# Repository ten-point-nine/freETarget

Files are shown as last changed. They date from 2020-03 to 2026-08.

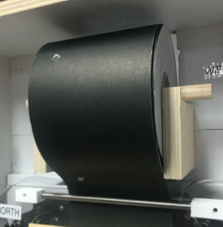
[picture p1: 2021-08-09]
Documentation/Pictures/Witness Paper Roll.jpg

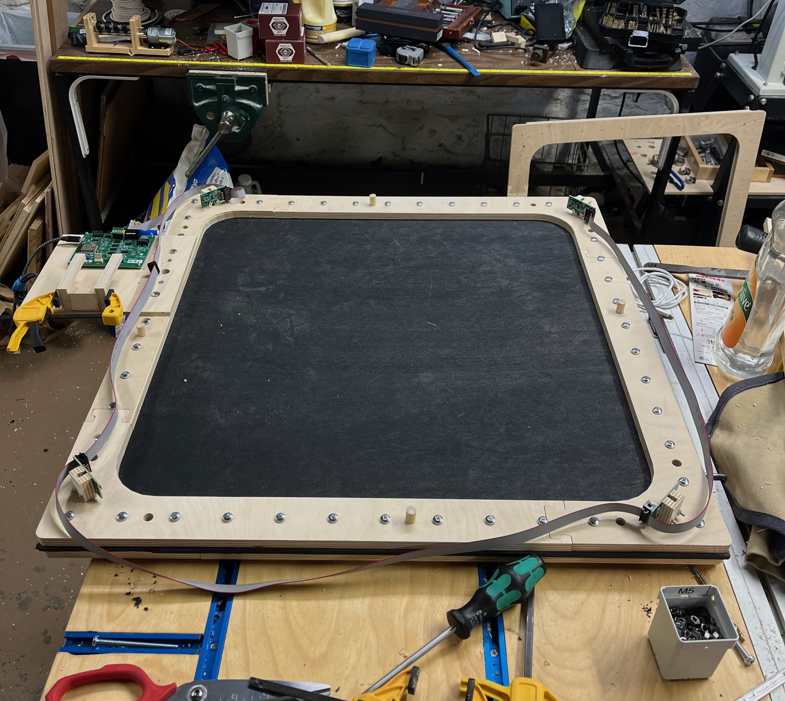
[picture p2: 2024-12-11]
Documentation/Pictures/Illustrations/Pistol Assembly 1.png

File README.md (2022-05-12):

# freETarget

**What is freETarget?**

freETarget is an 'electronic target' (or E-Target) for small calibre (air) rifles and pistols. It uses microphones arranged around the target card to detect the impact of the bullet on the paper and then calculates the point of impact using triangulation. The basic principles are detailed in 

It does this using relatively inexpensive electronics, based around the Arduino open-source ecosystem. This means you can have your own E-Target for a lot less than the current commercial offerings. How much exactly depends mostly on you own skill and effort. You can source and build everything yourself including the electronics and have a system running for around $200. If you want to have the electronics ready made, this price will be around $300.

And yes, we realize this isn't exactly 'free', but it's still pretty cheap for such a system.

Check out the BOM for the electronics to get a feel for the costs of that part. The enclosure can be as expensive as you want, in it's cheapest form it can be made of sturdy cardboard!

The second part of the solution is actually free and consists of the excellent frETarget software. This software offers incredible functionality and is maintained free of charge! See something you want changed, it's open-source, feel free to improve (and please share back).

**How do I work with the firmware?**

The firmware is written for an Arduino and the Arduino IDE.  This makes it pretty accessible for anybody in the world.  Lots of aftermarket support

The software starts with freETarget.ino.  This is the startup and main control loop.  The other files, gpio.ino are helper files to interface to various hardware elements.  The heavy lifting is done buy the file compute_hit.ino.  

**I just want to build and upload the latest firmware**

You can always download the latest firmware from https://www.free-e-target.com/downloads and upload the HEX file through the freETarget PC software. 

If you want to build from source, just open the freETarget.ino file located in the freETarget subfolder in the Arduino IDE. You won't see any code, but hitting Verify and upload will work just the same.

**I want to work on the PC source code**

Great! The PC software is wrtten in C# using Visual Studio.  You can download a free version from the Microsoft web site.  

**How do I work with the hardware?**

The hardware is maintained in the electronics subfolder of the GIT repository and is developed in KiCad. Download and install KiCad EDA to work on the schematics and PCB's.

**Tell me more**

The documentation folder contains all of the documents that have been created for this project.

   **Theory of Operation** details the algorithm and hardware used to detect the shot location

   **Building freETarget** is the instructions for assembling a target

   **Mechanical Folder** contains all of the mechanical drawings to complete your system

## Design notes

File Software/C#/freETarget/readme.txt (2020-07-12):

freETarget software

the program uses 2 external libraries: System.Data.SQLite and PdfSharp. Use Visual Studio NuGet Packages tool to import these 2 libraries into the workspace.
The Setup project will build an installation kit for the software.

PC software for displaying data from the electronic target received over the COM serial port. The PC connects to the target using a USB cable. 
-	Supports air pistol and air target events; practice, match and final
-	Displays score in integer or decimal format
-	Configurable 40 or 60 shots matches
-	Configurable display of shots – all shots in the session or just current series
-	Big time display for the current session
-	Mean Point of Impact (MPI) , Mean radius and group size with direction arrow indicating each shot’s position; drawing of the MPI and mean group  on the target
-	Calibration control of shots
-	Zoom of target display
-	Numbering of shots; last shot has a distinct color for easy recognition
-	Virtual Range Officer – voice commands in the final events
-	Journal where all the sessions are automatically saved; sessions are saved per user
-	Each session can be loaded in the main window; the session’s series can be inspected by clicking the grid display
-	Statistical graphs for all sessions in an event type
-	Each session has its own diary entry page for noting impressions of the training
-	PDF generated for each session with all the results
-	Visually distinctive “not connected” status
- 	Variable target distance (3 to 10 meters)

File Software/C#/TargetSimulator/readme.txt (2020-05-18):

The target simulator is created to simulate the arduino sending shot commands over a serial port (USB).
In order to simulate the conection between 2 ports, a virtual null-modem cable software is to be used : i recomend com0com from http://com0com.sourceforge.net/. At installation, choose to setup 2 paired COM ports.

After install, connect the TargetSimulator to one COM, and freETarget software to the other and than use the buttons in the simulator to send shot commands.

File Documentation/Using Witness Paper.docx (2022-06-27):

# freETarget

Application Note: Using Witness Paper

SUMMARY

This application note describes how to add witness paper to freETarget.

- Witness Paper
- Paper Feed
- Switches
- Configuration
- Bill of Materials

INTRODUCTION

freETarget has the facility to add witness paper drive to the basic target. Witness paper ensures that there is always a complete target to put holes into and get a reliable shot location.

Using witness paper requires four parts:

- Witness Paper Holder and Guide
- Paper Feed
- Paper Feed Switches
- Software Configuration

Each of these topics are discussed separately

WITNESS PAPER and GUIDE

Witness paper comes in two widths; 90mm and 165mm. The 90mm width is typically used for rifle shooting, while the 165 is for pistol events. The choice is up to the user, but 90mm is more than sufficient to fill in the black portion of a pistol target.

An example of a paper holder is shown in Figure 1. The witness paper holder is wide enough to fit a 92mm paper roll. This provides a standard 90mm roll with 1mm of clearance on each side. In this example, the witness paper rolls under a round (5mm) bar that lines the paper up with the target. Because of this bar, the witness paper is on a free rolling mount that lets the roll adjust its position as the paper is used.


Figure 1: Witness Paper Holder

PAPER DRIVE

The paper drive in Figure 2, 3, and 4 is made from several components.

- Frame
  - Base
  - Left Pinch Roller Bearing
  - Right Pinch Roller Bearing
- Motor
- Coupling
- Drive Shaft
- Pinch Rollers
- Tear Bar

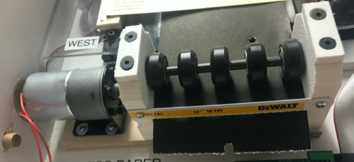
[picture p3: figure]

Figure 2: Paper Drive Assembly

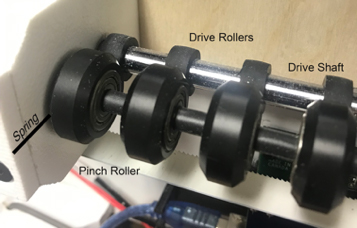
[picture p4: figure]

Figure 2A: Drive Rollers

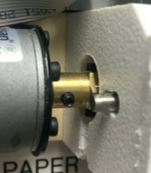
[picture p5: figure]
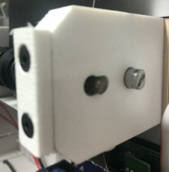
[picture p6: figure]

Figure 3: Motor Coupling | Figure 4: Pinch Roller Bearings

Construction

In this example, the base is made from 1/4” plywood, and the pinch roller bearings from PVC plastic.

Construction begins by sizing out the base plate needed to hold the motor, left pinch roller bearing, paper, and right pinch roller bearing. In this example the base plate is 18cm x 5cm,

Next the pinch roller bearings are cut from PVC plastic. PVC was chosen since it is naturally slippery and does not need any lubricant. In this example the bearings are 50mm x 65mm

Begin by locating the motor and motor mount on one side of the base plate. Next, mark the place where the drive shaft touches the bearing plates. Drill the holes for the drive shaft as seen in Figure 3.

The drive rollers purchased from Amazon come with a 6 mm arbor. Drill or cut the arbor out leaving just the rubber wheel. Slide the rubber wheel onto the 8mm drive shaft, this will require some force, but it can be done. Test fit the motor, drive shaft, and drive rollers. Assemble the pinch rollers onto the shaft and mark where they will need to be to fit against the drive shaft. Drill an oblong hold into both pinch roller bearings. Note that Figure 4 shows a slotted hole for the pinch rollers. This is done so that the pinch rollers can be pressed against the drive shaft when assembled.

Drill a hole through both pinch roller bearings for the spring to fit into.

Assemble the witness paper drive.

Testing

Cut a small length of witness paper and insert it into the drive. The slotted hole for the pinch rollers should be long enough that you can move the pinch roller away and slide in the paper. When the pinch rollers are in contact with the drive rollers the witness paper should not be able to be moved.

Apply power to the motor, does the witness paper move easily? You may find that the drive shaft binds in the mounting plates. If this happens, loosen the bolts holding the plates to the mount by ½ turn.

Wiring

A control to drive a witness paper roller is provided by the Motor Drive Pin. This pin provides a ground connection through a MOS-FET transistor.

The user has the option of turning on a DC motor for a period of time, or issuing pulses to a stepper motor controller. The number of pulses and the pulse duration is available from the setup page on the PC program. The duration of the motor control will be installation dependent and found by trial-and-error

A typical connection for a DC motor is shown in Figure 2.

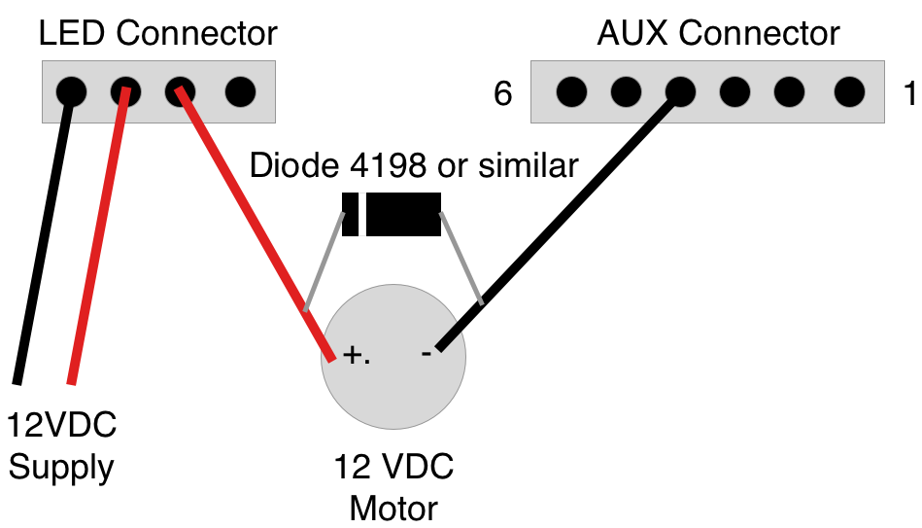
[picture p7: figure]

Figure 2: DC Motor Connection

IMPORTANT – Stepper Motor Control

The software provides the ability to pulse a stepper motor circuit for a given number of pulses and periods. The user must add a stepper motor interface such as A4988 available from Amazon to convert from pulses to motor phase drive

IMPORTANT – Feed Direction

The feed direction is determined by the motor polarity and the assembly of the parts. If the paper feed is backwards to the target, reverse the positive and negative motor leads.

PAPER FEED SWITCHES

The witness paper drive has provision for paper feed switches to advance the paper when loading. Figure 5 shows the switches, and Figure 6 shows the location on the DIP header. Figure 7 is a simple schematic of the switches and connection.

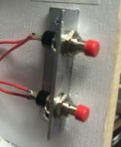
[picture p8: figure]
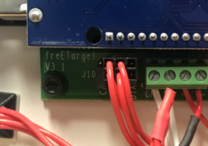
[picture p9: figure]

Figure 5: Paper Feed Switches | Figure 6: Wiring Connector – Uses DIP connection A and B

Figure 7: Switch Diagram

SOFTWARE CONFIGURATION

The witness paper needs the following configurations to be set as shown in Table 1

Table 1: Witness Paper Settings

Setting | Description | Typical Values
DC Motor
PAPER_TIME | Duration motor is on to advance paper | 500 ms (50)
Stepper Motor
STEP_COUNT | Number of steps to issue to motor | 25
STEP_TIME | Stepper motor ON time | 5
Switches
MFS | 0-16 Upper Switch | 1 – Paper Feed

BILL OF MATERIALS

Most of the materials on this list were obtained from Amazon simply for convenience.

Part | Description
Base | ¼” Plywood or similar
Left Roller Bracket | ½” PVC or similar
Right Roller Bracket | ½” PVC or similar
Pinch Roller Spring | 5mm dia x 50mm long Ballpoint pen springs could be used instead
Fasteners | Various screws to fit
Part | From Amazon.com
12VDC Motor, 110 RPM | https://www.amazon.com/gp/product/B08D3SSG55/ref=ppx_yo_dt_b_asin_title_o09_s00?ie=UTF8&psc=1
Motor Mount | https://www.amazon.com/gp/product/B089W6DCGV/ref=ppx_yo_dt_b_asin_title_o09_s00?ie=UTF8&psc=1
6-8mm coupling | https://www.amazon.com/gp/product/B06X99P2XK/ref=ppx_yo_dt_b_asin_title_o09_s00?ie=UTF8&psc=1
Pinch Roller | https://www.amazon.com/gp/product/B088BXFT44/ref=ppx_yo_dt_b_asin_title_o05_s00?ie=UTF8&psc=1
Drive Roller | https://www.amazon.com/gp/product/B088BXFT44/ref=ppx_yo_dt_b_asin_title_o00_s00?ie=UTF8&psc=1
8mm x 100 mm Drive Shaft | https://www.amazon.com/gp/product/B082ZNXBWS/ref=ppx_yo_dt_b_asin_title_o00_s00?ie=UTF8&psc=1
5mm x 100mm Pinch Roller Shaft | https://www.amazon.com/gp/product/B082ZNXBWS/ref=ppx_yo_dt_b_asin_title_o00_s00?ie=UTF8&psc=1
Feed Switches, Push Button Normally Open | https://www.amazon.com/Twidec-Colors-Momentary-Pre-soldered-PBS-110-X6C/dp/B07RPS2ZY3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

WHERE TO BUY WITNESS PAPER

Europe

Kreuger Targets. https://targets.krueger-shops.eu

North America

Orion Systems: Paper Roll for Athena NC Models (orionscoringsystem.com) (http://www.orionscoringsystem.com/orion/Product.aspx?ProductID=61)

Elite Scorer: Electronic target, Electronic targets shooting, Target scoring system (elitescorer.com) (https://www.elitescorer.com/ElectronicScoring-shooting.aspx?curr=USD)

Targets Canada: http://www.targets.ca/products/targets-target-systems-and-accessories

Make Your Own Witness Paper

For true Do-It-Yourself people, there are alternatives to commercially available witness paper

Black wallpaper – Available locally in paint supply stores

Black kraft paper – Example Amazon, https://www.amazon.com/RUSPEPA-Black-Kraft-Paper-Roll/dp/B07MNVSB16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

Heat treated cash register paper – Use standard cash register paper and iron it to turn it black

Cut down witness paper – Cut 90mm witness paper in half using a band saw or similar tool

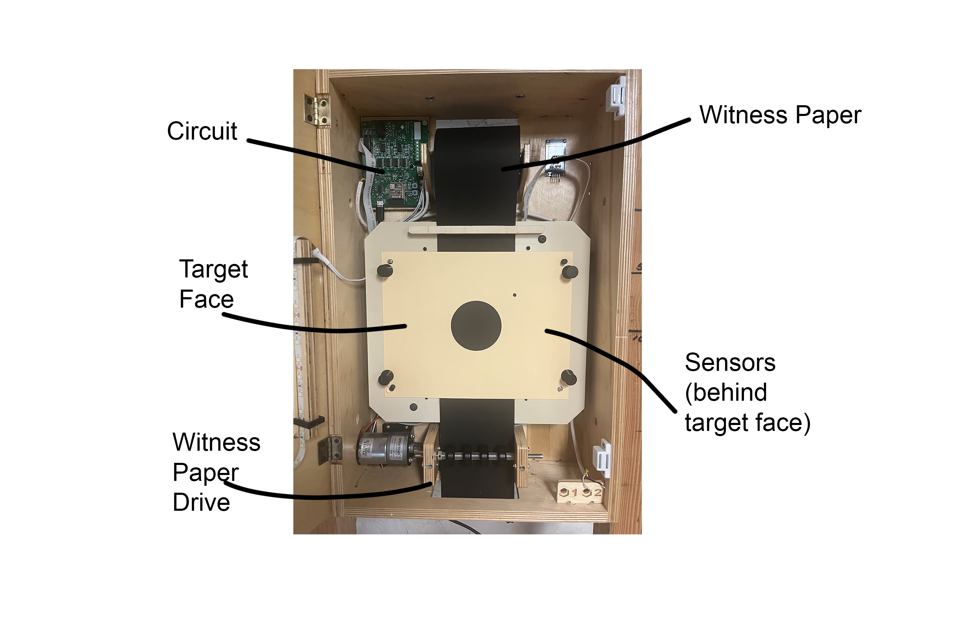
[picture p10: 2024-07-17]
Documentation/Pictures/Target Schematic.png

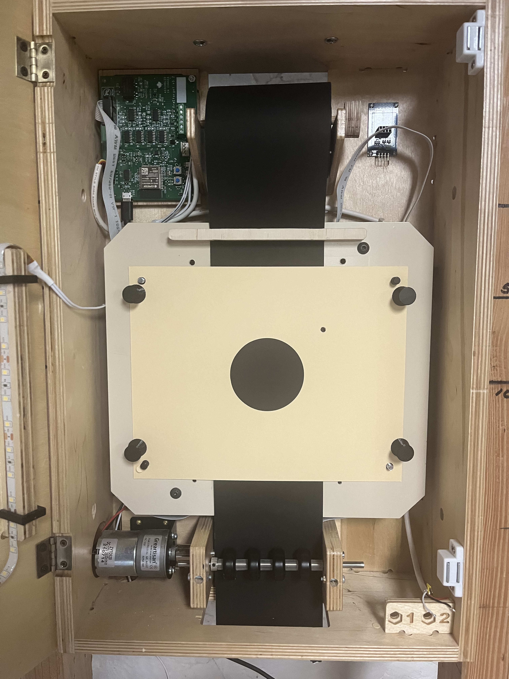
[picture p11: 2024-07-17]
Documentation/Pictures/Schematic.jpg

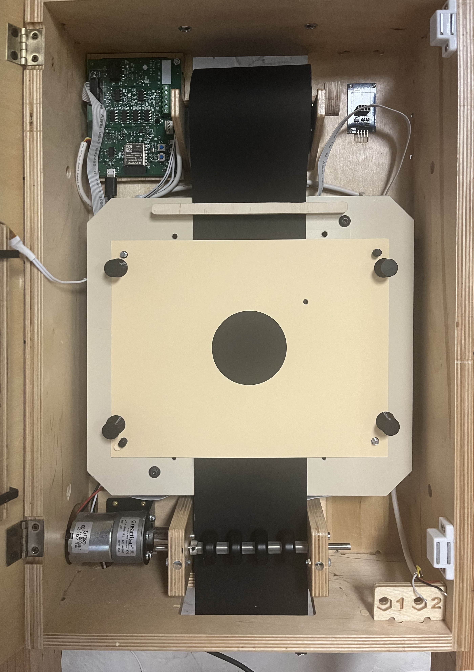
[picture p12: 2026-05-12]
Documentation/Pictures/Schematic.png

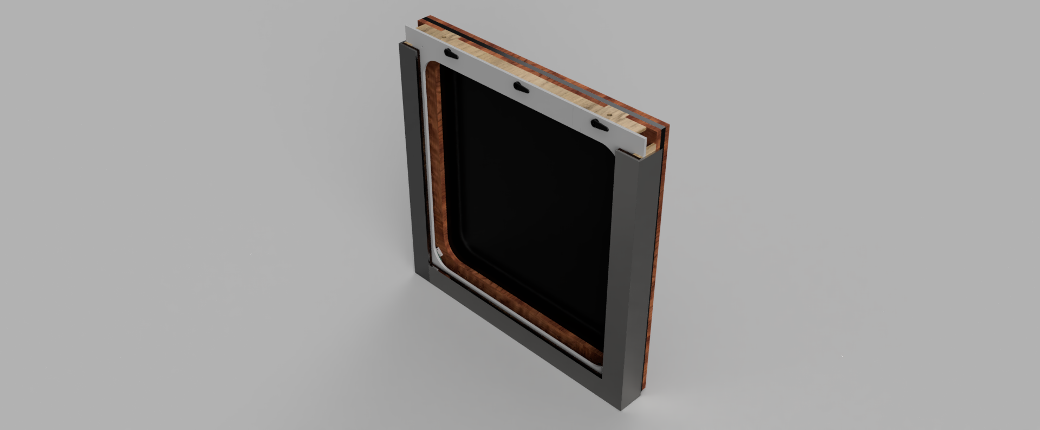
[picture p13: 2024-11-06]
Mechanical/CAD Files/50 Meter Pistol Rendering.png

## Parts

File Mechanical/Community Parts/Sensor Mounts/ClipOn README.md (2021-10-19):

# Clip-on Target and Sensor holder

These group of STL files makes it easy to position the target paper perfectly relative to the sensors. The target-holder can be clipped on the sensor holders and holds the paper very close to the sensors, which is ideal for correct detection. All the parts are small enough to be printed on a cheap small 3D printer.

Print in PLA:
4 x sensorholder
1 x target holder bottom
1 x target holder left
1 x target holder right

Then mount the sensors on the holders, after that clip everything together. To make the three target holder pieces to fit snugly, you may have to use some sandpaper.

If you want to edit the 3D CAD model, you can open „Target holder Neu v35.f3d“ in Fusion360.

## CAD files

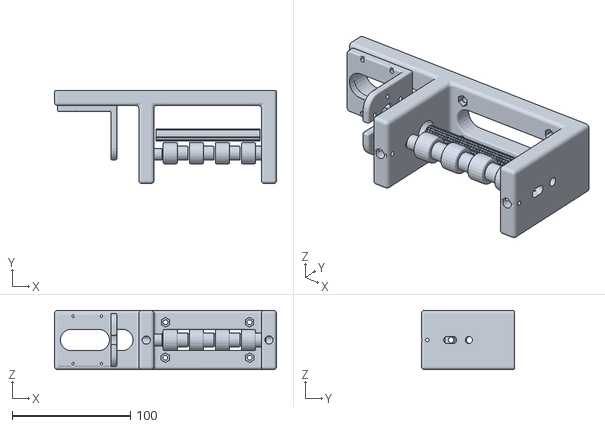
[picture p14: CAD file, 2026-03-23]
Mechanical/CNC/Metal - Plastic/Witness Paper Complete.stl
187.7 x 78.7 x 50.0

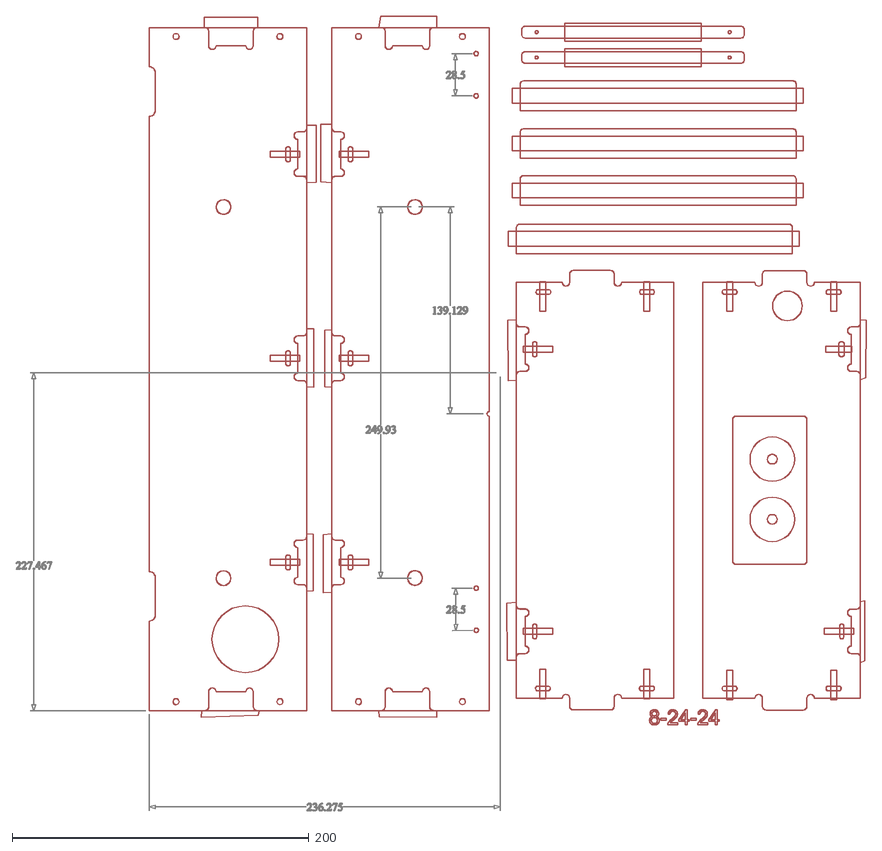
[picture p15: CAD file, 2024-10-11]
Mechanical/CNC/12mm Panel/12mm Panel.dxf
572.5 x 535.4

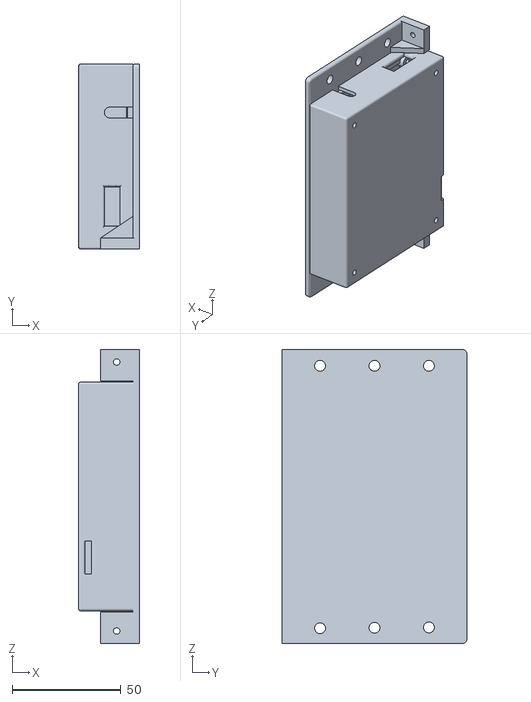
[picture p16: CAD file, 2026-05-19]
Mechanical/CNC/50m Pistol/50m Pistol.stl
28.0 x 85.0 x 135.0

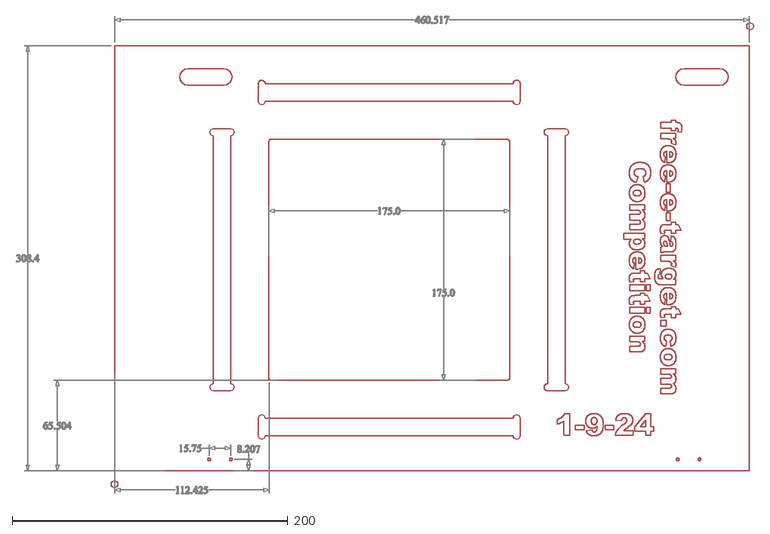
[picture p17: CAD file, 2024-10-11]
Mechanical/CNC/6mm Panel/6mm Panel Door.dxf
534.8 x 346.3

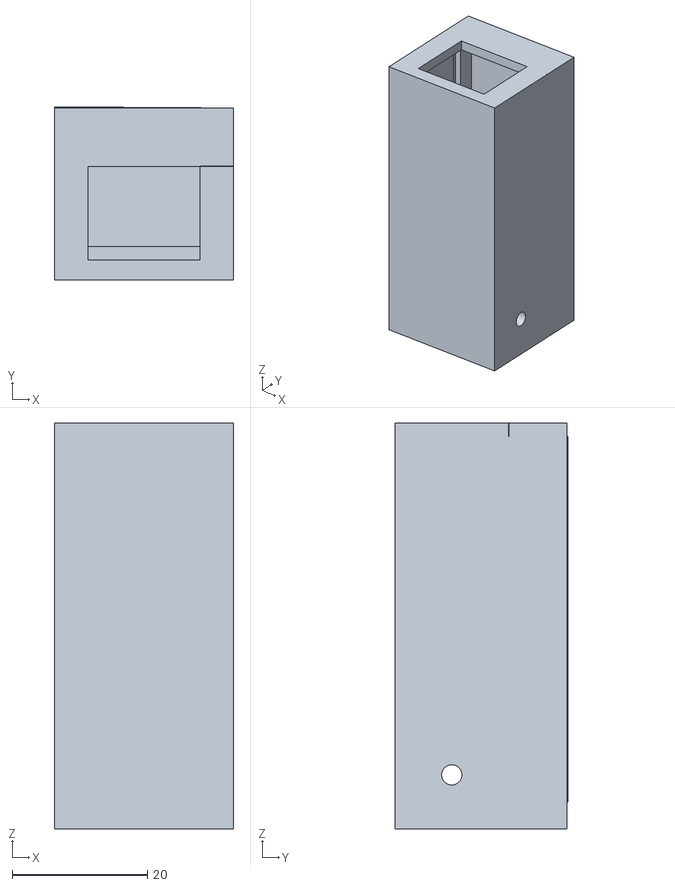
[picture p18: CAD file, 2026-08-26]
Mechanical/CNC/Metal - Plastic/Ethernet Housing 2.stl
26.5 x 25.6 x 60.0

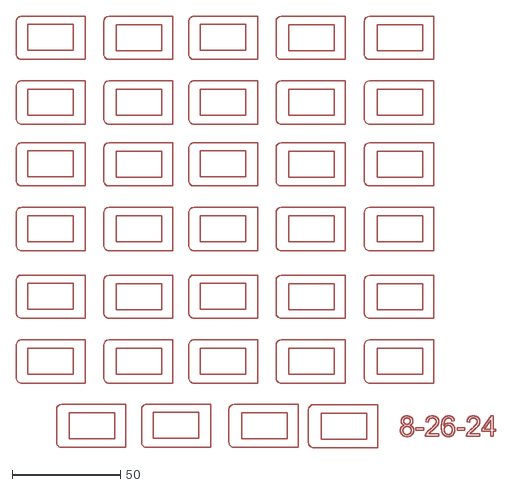
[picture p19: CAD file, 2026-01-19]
Mechanical/CNC/Piece Parts/Cable Guide/Laser Cable Guide.dxf
221.5 x 199.3

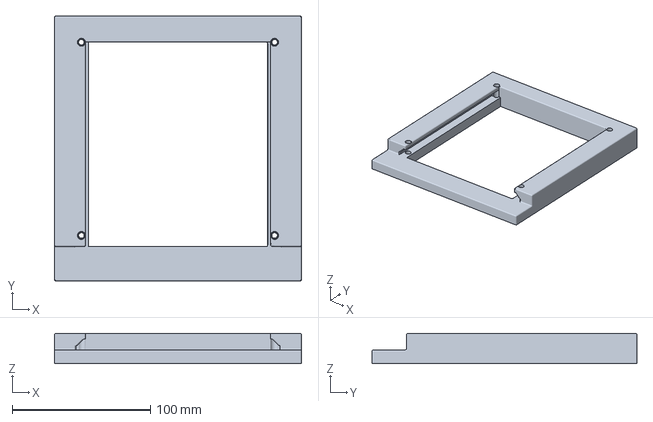
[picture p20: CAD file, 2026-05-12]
Mechanical/CNC/Piece Parts/Pellet Trap Guide.3mf
179.0 x 192.0 x 22.0 mm

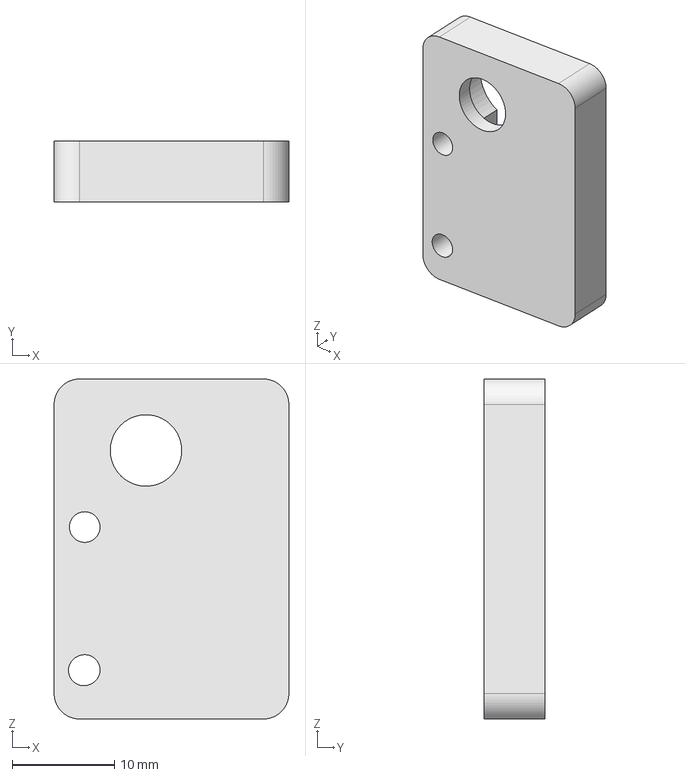
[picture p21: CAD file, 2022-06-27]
Mechanical/CNC/Piece Parts/Sensor Mount/Sensor Cover.step
23.0 x 6.00 x 33.3 mm

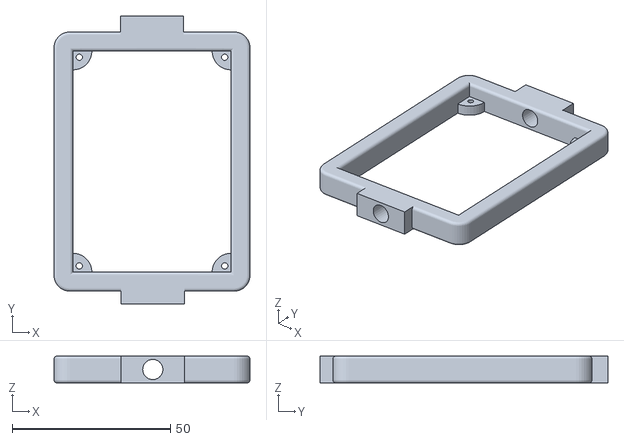
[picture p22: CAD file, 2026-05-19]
Mechanical/CNC/Traffic Lights/Roll.stl
62.0 x 91.0 x 8.50

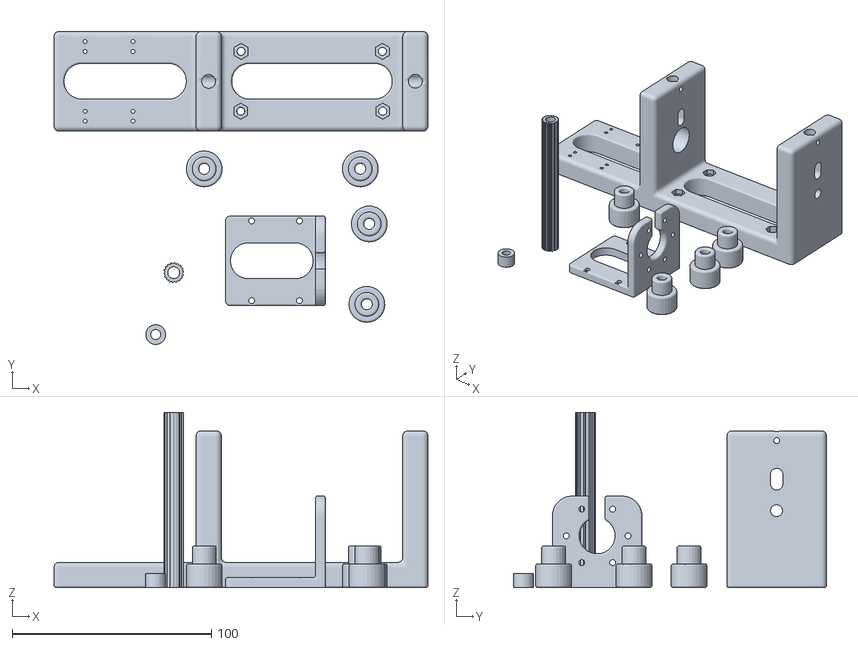
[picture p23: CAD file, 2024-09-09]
Mechanical/CNC/Witness Paper Transport/3D Witness Paper Drive.stl
187.7 x 157.1 x 88.0

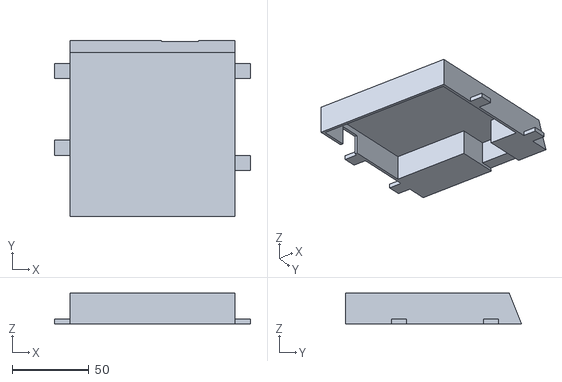
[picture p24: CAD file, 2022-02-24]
Mechanical/Community Parts/Piece Parts/ArduinoCover.stl
128.0 x 115.0 x 20.0

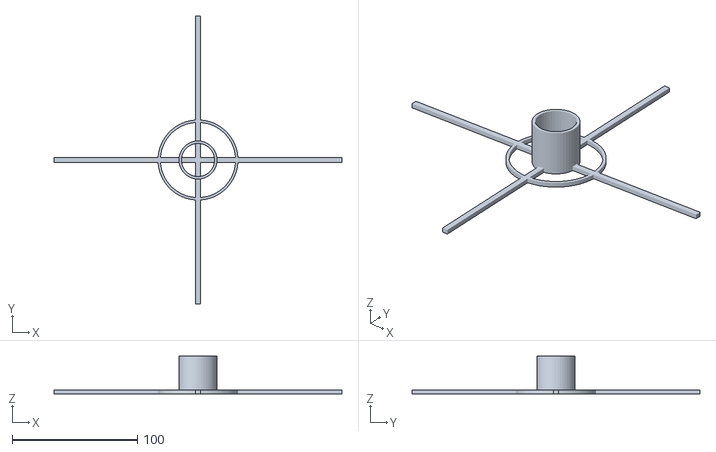
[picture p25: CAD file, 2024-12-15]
Mechanical/Community Parts/Sensor Mounts/Siuscalibration.stl
230.0 x 230.0 x 30.0

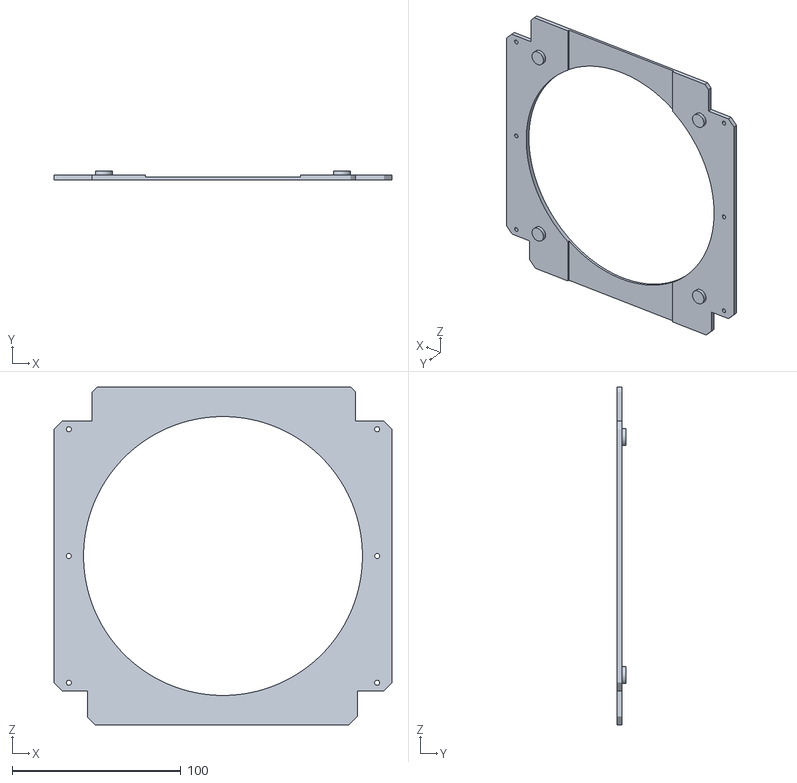
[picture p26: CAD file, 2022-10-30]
Mechanical/Community Parts/Target Holders/RaamV17.stl
200.0 x 5.50 x 200.0

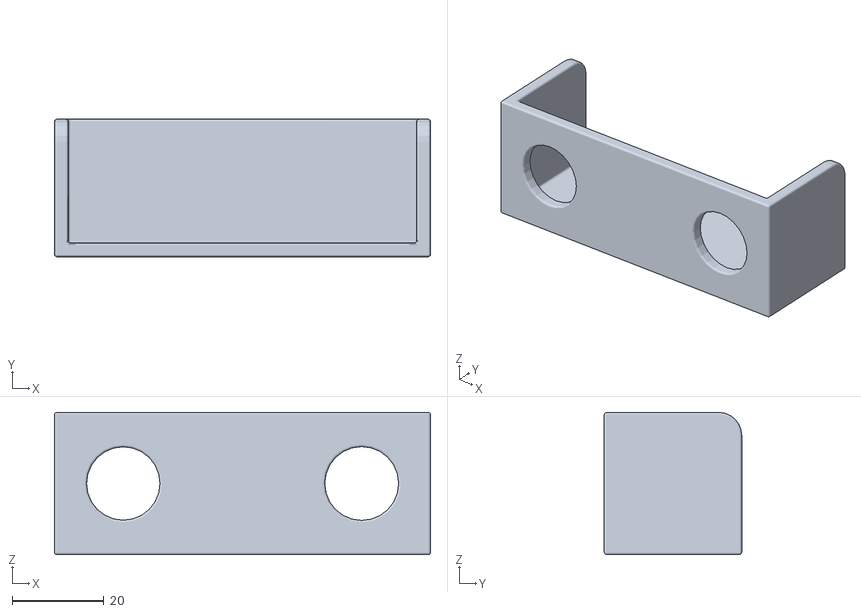
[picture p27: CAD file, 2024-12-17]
Mechanical/RapidFireSupport.stl
82.0 x 30.0 x 31.0

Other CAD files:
Mechanical/Community Parts/Rapid Fire Traffic Lights.3mf
Mechanical/CNC/50m Pistol/corner.stl
Mechanical/CNC/6mm Panel/6mm Panel Back.dxf
Mechanical/CNC/Metal - Plastic/Pellet Holder 2.stl
Mechanical/CNC/50m Pistol/50m Corners.stl.cxprj.3mf
Mechanical/CNC/50m Pistol/50m Pistol Clamp.skp
Mechanical/CNC/50m Pistol/50m Pistol Frame Cut.skp
Mechanical/CNC/50m Pistol/50m Pistol North Face Cut.skp
Mechanical/CNC/50m Pistol/50m Pistol North Sensor Mount.skp
Mechanical/CNC/50m Pistol/50m Pistol PCB Case 2.iges
Mechanical/CNC/50m Pistol/50m Pistol PCB Cover.skp
Mechanical/CNC/50m Pistol/50m Pistol PCB Cover.stl
Mechanical/CNC/50m Pistol/50m Pistol Target Stop.skp
Mechanical/CNC/50m Pistol/Cable Clamp.stl
Mechanical/CNC/50m Pistol/PCB Case.stl
Mechanical/CNC/50m Pistol/PCB Cover.stl_1.cxprj.3mf
Mechanical/CNC/50m Pistol/Plastic Parts x 2.3mf
Mechanical/CNC/50m Pistol/Plastic Parts.3mf
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

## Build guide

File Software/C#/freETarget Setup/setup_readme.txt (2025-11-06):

Android:
After the installation is complete, please go to the selected freETarget installation folder, and in the "drivers" subfolder, run the Arduino USB driver setup exe. 
Run the "dpinst-amd64.exe" file for 64 bit systems, or "dpinst-x86.exe" for 32 bit systems.

ESP32:
After the installation is complete, if Windows does not recognize the ESP32 board, go to drivers\ESP32 subfolder and run the ESP32 driver CDM212364_setup.exe
To upload the firmware, you need to install the uploaded tool ESPTOOL. There are multiple steps:
1)	Install python from https://www.python.org/downloads/
2)	When installing python, make sure to select the option to install the PIP tool 
3)	Open a command window and type: „pip install "esptool<5" ” 
4)	Make sure the esptool.exe file exists in the python\scripts folder and that it was added to the PATH environment variable

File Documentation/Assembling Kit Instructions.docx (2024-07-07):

# freETarget

Application Note: Assembling freETarget Competition and Club

CAUTION

The flatpack is made from unfinished wood.

- Wear eye protection
- Use caution when assembling to avoid splinters

When using freeTarget:

- Wear eye protection
- Maintain a safe distance
- Do not shoot into any areas except the open target areas.

The freeETarget project or contributors will not be responsible for any injuries when using this target of it’s components.

Target shooting can be dangerous so apply caution in everything you do.

Thank you for purchasing the FreeEtarget Club or Competition kits.

Visit free-e-target.com for more instructions

Club Target Instructions: https://free-e-target.com/assembling-the-freetarget-club/

Competition Target Instructions: https://free-e-target.com/technical-documentation/assembly/assembling-the-freetarget-flatpack-2/

Included

- Circuit
- Housing
- Hardware

Not Included

- Glue
- Lights & Power Supply
- Witness Paper

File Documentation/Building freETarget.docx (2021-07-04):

# freETarget

Application Note: Building freETarget

SUMMARY

This application is a one document starting point for building freETarget from scratch. The document is organized as:

- Building the target frame
- Installing the circuit
- Downloading the PC software
- Starting up
- Trouble shooting

The example shown here is made from plywood and plastic. You may choose to assemble it with different materials.

REQUIRED

- freETarget circuit
- Internet connection
- Hand tools
- Patience

INTRODUCTION

freETarget is an open source project to provide shooters with a low cost electronic target. One of the objectives is that the materials needed to make the target will be sourced from around the world and will be dependent on what is available locally. To do this, much of the initiative to tailor the construction to your skills and parts availability is comes from people like you.

This application note provides the basics to construct freETarget. Read all of the instructions before starting. You may have to change materials or operations based on what you have at hand.

BUILDING THE TARGET FRAME

The target frame holds the target and sensors in the correct position to record the shot. The assembly can be made of anything local, such as

- Plywood
- Plastic
- Metal
- 3D Printing
- Cardboard

A side view of the target assembly is shown in Figure 1.

Item | Description | Notes
Front Face | Face plate used to protect the circuitry and sensors | Should be made from a material that will withstand a pellet strike
LED Illumination | LED lightning strip attached to the front face to light the target | Can be obtained from a local hardware store
Face Sensor | Duplicate sensor mounted to the front face to detect a shot to the front face | Operation dependent on the material used for the front face.
Sensor | Four microphones located around the target to detect the shot | Pay careful attention to the locations stenciled on the circuit board. Sensors may be located anywhere between the front face and pellet trap.
Flat Cable | Routes from the Arduino board to the sensors | End marked with an A is the Arduino end of the cable
High Pass Filter | Small board that installs between the flat cable and Arduino | Used to attenuate report from gun
Sensor Block | Mounting block to hold sensor parallel to direction of shot | May be any non-conductive material.
Sensor Support | Back frame to hold the sensors in the correct location and orientation
Target | Target | May be located anywhere between the front face and pellet trap.
Pellet Trap | Pellet Trap | Used to collect pellets after shooting. May be omitted if shooting on a range with a berm.
USB Cable | Fifteen meter USB cable | May be purchased locally or on line

IMPORTANT

The orientation of the sensors NORTH to WEST is as seen looking from the firing point through to the pellet trap. If you choose to mount the sensors behind sensor support the orientation will appear reversed.

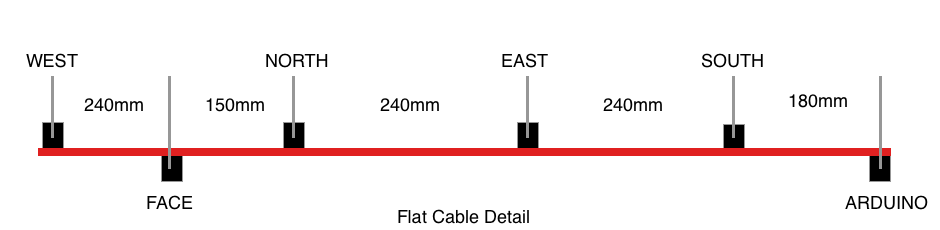
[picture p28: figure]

Figure 1: freETarget Layout

The only thing that is important is that the sensors be mounted at the corners of the target at a distance of 230 mm sensor-to-sensor. Figure 2 illustrates the geometry of the sensors as viewed from the firing point

Figure 2: Sensor Geometry

The example shown in this Application Note is made from plywood and plastic. Figure 3 is an illustration of a target holder. Figure 4 shows a sample sensor block

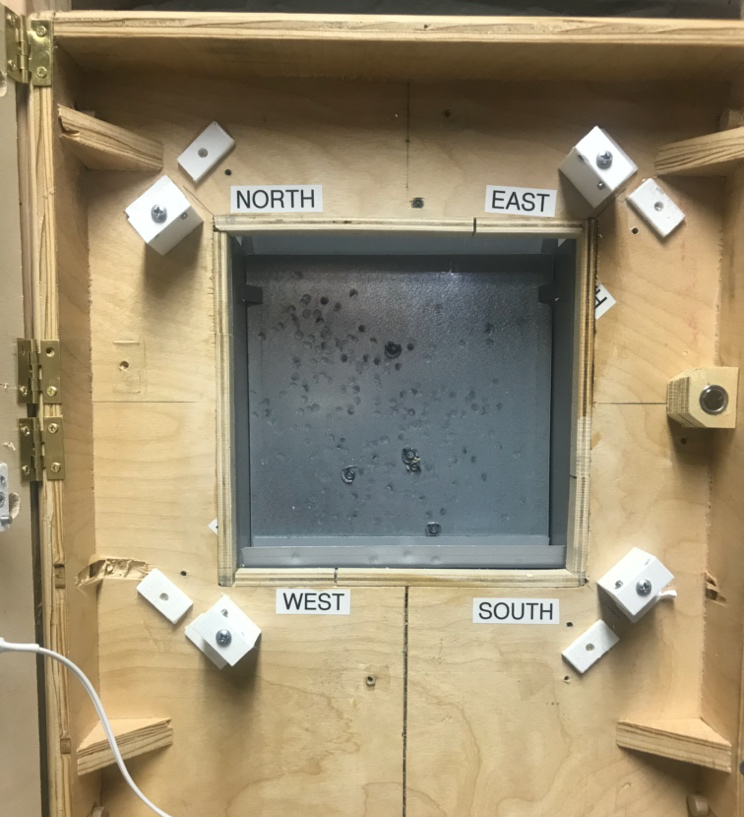
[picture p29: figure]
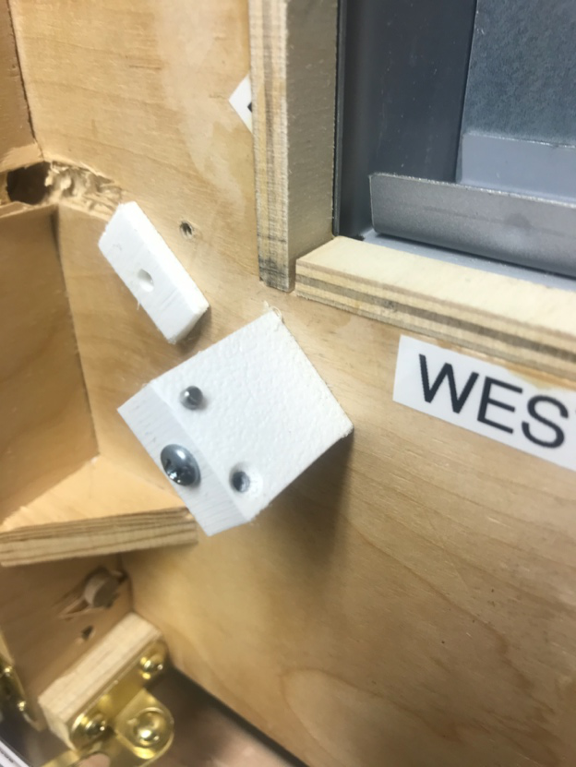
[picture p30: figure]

Figure 3: Plywood Target Holder | Figure 4: Sensor Block

Begin by cutting a rectangular frame and square target hole. The frame can be as large as you like, and the target hole has to be big enough to hold the target in place. The stencil given in Appendix A may be used to locate the parts.

IMPORTANT

You may need to scale the printed stencil for your printer. The 50mm reference is provide for this purpose.

The sensor mounting blocks are rectangular blocks of plastic 12mm x 25 mm x 27mm. Yours can be larger or smaller or made of any non-conducting material that you have available. Drill two holes in the top of the sensor block to mount the sensor boards (See Figure 5).

Attach the sensor blocks to the target frame in the correct location.

Attach the sensors to the blocks using the mounting holes. Use 5 minute epoxy to attach the mounting blocks to the target holder on the lines marked above. Before the epoxy cures, align the sensors to the diagonal lines and make sure that they are 230mm apart.

Once the epoxy hardens put an additional bead around the base to prevent any movement.

Locate the bullet trap behind the target holder.

INSTALLING THE SENSORS

The next step is to install the sensors.

Note that the sensors are marked

- NORTH
- EAST
- SOUTH
- WEST
- FACE (more about that later)

Install each of the pellet sensors as shown in Figure 5 Sensor Installation

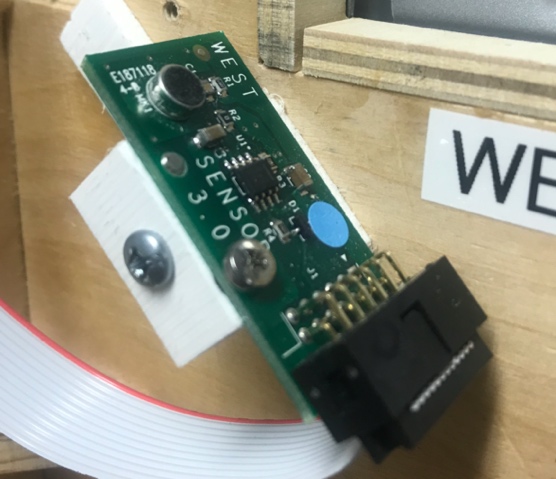
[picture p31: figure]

Figure 5: Sensor Installation

Install the Arduino at the bottom of the target holder and install the flat cable around all of the sensors as shown in Figure 6.

Note the location of the high pass filter. The flat cable is inserted into the pins on the filter board, and the board inserts into the cable socket. Be careful to center the cable into the board and the board into Arduino board. On later versions of the high pass filter the connectors are polarized and the red stripe will be on the opposite side.

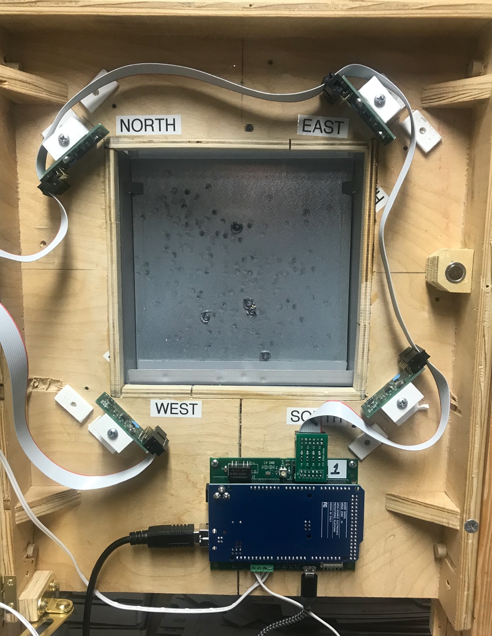
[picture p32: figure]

Figure 6: Flat Cable Installation. Note Location of High Pass Filter

INSTALLING THE FACE SENSOR

The face sensor detects the sound of the pellet striking the case. The face sensor works best on a metal case, and not so well on plastic or wooden structures. Depending on the material used, the face sensor may not work at all.

Attach the face sensor facing the door and with a solid material between the door and the microphone. Figure 7 illustrates the attachment.

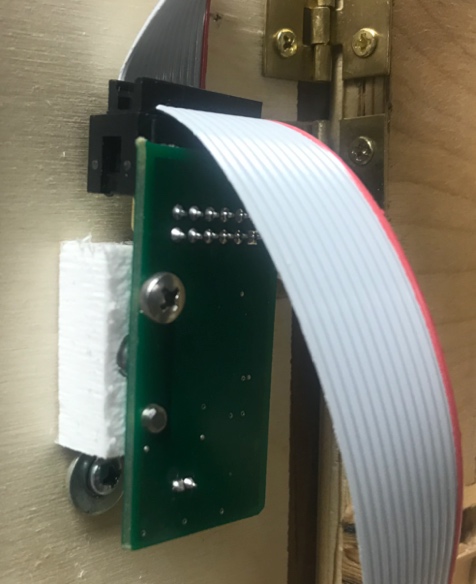
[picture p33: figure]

Figure 7: Face Sensor Installation

DOWNLOADING AND INSTALLING PC SOFTWARE

Click the link below to go to the downloads page

https://free-e-target.com/downloads/

Look for the PC Software section and download the software (Figure 8)

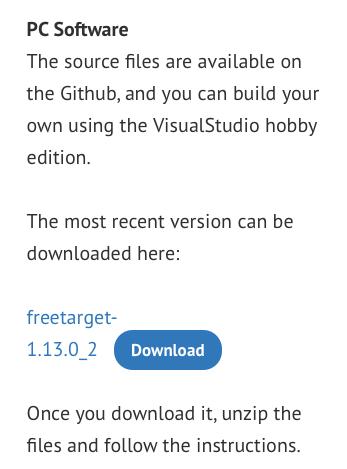
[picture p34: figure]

Figure 8: Download Software

Unzip the software and install on your PC.

Connect the USB cable between the target holder and the PC.

STARTING UP

Launch the PC program and look for the setup icon (GEAR WHEEL) in the upper right corner (See Figure 9)

Figure 9: Setup Icon Location

Enter all of the setup information needed in Figures 9, 10, 11, and 12

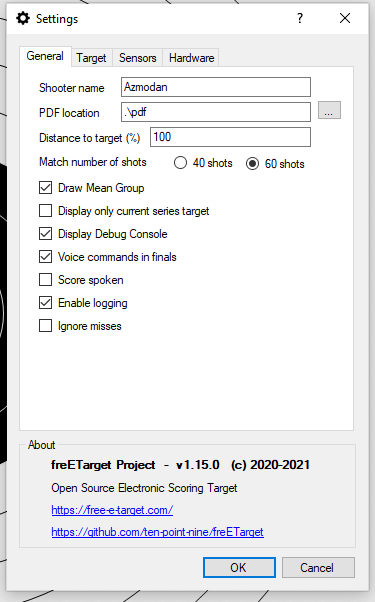
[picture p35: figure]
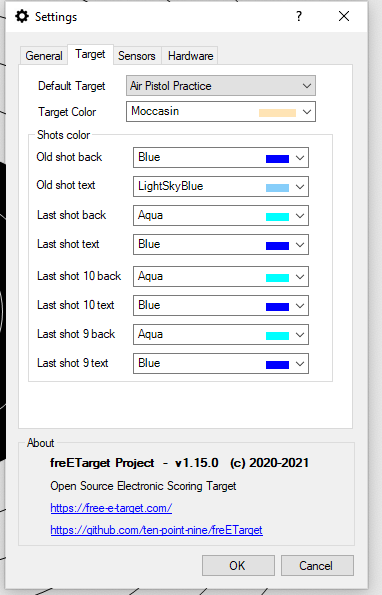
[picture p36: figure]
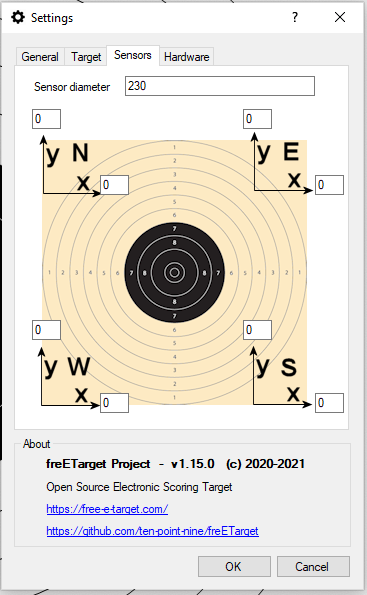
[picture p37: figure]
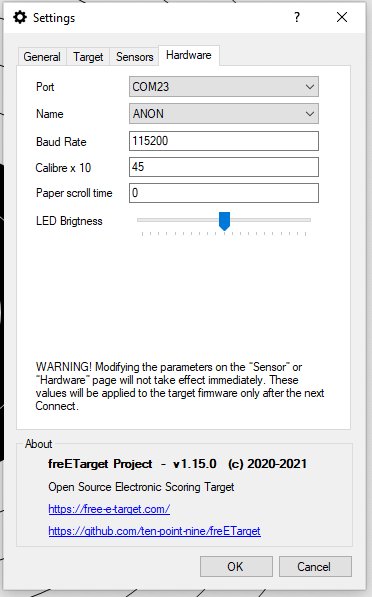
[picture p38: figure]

Figure 10: General Settings | Figure 11: Target Settings | Figure 12: Sensor Adjustment | Figure 13: Hardware Interface

Figure 10: This allows you to enter the shooter name and how information will be stored.

Figure 11: Choose the target you will be shooting against and the colours you will be using.

Figure 12: Fine tune the sensor position to adjust for assembly errors

Figure 13: Interface to the target hardware.

Press to begin a session.

Refer to the Commissioning Instructions from the web site. This will give you a quick summary of how the system is working

TROUBLESHOOTING

The boards are tested before shipment, but a lot can happen between the last test and the first shot. If your system is not working, please follow the trouble shooing guide below before sending an email to freETarget.com

No Shots Registered | - Check that the USB cable is attached - Check that the correct Serial port is set in the setup - Check that the wiring harness is attached to all of the sensors - Tap each of the sensors. Do the three LEDs blink?
Shots show up but in the wrong place | - From the firing line, shoot a blank shot - Do the three LEDs blink? - Yes, set a new trip point - No, Check all of the wiring - Verify that the sensors North – West are in the correct order
The shots show up but rotated 90 degrees | - Verify the order of the sensors and correct
The shots are the mirror image left-right | - The sensors are reversed. Switch the positions of NORTH-EAST and SOUTH-WEST

APPENDIX A – Mounting Stencil

IMPORTANT

This stencil may not print to scale on your printer.

Scale the printer output so that the 50x50 print reference is printed as a 50mm x 50mm square

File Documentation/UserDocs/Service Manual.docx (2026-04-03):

FreeETarget

Service Manual

Version 6.2.1

When using freeTarget:

- Wear eye protection
- Maintain a safe distance
- Do not shoot into any areas except the open target areas.

The freeETarget project or contributors will not be responsible for any injuries when using this target of it’s components.

Target shooting can be dangerous so apply caution in everything you do.

# SUMMARY

This document is the service manual for FreeETarget Version 5. It contains information about the operation for both the target and PC client. For details about the construction of individual components, please see the component documentation.

The document is organized in chapters:

Commissioning | Putting your target in service for the first time
LED Indicators | What to the LEDs mean
Multifunction Switches | Configuring the switches for your needs
WiFi Operation | Setting up the WiFi for your environment
Settings | How to configure the target to your applications
Uploading Firmware | How to put new software into the target
Trouble Shooting | Steps to take to resolve errors

It is suggested that you skim over all of the chapters to get an idea of what FreeETarget is capable of and what are the main elements of the system. Once that is done, start at the introduction and work up to commissioning.

At the end of commissioning, you should be able to shoot into the target and observe the results on the PC display.

If that fails, look into the trouble shooting chapter to make sure that there is no obvious fault that can be quickly fixed.

If all else fails, TeamViewer can be used to remotely log in and observe what is going on.

## Glossary

Term | Description
Circuit | The signal processor to read the sensors and compute the shot location
PC Client | The program the user needs to see their score
Sensor | Microphone assembly to detect paper tearing when the projectile hits the target
Target | The assembly consisting of the circuit, housing, and target holder
TeamViewer | Web based client software that allows remote diagnostics

# INTRODUCTION

FreeETarget is an open source project to make a low cost electronic target that can be used for training and reginal competitions.

The features that FreeETarget provides are:

- Low cost of entry
- Uses a standard Windows PC or laptop
- Precise representation of the score
- Ability to upgrade the software in the field
- Operation with WiFi or USB cables

A FreeETarget installation consists of three major elements:

- Target – - The thing that detects the shot
- Network - The means to transmit the shot information
- Client - The display device

The typical setups are shown in Figure 1:

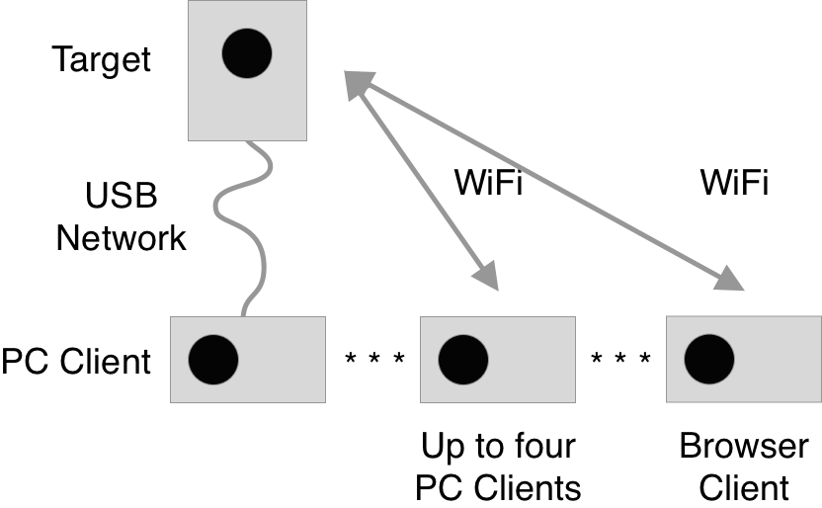
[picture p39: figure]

Figure 1: Installation Methods

The simplest method is to connect the target to the PC client using a 15 meter USB cable. These are readily available on Amazon or the local computer store. The USB connection allows for a direct connection between the two and is resistant to interference.

A more complex installation is to connect the target to the PC client over a WiFi connection. In this case, up to four PC Clients can be connected to the target:

- Shooting display
- Coach
- Parent
- Visitor

Details on the setup of each of these networks is discusses later.

Version 6.1.13 and higher software supports a web browser client to be attached to the PC so that the target can be monitored using a tablet or other browser device.

## PC Client

Instead of a dedicated display module, FreeETarget uses a standard Windows PC or laptop. The computational burden is very low, so any PC with Windows 10 or 11 should work fine.

The software is available from the website free-e-target.com. Look for Technical Support and then downloads.

Once installed, launch the PC client and the display will look like the image shown in Figure 2.

The PC client allows the user to

- Connect to the target to begin a session
- Adjust the image to match the target (calibration)
- Load new firmware into the target
- Look at the inside of the target and debug it’s operation
- Setup the operating modes (ex WiFi network)
- Select an event to shoot
- Verify the software version of the PC client.

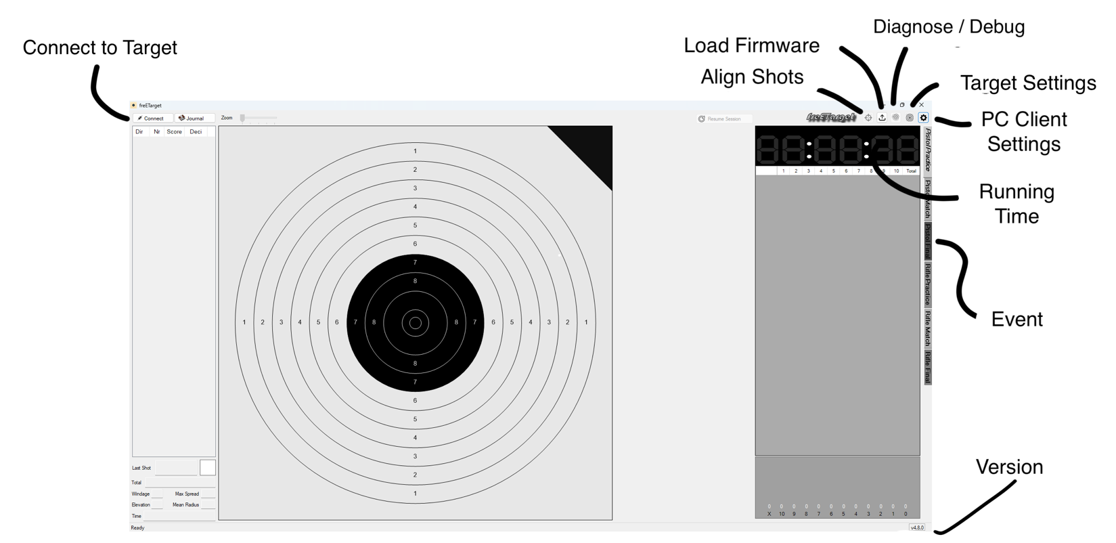
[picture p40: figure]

Figure 2: PC Client Menu Items

## Target

The target is the device that detects the shot location and transmits the score to the PC Client for display.

The target ‘listens’ for the sound of the pellet breaking the paper. The sound radiates out from the hole and reaches four sensors located in the corner of the target. Based on the time delay between when the sensors detect the sound the algorithm computes a shot location.

Since the circuit detects the paper breaking, the sensors cannot detect a shot that penetrates an existing hole. For this reason, if you consistently shoot into the same hole, witness paper is required to present a fresh target for each shot.

Targets can be built from scratch with a circuit and some carpentry, Alternately, the target can be made up from a kit. Regardless of the method used to build the target, all targets contain the elements shown in Figure 3.

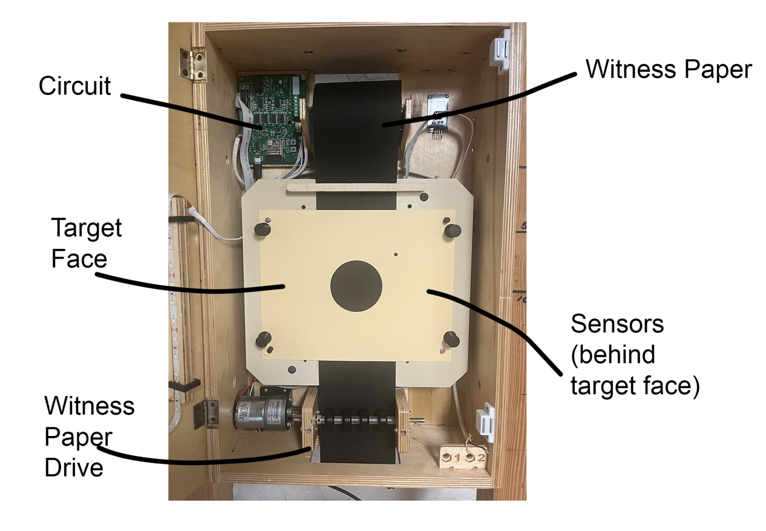
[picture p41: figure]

Figure 3: Typical Target Assembly

## Control Circuit

The control circuit brings together all the electrical components needed to detect the shot. In addition, the circuit provides a user interface to control the operation of the target. The circuit is shown in Figure 4.

The firmware is located in an ESP32 that setup the hardware and eventually transmits the results. The incoming sound from the sensors is conditioned to detect the leading edge of the sound and start timers inside of the processor. Version 5 boards detect the sound at two points and use the time delay between the detections to work ou the slope of the sound and hence accurately time the shot.

Additionally, the circuit board has two switches to control the target without requiring a PC, and the status LEDs are used to display the running state and provides simple diagnostics information.

Temperature and humidity sensors adjust the algorithm to compensate for changes in the speed of sound based on the environment.

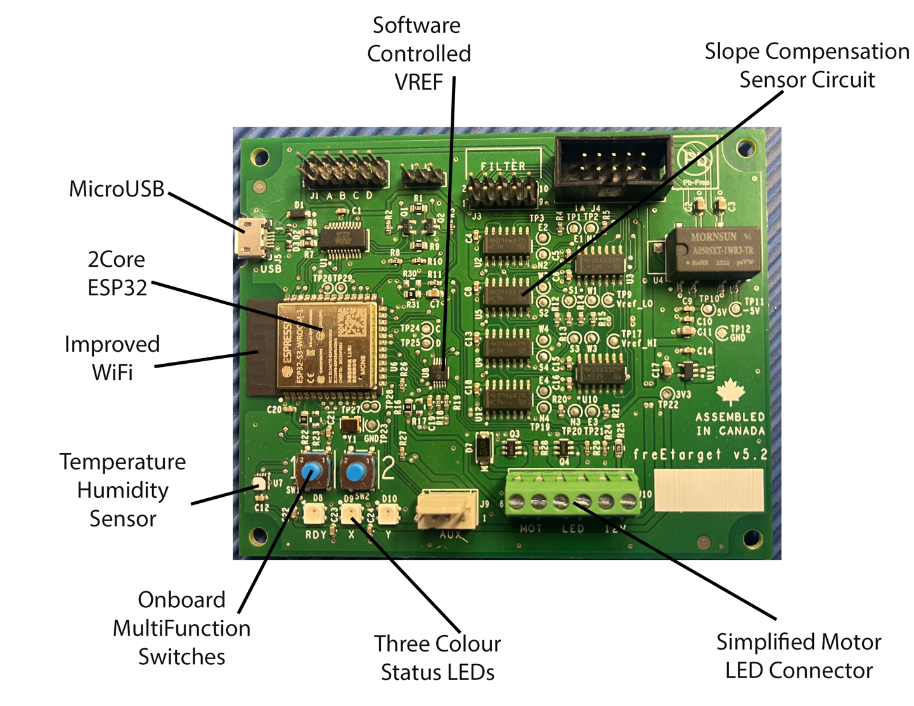
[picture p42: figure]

Figure 5: Circuit Annotation

## USB or WIFI?

All Version 5 boards support WiFi and USB operation. For all practical purposes both USB and WiFi will provide the same target information. The differences are in the details of the connection media. The USB and WiFi are summarized

USB Operation

Needs a purpose. Built 15 meter cable. DO NOT try to attach eight two-meter cables together

Some PCs do not supply enough current to drive the cable and the board. You may need to add a power adapter near the target

USB is needed to reflash the software

Power on diagnostics only operate on the USB connection

WiFi Operation

Operates in both Access Point (easy) or Station Mode (allows internet access)

Software flashing cannot be done over WIFi

Supports up to four connections to each target

Supports a single HTTP client for web server access

It is recommended that the first target installation uses the USB connection, and subsequent ones can be a combination of USB and WiFi.

# COMMISSIONING

Like any complex piece of technology, FreeETarget can be intimidating if not familiar with it’s operation. Commissioning is the sequence of steps that put the system into operation.

The steps to get an operating FreeETarget are

- Gather the tools to complete the installation
- Install the target
- Install the PC Client
- First shots
- Advanced operation

## Gathering the tools

The following are required to begin installing a target system

- freETarget PC Client 4.5 or higher
- Firmware V5.2 or higher
- Target assembly

Network Minimum

- 2 meter USB cable
- 110 or 220 VAC outlet

Preferred

- 15 meter USB cable
- 110 or 220 VAC outlet
- WiFi network

## Install the target

After you have assembled the freETarget into the target holder, inspect the following

- The flat cable is pressed firmly into the sensors and signal board
- There are no kinks or sharp bends in the flat cable.
- All of the sensors are correctly installed North through West
- When using the LED illumination
  - Verify the 12V supply wires are attached to the board
  - Verify that the LED wires are attached to the board
- When using the DC Motor witness paper drive
  - Verify that the 12V supply wires are attached to the board
  - Verify that the motor wires are correctly attached to the board
- When using the Stepper Motor witness paper drive
  - Verify that the stepper motor driver circuit is attached to the multifunction switch connector
- With the USB cable plugged into the PC, turn on the PC
  - Verify that the RDY LED is blinking green (or Blue)
  - Verify that no other LEDs are blinking

## INstall the pc client

Visit the free-e-target.com -> Technical Support > Downloads to obtain the latest PC Client Software

Open the downloaded file from the download folder and install the software

### Setup the PC Client

Launch the PC client and select Application Configuration from the upper right icons (Settings)

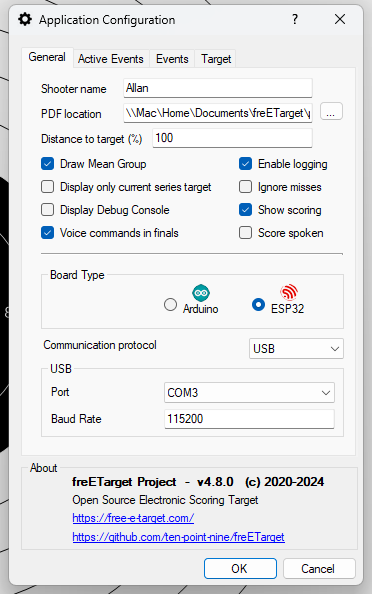
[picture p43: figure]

Figure X: Application Configuration

- Enter the information needed,
- Select ESP32 for Version 5 hardware
- Choose the USB port (for the initial setup)

## FIRST SHOT

Set the target up ten meters from the firing point. Press the CONNECT button on the upper right of the PC client.

- Verify that after a few seconds the PC connects to the target
- The running timer increments or decrements.
- The target colour changes

If the target does not connect then review the connections and settings. Common mistakes include

- USB not configured correctly
  - Check the settings
- USB cable not plugged in correctly
  - Check the USB cables
- Defective USB cable
  - Repeat the setup but use a shorter (less than 2 meters) USB cable

Once the target connects, fire five shots into the paper. Try to separate the shots into 10, 8, 6, 4, 2 rings.

- Did the shots register in the correct place?
  - Yes, you’re done
  - No.
    - Did five shots register anywhere – Yes circuit works.
    - No shots registered – Recheck cables and connections
    - Press the DEBUG button (upper right)
      - Does it show an error?
- Do all 10 shots show up on the display?
  - No, check the cables and settings
- Are the shots correct, but the mirror image?
  - The sensors are installed correctly, but mirror image.
  - Swap North and East
  - Swap West and South
  - Go back to the beginning and test the circuit.
- Are the shots correct, but the reversed top and bottom?
  - The sensors are installed correctly, but upside down.
  - Swap North and West
  - Swap South and East
  - Go back to the beginning and test the circuit.

## ALIGNING THE TARGET

Electronic targets are typically not aligned since the shooter adjusts their sights based on the computer display and not the paper. However, the target can be adjusted to accommodate alignment errors between the sensors and the paper

- Connect to the target with the PC client
- Using a paper target, take five shots into the paper
- Remove the paper and place it next to the target on the PC
- Open the Target Calibration box

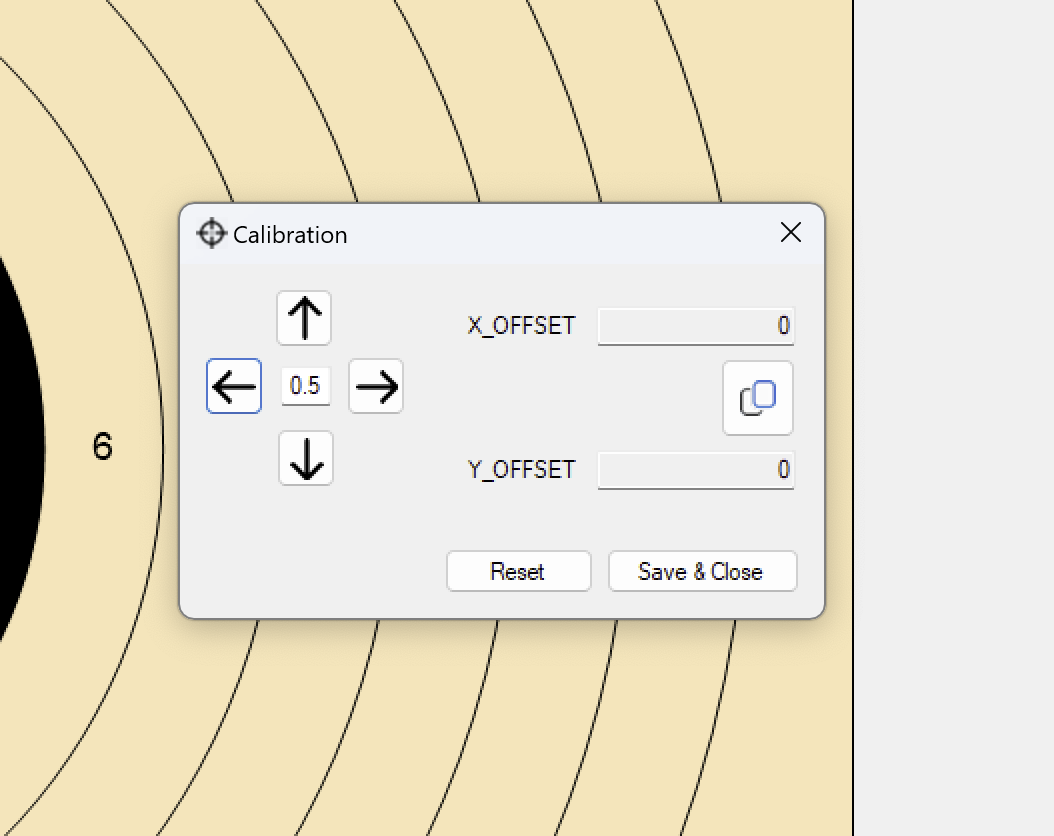
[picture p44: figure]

- Press RESET to clear any previous settings
- Use the arrows to adjust the image to match the paper target

Version 6.1.0 and Before

- Press Save & Close
  - This saves the aligment values into the PC
  - Each PC using the target will need to be aligned to the target

Version 6.1.1 and After

- Press the copy icon (two squares)
- Press X to close the dialog box. DO NOT SAVE & CLOSE
- Open the Debug dialog box
- Paste (Control-V) into the Generic Command Box

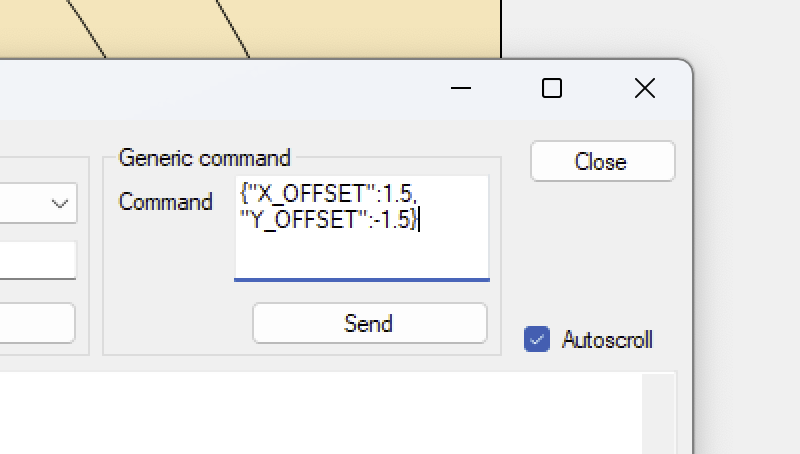
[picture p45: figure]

- Press SEND
  - This copies the alignment settings into the target
  - PCs using the target do not need to be aligned for each target

Trouble Shooting

If the procedure is not done in the correct order, or the alignments are saved twice, then the alignments will be added together and result in a worst alignment than before. If this happens.

- Open the Debug terminal
- Manually reset the aligment by setting X_OFFSET and Y_OFFSET to zero

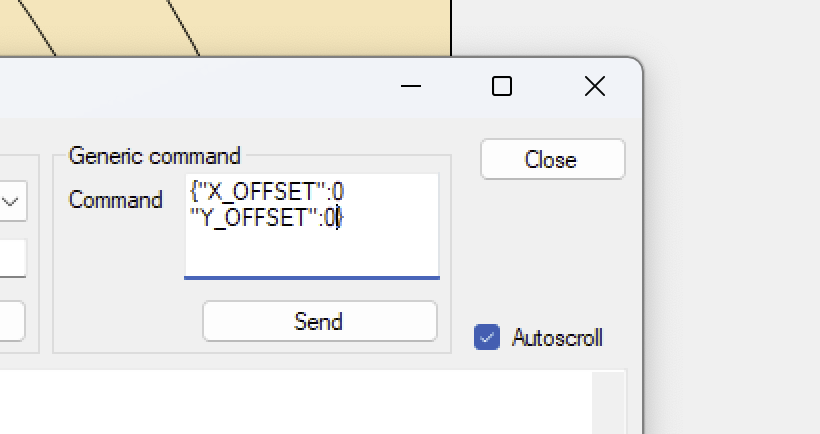
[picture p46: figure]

- Follow the instructions above and make sure to RESET the calibration before starting

## ADVANCED OPERATION

Once you have the target correctly registering shots, it is time to move onto other features:

- WiFi Operation
  - Access Point – Simple operation
  - Station – Connect to your home network
  - Allow multiple people to watch your shooting
- Tabata Training
  - Select the ON and OFF time
  - Select how long between shots
- Rapid Fire shooting
  - Select the competition type

Refer to the relevant chapters here or the supplemental documentation contained on the web site

# LED INDICATORS

The LED indicators are used to show the internal operation of the target, and fault diagnostics.

## LED Indicators, Normal Operation

RDY | X | Y
RED | WHITE | BLUE | Power on self test (Hello World) to show that the software has booted and the circuit has some functionality
GREEN | | | The software has started but not ready for a shot
BLINK GREEN | | | The software has completed startup and ready to receive shots
BLUE | | | The target has gone to sleep
| BLINK GREEN | | The WiFi is in station mode but not connected to a PC
| GREEN | | The WiFi is in station mode and connected to a PC
| BLUE | | The WiFi I in access mode but not connected to a PC
| BLINK BLUE | | The WiFI is in station mode and connected to a PC
| | RED | Insufficient voltage on the motor/LED 12V supply
| | YELLOW | Voltage present on the motor connector, but not enough to drive the motor.
| | BLINK GREEN | Voltage sufficient for motor drive
| | BLUE | Witness Paper disabled by setting PAPER_TIME = 0

## LED Indicators, Fault Operation

RDY | X | Y
RED | RED | RED | Failure detected on NORTH sensor
RED | RED | GREEN | Failure detected on EASH sensor
RED | RED | BLUE | Failure detected on SOUTH sensor
RED | RED | YELLOW | Failure detected on WEST sensor
RED | GREEN | RED | Miss detected

# MULTIFUNCTION SWITCHES

The Multi Function Switches are general purpose inputs and outputs that can be set to perform a user defined operation.

The multifunction connector is located on the upper left side of the circuit board. It provides four signals A, B, C, and D along with ground references and a voltage supply. The intention is that additional switches or LEDs can be added to the target and the operation determined by software configuration.

The connector is illustrated in Figure 5.

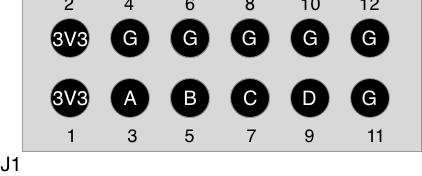
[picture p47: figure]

Figure 5: Multifunction Connector

In addition, two switches on the circuit board marked 1 and 2 are connected directly to inputs A and B on the multifunction connector.This allows the user to manage the target without additional hardware

## Connector assignment

The 12 pins are assigned

1, 2 | 3.3 Volt , 50mA supply for interfaces
4, 6, 8,10, 11, 12 | Digital Ground
3 | Digital input A, also connected to push button 1
5 | Digital input B, also connected to push button 2
7 | Digital input or output C, defined in software
9 | Digital input or output C, defined in software

## Digital Inputs A/B (1/2)

Push button switches 1 and 2 are routed to discrete inputs A & B and have five modes of operation

- Tap switch 1
- Tap switch 2
- Hold switch 1
- Hold switch 2
- Hold switches 1 and 2 together

When pressed, the software starts a timer, if the switch is released inside of 2 seconds, it is considered a tap. If the switch is held for more than 1 second, it is a hold. If both are held at the end of 1 second, then BOTH switches are held

### Digital Input Operation

The switches are configured by using the JSON command to each of the switches and modes, Instructions for using the JSON commands are found in the section SETTINGS found in this document.

- {“MFS_HOLD_1”:X}
- {“MFS_HOLD_2”:X}
- {“MFS_HOLD_12”:X}
- {“MFS_TAP_1”:X}
- {“MFS_TAP_2”:X}

Where the value of X is defined in Table A

Table A: Digital Input MFS Values

Value | Action | Description
0 | Power Tap. | Wake the target up if it has gone to sleep
1 | Paper Feed | Turn on the witness paper drive to feed paper
2 | LED Adjust | Increase the brightness of the LEDs until 100% and then reset to zero
3 | Paper Shot | Advance the paper a set distance as if a shot has been recognized
4 | PC Test | Simulate a random shot sent to the PC client
5 | On / Off | Put the target to sleep
6
7
8

## Digital Inputs or Outputs C/D

Connections C and D can be programmed as input or outputs depending on the

### Input or Output Operation

The switches / outputs are configured by using the JSON commands

- {“MFS_HOLD_C”:X}
- {“MFS”HOLD:D”:X}
- {“MFS_SELECT_CD”:X}

Where the value of X is defined in Table B

Table B: Digital I/O MFS Values

Value | Action | Description
9 | No action
10 | Target Type | Used to inform the PC of a specific target type
18 | Rapid RED | Output is used to drive the RED indicator when in rapid fire
20 | Rapid GREEN | Output is used to drive the GREEN indicator when in rapid fire
22 | Rapid LOW | Set the rapid indicator LED to be active low (0 turn on LED)
24 | Rapid HIGH | Set the rapid indicator LED to be active high (01turn on LED)
26 | Stepper Drive | The output is used to drive a stepper motor

## FACTORY RESET

Holding the 1 and 2 buttons closed and applying power until the RDY light flashes will reset the board back to the factory defaults.

# WiFi OPERATION

The Version 5 hardware has two modes of WiFI operation

- Access Point. The target provides its’ own SSID, typically FET-TARGET. Each target is a unique SSID
- Station. The target uses the local (home) SSID. Multiple targets can be on the same SSID

The default operation of the FreeETarget is to be an access point, This allows for simple setup, but means that the Client PC cannot be on the internet at the same time as the target is connected.

While harder to setup, Station mode allows multiple targets to be on the same network as the PC and an internet connection

## ACCESS Point

Access point is the default operation. Access point sets the SSID of the target to be FET-name, where name can be changed through a command line

The controls for the access point are:

Control | Description
{“NAME_ID”:x} | The NAME_ID allows the operator to select an SSID from a list of available SSIDs 0 – FET-TARGET. (Default) 1 – FET-1 2 – FET-2 3 – FET-3 4 – FET-4 5 – FET-5 6 – FET-6 7 – FET-7 8 – FET-8 9 – FET-9 10 – FET-10 11 – DOC 12 – DOPEY 13 – HAPPEY 14 – GRUPMY 15- BASHFUL 16 – SNEEZY 17 - SLEEPY 18 – RUDOLF 19 – DONNER 20 – BLITZEN 21 – DASHER 22 – PRANCER 23 – VIXEN 24 – COMET 25 – CUPID 26 - DUNDER 27 – ODIN 28 – WODEN 29 – THOR 30 – BALDAR 99 – User Defined (FET-userdefined) 100 – User Defined (userdefined) 101 – Serial number (FET-<SERIAL_NUMBER”)
{“WIFI_CHANNEL”:X} | Sets the WiFi channel Use this control if there is a conflict with another network near the target Range 1-11, Default 6. U
{“WIFI_HIDDEN”:X} | Hides the SSID from the network 0 – Visible 1 - Hidden
{“WIFI_PWD”:”xxxx} | Assigns a password to the target SSID

IMPORTANT

When used in Access Mode, the target sets itself to a fixed IP address of 192.168.10.9 and port 1090

The SSID used by the PC must match the one assigned by NAME_ID, and is typically FET-TARGET

## Station Mode

Station mode allows the target to be on the same network as other devices in the building. For example, the target can be on the home network allowing the target and teamViewer to be active at the same time on the same network

The controls for the Station Mode are:

Control | Description
{“WIFI_PWD”:”xxxx”} | Assigns a password to the active SSID
{“WIFI_SSID”:”xxxx”} | Selects the SSID to be used by the target
| Under normal operation the target will receive a dynamic IP address from the router. To fix the IP address between operation, it is necessary to use a static IP
{“WIFI_IP”:”xxxx”} | Forces a static IP into the target
{“WIFI_GATEWAY”:”xxxx”} | Assigns a gateway address to the target

IMPORTANT

When used in Station Mode, the router assigns the IP address to the target. To find the IP address that has been assigned to the target, use the {“ECHO”:0} command to list the settings and look for

The IP address can be overwritten by using the {“WIFI_IP”:”xxxx”} command

WIFI_IP_ADDRESS: A.B.C.D, where A.B.C.D is the address that needs to be entered into PC client configuration

When using Station Mode, the PC Client will issue a warning that the SSID is not of the form FET-name. This is for information only and can be ignored.

## TARGET NAME ACCESS

Starting in Version 6.1.12, the target can be accessed using it’s target name.

Using {“ECHO”:0}, to find the target name, for example FET-TARGET.

The target can be using <TARGET-NAME>.local in place of the older IP address (192.168.86.200)

## WiFi RESETTING THE TARGET

While shooting, the target keeps track of the last 100 (40 sighters, 60 on score) shots. When the PC Client connects over WiFi, the scores from the beginning of the session are downloaded at once. This is done so that (say) a coach can log into their student’s target and see all of the shots since the beginning.

In operation, connecting over USB will automatically reset the target back to the beginning. Connecting by WiFi does not have this feature since resetting every time that someone connects on WiFi would be confusing. To get around this problem, the target has the setting

{“WIFI_RESET”:X}.

The default is 0, so that the target is not reset. Setting X to 1 will reset the target whenever the FIRST user logs in over WiFI.

The ideal operation is for the firing point to be connected by USB and the target is reset every time the firing point connects. If no USB is used, then {“WIFI_RESET”:1} should be used so that the shooter resets the target on the first connection.

## BROWSER OPERATION

Version 6.1.11 and higher supports WiFi operation using a browser. Browser operation is intended to be used as a convenience in place of the PC Client.

The browser based FreeETarget interface is in two parts:

1 – The main target page showing your shots, and;

2 – A control page to manage the target remotely.

You will need to know the name or IP address of your target.

To start the target, enter the target URL

<target_name>.local

This starts the target and records your shots. The target will automatically disconnect after 15 minutes of inactivity.

To control the target, access the menu port

<target_name>.local:8080

This will present the menu buttons:

START – Clear any shots and start recording

STOP – Stop recording shots and return to the HELP page

To find out information about your target, use the WHO command

<target-name>.local/who

Or

<target-name>.local:8080/who

# SETTINGS

The software has a number of settings that affect the operation of the unit

Settings on the target are changed using the debug tab on the PC client.

1. Connect to the target as if you were shooting a match
2. Select the Debug icon on the upper right (looks like a finger print). If it is not visible, make sure that ESP32 is selected in the setup.
3. The debug menu will appear as shown in Figure

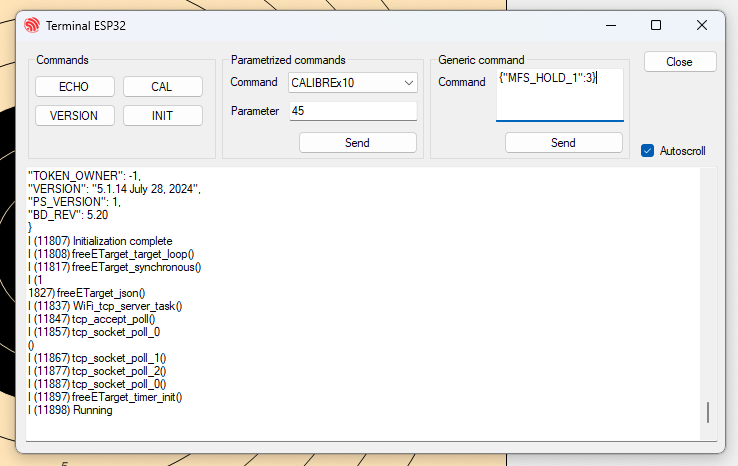
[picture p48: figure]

Figure Z: Debug Dialog Box

4. Enter the setting in the Generic Command box and press [SEND] to setting to the target.
5. Results from the target appear in the large dialog box

## CONTROL SETTINGS

The settings that are available are shown in Table S. To change a settings, use the text in the Setting column and form the JSON command

{“setting”:value}

For example {“FOLLOW_THROUGH”:4} or {“SENSOR_DIA”:232.5}

Hidden settings are not displayed using an ECHO command, but can be set using the standard method, ex {“TABATA_ON”:1}

Table S: FreeETarget Settings

Setting | Hidden | Description | Typical Value | Saved
ANGLE | | Orientation of the sensors from vertical | 45 degrees | Y
AUX_MODE | | Enables the AUX port for operation | 0 – AUX port disabled | Y
FACE_STRIKE | Y | Enables face strike detection | Must be zero | Y
FOLLOW_THROUGH | | Time to wait before transmitting score | 0 – Immediate, 5 - Training | Y
KEEP_ALIVE | | WiFI beacon used to keep the WiFi connection alive | 120 | Y
LED_BRIGHT | | LED brightness 0-100% | 0 – Off, 100 - fully on | Y
MFS_TAP_2 | | Action to perform if switch 2 is tapped | 0 – Wake up | Y
MFS_TAP_1 | | Action to perform if switch 1 is tapped | 3 – Paper shot | Y
MFS_HOLD_2 | | Action to perform when switch 2 is held for 2 seconds | 5 – Turn the target off | Y
MFS_HOLD_1 | | Action to perform when switch 1 is held for 1 second | 1 – Paper feed | Y
MFS_HOLD_12 | | Action to perform if both MFS switches are held down | 2 – LED adjust | Y
MFS_HOLD_C | | Action to perform with GPIO C | 9 – No action | Y
MFS_HOLD_D | | Action to perform with GPIO D | 9 – No acton | Y
MFS_SELECT_CD | | Output polarity of signals C and D | 22 – Invert output | Y
MIN_RING_TIME | | Time before next shot is recognized after the current shott | 500 ms | Y
NAME_ID | | Index to select a target name for FET- | 0-31, 99 & 100default 0 | Y
NAME_TEXT | | Text target name used when NAME_ID is 99 or 100 | | Y
OTA_URL | | URL where OTA binary is stored | Do not change | Y
PAPER_ECO | | Distance in mm to ignore shot and not move paper | 0 – Disabled, 1 to 100 mm | Y
PAPER_SHOT | | How many shots to fire before advancing paper | 0 – Advance every time | Y
PAPER_TIME | | Sets the time the motor turns to advance the witness paper | 500ms | Y
PCNT_LATENCY": | | Uses a calibrated offset to improve the detection accuracy | 0 – Disabled, 32 Typical | Y
POWER_SAVE | | Idle time in minutes before going to sleep | 0 – Off, Typical 30 minutes | Y
RAPID_COUNT | Y | How many shots in a rapid fire string | | N
RAPID_ENABLE | Y | Enable rapid fire mode | 1 - Enable | N
RAPID_TIME | Y | How long will the rapid fire event last in seconds | | N
RAPID_WAIT | Y | How long to delay after rapid fire has been enabled | | N
REMOTE_ACTIVE | | Is there a remote server that can receive scores | 1 – Enable | Y
REMOTE_KEY | | Access key for authentication | Text String | Y
REMOTE_URL | | URL of the remote server | IP Address (ex “192.168.1.1”) | Y
SEND_MISS | | Send a record to the PC whenever a shot has been missed | 0 – Miss not sent | Y
SENSOR_DIA | | Calibrated distance between sensor faces | 232mm for air pistol or air rifle | Y
STEP_COUNT | | How many steps to issue stepper motor witness paper | 0 – Disabled | Y
STEP_RAMP | | How many cycles to change during ramp-up | 0 – Disabled | Y
STEP_START | | Number of cycles to start stepping at | 0 – Disabled | Y
STEP_TIME | | Time interval in ms between steps | 0 – Disabled | Y
TABATA_ENABLE | Y | Enable the Tabata training mode | 0 – Disabled | N
TABATA_ON | Y | Time in seconds that the LEDs are on during a Tabata cycle | | N
TABATA_REST | Y | Time in seconds that the LEDs are off between shots | | N
TABATA_WARN_OFF | Y | Time in seconds that the LEDs are off after the warning | | N
TABATA_WARN_ON | Y | Time in seconds that the LEDs are on to warn the shooter | | N
TARGET_TYPE | | Target Override for alternate targets | 0 – No override 4 – 5 bull target 74mm 5 – 5 bull target 79mm 11 – 10bull + sighters (Orion) 12 – 10 bull + sighters (NRA) | Y
TOKEN | | Enable Rapid Fire token ring | 0 – Disable, 1 Enable | Y
TRACE | | Display diagnostics trace. Cleared on next power cycle DLT_CRITICAL – Error effects normal operation DLT_INFO – Internal operational information DLT_APPLICATION – Scoring calculations | 1-DLT_CRITICAL 2-DLT_INFO 4-DLT_APPLICATION 8-DLT_COMMUNICATION 16-DLT_DIAG 32-DLT_DEBUG 64-DLT_SCORE 128-DLT_HTTP 256 – DLT_HEARTBEAT | N
VREF_LO | | Shot detection low voltage threshold | 1.25 Volts | Y
VREF_HI | | Shot detection high voltage threshold (VREF_HI > VREF_LO) | 2.0 Volts V5 hardware only | Y
WIFI_CHANNEL | | WiFi channel used with Access Point targets | 1 – First 6 – Recommended 11 - Last | Y
WIFI_GATEWAY | | Location of the gateway to rthe remote server | Text (ex “192.168.1.0”) | Y
WIFI_HIDDEN | | Hide the SSID of an access point target (FET-xxx_ | 0 Visible SSID 1 – Hode SSID | Y
WIFI_IP | | Static IP of the target (empty => not used) | Text (ex “192.168.1.54”) | Y
WIFI_PWD | | WiFi password associated with SSID. Both Access point and Station Modes | Default is empty, no password | Y
WIFI_RESET_FIRST | | Reset the target when the FIRST WiFi connection is made | 0 – Do not reset 1 – Reset on first connection | Y
WIFI_SSID | | SSID associated with Station Mode targets | Default is empty, Access Mode Non empty, Station Mode | Y
X_OFFSET | | Offset applied to X axis to calibrate score | 0 – Disabled until calibrated | Y
Y_OFFSET | | Offset applied to Y axis to calibrate score | 0 – Disabled until calibrated | Y
Z_OFFSET | | Vertical distance from target plane to sensor plane | 13mm typical | Y
NORTH_X/NORTH_Y | Y | Correction in mm from ideal location. + away from centre | 0 recommended | Y
EAST_X/EAST_Y | Y | Correction in mm from ideal location | 0 recommended | Y
SOUTH_X/SOUTH_Y | Y | Correction in mm from ideal location – closer to centre | 0 recommended | Y
WEST_X/WEST_Y | Y | Correction in mm from ideal location | 0 recommended | Y
LOCK | | Enter a lock code to prevent changes to the configuration | 0 Unlocked | Y
UNLOCK | | Entering the lock code will unlock the target configuration | Lock code | N

## INFORMATION ONLY

The items shown in Table S provide insight into the operation but cannot be changed by the user

Command | Description | Typical Values
RUN_STATE | Internal running state | 1 – Startup 2 – In operation (normal) 4 – Test Mode 8 - Sleep
RUNNING_MINUTES | How long the target has been turned on
TIME_TO_SLEEP | How long before the target goes to sleep
TEMPERATURE | Temperature in C inside the target. Used to calculate speed of sound
RELATIVE_HUMIDITY | Humidity inside the target. Used to calculate speed of sound
TIMER_COUNT | Expected maximum time expected to occur after shot | 1 LSB – 100ns
V12 | LED / Witness paper drive voltage | Nominally 12V
WIFI_MAC | MAC address of the WiFI
WIFI_IP_ADDRESS | IP address used by target
WIFI_MODE | Access Point or Station mode programmed into target
TOKEN_RING | Assigned token ring address
TOKEN_OWNER | Which target is the master of the token ring | Should be 1
VERSION | Current firmware version
PS_VERSION | Persistent storage version. Used for automatic updates
BD_REV | Board revision

## HIDDEN COMMANDS

The target has a number of commands that can be used control the target.

Command | Description | Typical Values
50M | Set the configuration for a 50 meter pistol target | 0
BYE | Turn off the target and reduce power | 0
ECHO | Display the internal settigns | 0
INIT | Reinitialize the board | 0
MFS? | Show the available MFS settings | 0
OTA | Start and OTA download from the command mode | 0
RESET | Reboot the target | 0
TEST | Run the onboard diagnostics | 0 –Test options

## TYPICAL SETTINGS

The settings to implement typical actions are provided below.

### DC Motor Witness Paper

The DC motor witness paper drive turns on the motor for a short period of time. Roughly speaking the paper will advance 40mm with a 500ms ON time. To change the amount of paper that advances, it is necessary to shorten or lengthen the time the motor runs.

Duration = 500 x Desired Movement / 40

To correctly set up the DC motor drive, use the following settings

{“PAPER_ON”:500}

{“STEPPER_COUNT”:0}

{“STEPPER_TIME”:0}

The setting {“PAPER_ECO”:X} is used to enable the witness paper drive if the hole is within X mm of centre.

### Stepper Motor Witness Paper

The stepper motor requires a separate circuit, for example ROB-14450 available from DigiKey. This circuit converts pulses from the FreeETarget board into energizing the stepper motor windings.

To setup a stepper motor use the following settings:

{“PAPER_ON”:0

{“STEPPER_COUNT”:60}

{“STEPPER_RAMP”:10}

{“STEPPER_START”:100}

{“STEPPER_TIME”:20}

{“MFS_HOLD_C”:26}

{“MFS_HOLD_D”:28}

IMPORTANT

The settings will be strongly influenced by the stepper motor used on the target and settings may need to be adjusted in place

The STEPPER_COUNT=X determines how far the paper advances, and STEPPER_TIME= is the duration of each pulse to the stepper (typically in the order of 20ms)

MFS_HOLD_C = 26 converts MFS signal C into the stepper motor driver pulse

The setting {“PAPER_ECO”:X} is used to enable the witness paper drive if the hole is within X mm of centre.

### Sensor Placement

The sensors are located a distance apart that corresponds to the size of the 1 ring. For a pistol target, this is 230mm. There may be an adjustment if the sensing circuit is behind the front surface of the microphone.

If the target is set up for 50m small.bore, or large bore rifles, the sensors will need to be relocated, to another distance.

{“SENSOR_DIA”:X}

Where X is the distance in mm across the target. X does not necessarily need to be a whole number, the value X=232.5 is a legal value.

### WiFI Station

The WiFI station mode (the target is on the home network) is enabled by setting

{“WIFI_SSID”:”home network”} Example “myHome”

{“WIFI_PWD”:”home password”} Example “12345678”

Optional Static IP

{“WIFI_IP”:”IP address of the target ”} Example 192.168.1.54

{“WIFI_GATEWAY”:”IP address of the gateway ”} Typically 192.168.1.0

### WiFi Access Point Mode

The WiFi accces point mode means that the target generates it’s own SSID, typically FET-TARGET. To enable acces point mode, it is necessary to turn off the station mode.

{“WIFI_SSID”:””}

{“WIFI_PWD”:”password”} The target has a password

{“WIFI_PWD”:””} The target does not have a password

{“WIFI_HIDDEN”:X} X = 0 the SSID is not hidden, X=1 hides the target

{“NAME_ID”:Y} Change the name of the target (see settings in WiFi Operation)

The Auxilary Connector is used as an alternative communications connector. This would be used to connect an RS-485 interface, tor connect multiple targets together using a Token Ring

The four pin AUX connector has the following connections

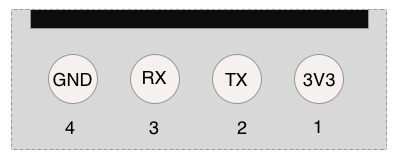
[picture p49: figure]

Figure Z: Auxiliary Connector

The connector provides 3.3 volts to drive an RS-232 or RD-485 convertor. Current is limited to about 50mA

## TOKEN RING

The Auxiliary connector can be used as a token ring connector to join up to 7 targets and transmit the scores to the PC.

The connection for the token ring is shown in the figure below.

The transmit of 1 goes to the receiver of the next, and all the way round the ring. All of the ground connections are joined together. Be careful to ensure that there are no ground loops before attaching the token ring cable.

For the target that is connected to the PC Client, set {“TOKEN”:1}. The remainder are set to {“TOKEN”:2}

The token ring is disabled if any of the targets are set to {“TOKEN”:0}

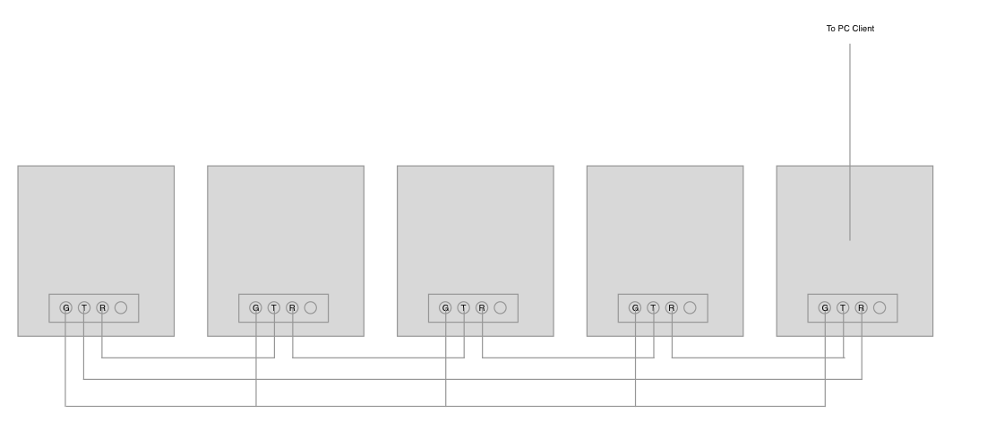
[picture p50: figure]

Figure Z: Token Ring Wiring

# DOWNLOADING FIRMWARE

The target has the ability to be reprogrammed when new features are added or bugs fixed.

Downloading to the target performed in two steps

- Preparation – Setting up the PC Client download software, done once
- Upload – Uploading new software to the target

## PREPARATION

Version 5 hardware uses an ESP32 microcontroller. The download software is provided by a Python module that must be installed before the firmware can be loaded. Once the Python module have been downloaded once, there is no need to do it again

### Download Python

From your web browser, search fo PYTHON DOWNLOAD

Follow the link and select Download Python (Note the version number may be higher than shown here)

Download and install Python.

If prompted, select OVERRID MAX PATH LENGTH

Restart your computer to update the PATH variable

### Install ESPTOOLS

Once the PC has finished restarting, launch a command prompt and run the command

pip install “esptool<5”l

The PC will return something that looks like

C:\Users\allan>pip install esptool

Requirement already satisfied: esptool in c:\users\allan\appdata\local\packages\pythonsoftwarefoundation.python.3.11_qbz5n2kfra8p0\localcache\local-packages\python311\site-packages (4.7.0)

Requirement already satisfied: bitstring>=3.1.6 in c:\users\allan\appdata\local\packages\pythonsoftwarefoundation.python.3.11_qbz5n2kfra8p0\localcache\local-packages\python311\site-packages (from esptool) (4.1.4)

Requirement already satisfied: cryptography>=2.1.4 in c:\users\allan\appdata\local\packages\pythonsoftwarefoundation.python.3.11_qbz5n2kfra8p0\localcache\local-packages\python311\site-packages (from esptool) (42.0.2)

Requirement already satisfied: ecdsa>=0.16.0 in c:\users\allan\appdata\local\packages\pythonsoftwarefoundation.python.3.11_qbz5n2kfra8p0\localcache\local-packages\python311\site-packages (from esptool) (0.18.0)

Requirement already satisfied: pyserial>=3.0 in c:\users\allan\appdata\local\packages\pythonsoftwarefoundation.python.3.11_qbz5n2kfra8p0\localcache\local-packages\python311\site-packages (from esptool) (3.5)

Requirement already satisfied: reedsolo<1.8,>=1.5.3 in c:\users\allan\appdata\local\packages\pythonsoftwarefoundation.python.3.11_qbz5n2kfra8p0\localcache\local-packages\python311\site-packages (from esptool) (1.7.0)

Requirement already satisfied: PyYAML>=5.1 in c:\users\allan\appdata\local\packages\pythonsoftwarefoundation.python.3.11_qbz5n2kfra8p0\localcache\local-packages\python311\site-packages (from esptool) (6.0.1)

Requirement already satisfied: intelhex in c:\users\allan\appdata\local\packages\pythonsoftwarefoundation.python.3.11_qbz5n2kfra8p0\localcache\local-packages\python311\site-packages (from esptool) (2.3.0)

Requirement already satisfied: bitarray<3.0.0,>=2.8.0 in c:\users\allan\appdata\local\packages\pythonsoftwarefoundation.python.3.11_qbz5n2kfra8p0\localcache\local-packages\python311\site-packages (from bitstring>=3.1.6->esptool) (2.9.2)

Requirement already satisfied: cffi>=1.12 in c:\users\allan\appdata\local\packages\pythonsoftwarefoundation.python.3.11_qbz5n2kfra8p0\localcache\local-packages\python311\site-packages (from cryptography>=2.1.4->esptool) (1.16.0)

Requirement already satisfied: six>=1.9.0 in c:\users\allan\appdata\local\packages\pythonsoftwarefoundation.python.3.11_qbz5n2kfra8p0\localcache\local-packages\python311\site-packages (from ecdsa>=0.16.0->esptool) (1.16.0)

Requirement already satisfied: pycparser in c:\users\allan\appdata\local\packages\pythonsoftwarefoundation.python.3.11_qbz5n2kfra8p0\localcache\local-packages\python311\site-packages (from cffi>=1.12->cryptography>=2.1.4->esptool) (2.21)

[notice] A new release of pip is available: 24.0 -> 24.1.2

[notice] To update, run: C:\Users\allan\AppData\Local\Microsoft\WindowsApps\PythonSoftwareFoundation.Python.3.11_qbz5n2kfra8p0\python.exe -m pip install --upgrade pip

Type

PATH

Verify that a line resembling

C:\Users\user_name\AppData\Local\Packages\PythonSoftwareFoundation.Python.3.11_qbz5n2kfra8p0\LocalCache\local-packages\Python311\Scripts;

Should appear in your path variable

## DOWNLOAD

Once the basic download package has been installed, you can download new firmware whenever necessary

Visit the free-e-target.com -> tech support -> download for the current release software. Download and save the file (typically to your download folder)

In the PC client, from the upper right corner, select the download icon. The download menu will appear

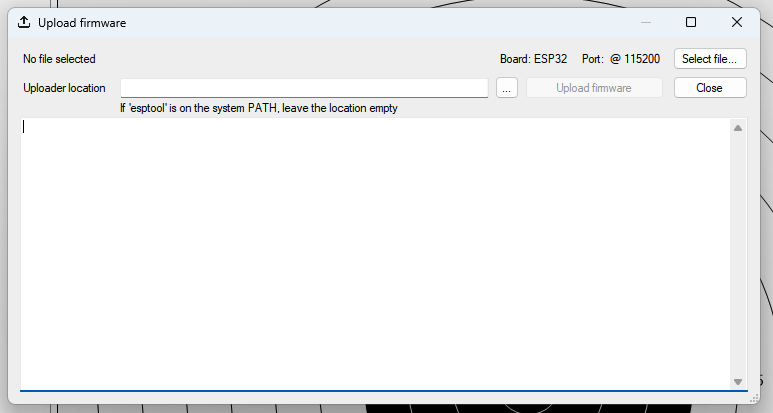
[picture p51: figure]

Select the download file, typically freetarget_version.bin

Press the download firmware button. If everything is properly installed the PC will connect to the target and begin the download.

Starting with Version 6.1.0 of the target firmware, software updates can be carried out simply by pressing a button on power up and letting the target update itself from a remote web site. This simplifies the operation of the target and makes maintenance much easier.

REQUIRED

- FreeETarget PC software version 4.10.2 or higher
- Target loaded with firmware version 6.1.0 or higher
- The target connected to the home network with internet access

OVER THE AIR UPDATE

Before beginning the update, make sure that the target is on the home network, and that network is connected to the internet. Targets using the FET-TARGET SSID will not be able to use this feature.

To update the software, carry out the following steps

1. Power off the target
2. Press and hold the #1 button. Do not release!
3. Apply power to the target
4. Wait until the RDY LED turns BLUE. This is the signal that the upload has begun
5. You can let go of the #1 button
6. The X LED will blink blue as the upload process continues
7. The upload ends when the RDY LED stays BLUE, and the X and Y buttons change to RED or GREEN.
8. Observe the colours of the X and Y LEDs
9. Press the #1 button to end the process and start the target running

FINISHING

When the update is complete, the LEDs will tell you whether or not the upload was successful

RDY | X | Y | Description
BLUE | GREEN | GREEN | The update was successful and the target it ready to run
BLUE | RED | DARK | The target could not reach the internet. Check your router and internet. Verify that the target is on the home network and that the target connected to the router.
BLUE | DARK | RED | The update failed. Possible cause: internet failed
BLUE | RED | RED | The update failed and should not be repeated. This error occurs if there is a defect in the download file that needs to be connected at the server and not the target.

ROLLBACK RECOVERY

If something goes wrong with the new software, you can fall back to the previous version by

1. Remove power from the target
2. Press and hold the #1 button. Do not release!
3. Apply power to the target
4. Wait until the RDY LED turns BLUE. This is the rollback has completed

# TROUBLE SHOOTING

The FreeETarget is a complicated system that relies on a number of components to work together. When they work it’s great, but I something is out of place it may be difficult to determine the fault and take corrective action. This section goes over the common faults and fixes for the target.

Rougly speaking, there are two phases to the failures:

- Construction failures due to assembling the target incorrectly
- Operational failures due to debris or parts coming loose.

The troubleshooting section treats this as separate sections

## ASSEMBLY TROUBLE SHOOTING

You’ve put the target together and it doesn’t record shots, what to do.

Step | Expected Result | Yes | No
1 | When power is first applied do the LEDs show RED-WHITE-BLUE | The circuit has powered up and begun operation | Check the USB cable for power
2 | After RED-WHITE-BLUE does the RDY LED start blinking | The self test has completed and begun normal operation | The LEDs will stop with a pattern, Refer to the section LED Indicators to determine the fault. Verify that all of the connections are in place
3 | From the PC client, CONNECT to the target. After a few seconds doe the PC report connected, and the timer start counting | The USB is operational | Open the DEBUG tab. Is there an error or some message on the window? Folllow the corrective action recommended by the debugger
4 | Take a shot into the target Is a shot registered more-or-less correctly | The circuit has detected the pellet and reported the location. Errors in assembly may introduce an error that can be calibrated out | Open the DEBUG tab. Is there a shot registered on the display? Is there an error message? Common Problems Cable not installed correctly Sensors in the wrong location
5 | The shot looks good, but is the mirror image of what it should be | Reverse the NORTH-EAST and WEST-SOUTH sensors
6 | Is the LED illumination working? | The LEDs have been correctly installed | Verify that the LED wiring is installed correctly Verify that the 12V supply is attached to the screw terminals Verify that the polarity of the wires is correct
7 | When the shot was fired did the witness paper move | The witness paper is correctly installed | Verify that the 12V supply is attached to the screw terminals Verify that the polarity of the wires is correct

### WiFi TESTING

Once the basic functionality has been verified the WiFi can be turned on and verified

Preparation

Step | Expected Result | Yes | No
1 | From the DEBUG menu While connected to the USB, begin the WiFI configuration by typing {“WC”} [SEND] Does the WiFI configuration menu appear on the display? | The WiFI is ready for configuration | Verify the USB connection Retry the command Is there ANY information on the PC client?
2 | If using Station mode Set the SSID
3 | If using a password, set the password
4 | If using an Access Point, set the Channel to 6
5 | Exit the configuration
6 | On the PC Client, DISCONNECT and CONNECT
7 | Using the DEBUG menu, look down the list of settings. Find the WIFI_IP setting
8 | If Access Point was used Is the IP address 192.168.10.9:1010 | The WiFi is configured correctly | Check that the value WIFI_SSID is empty (“”)
9 | If Station Mode was used Is the IP address of the form 123.456.789.101:1090 | The WiFI is configured correctly Record this IP address | Reenter the WIFI_SSID and the WIFI_PWD and try again
10 | Verify that the PC is on the correct SSID for the target | The PC is configured correctly | Change the PC SSID to match the target
11 | From the SETTINGs tab, set the connection type to TCPIP and enter the IP address recorded in Steps 8 or 9 as appropriate
12 | Press CONNECT After a few seconds does the client show CONNECTED | The PC is connected to the client | Repeat Steps 1 to 11

## OPERATIONAL TROUBLE SHOOTING

Once you have successfully shot the first ten rounds into the target, you’ve proven that the target has been constructed correctly and all of the settings are correct. The target should continue to operate indefinitely.

Should the target stop working, it is most likely due to something being changed or an accumulation of dirt in the sensors. Follow the Table below for troubleshooting

### MISPLACED or NO SHOTS

When shooting a target, the shot is not recorded, or recorded in the wrong place

Step | Expected Result | Yes | No
1 | The RDY LED is blinking green or blue | The target is receiving power and is operating correctly | The target is not receiving power or a short in the circuit Look for debris on the board Look for debris on the sensors, particularly West and South
2 | Take a shot, Is a shot recorded in the right place | The sensors and calculations are correct | Make sure the flat cable is connected from the circuit board to all of the sensors. Press the cable in place Make sure that there is no debris on the West or South connectors Make sure that there is nothing blocking the sensors When using a SUIS target mask, or a regular mask with a hole in it, ensure that the witness paper is supported. Layer the target as Target Plate Scrap target Witness Paper Front Facing Target

### WITNESS PAPER DOES NOT MOVE

The witness paper should move as each shot is registered. If it does not, use the table below to identify the error

Step | Expected Result | Yes | No
1 | Paper moves after every shot | The witness paper is operating correctly | Verify that the cables are connected and secure in the connector
2 | The setting PAPER_TIME or STEP_COUNT are non zero | The setting appears to be correct | Program the correct value for your target
3 | Press the paper advance button on the circuit Paper advances | The witness paper hardware is installed correctly | Verify the cables Verify the connectors Verify that the AC adapter is plugged in

## USING TEAMVIEWER

When all else fails TeamViewer can be used to manage the target from a distance.

- Download Teamviewer from teamviewer.com
- Install and launch TeamViewer
- Look for the remote control ID and password

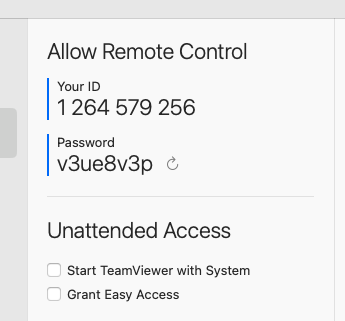
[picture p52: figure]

- Email these two numbers to free-e-target.com
- Connect the target to the PC using a USB cable
- Launch the PC Client

When connected you will see changes made to the PC Client screen and occasionally searches for software that should be installed on your computer.

If your help is needed, you will see a message box appear with instructions or questions.

freETarget MULTIFUNCTION SWITCHES

freETarget WIFI OPERATION

freETarget SETTINGS

freETarget AUXILARY CONNECTOR

freETarget DOWNLOADING FIRMWARE

freETarget OVER THE AIR UPDATES

freETarget TROUBLESHOOTING

freETarget INTRODUCTION

freETarget TABLE OF CONTENTS

freETarget COMMISSIONING

freETarget LED INDICATORS

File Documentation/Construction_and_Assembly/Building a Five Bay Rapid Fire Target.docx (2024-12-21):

# freETarget

Application Note:

Building a Five Bay Rapid Fire Target

CAUTION

When using freeTarget:

- Wear eye protection
- Maintain a safe distance
- Do not shoot into any areas except the open target areas.

The freeETarget project or contributors will not be responsible for any injuries when using this target of it’s components.

Target shooting can be dangerous so apply caution in everything you do.

SUMMARY

This application note describes how to merge five targets into a single five bull rapid fire target.

- Joining five targets
- Configuration
- Use
- Bill of Materials

INTRODUCTION

Conventional operation of freETarget is one shooter, one target. In rapid fire, the user uses five separate targets and puts one shot into each. The results are then merged into a single score.

Five freeTargets can be linked together so that the scores in each is relayed back to a central target and then on to the client PC. This allows for five targets to be controlled and monitored from one place. The setup is illustrated in Figure 1.

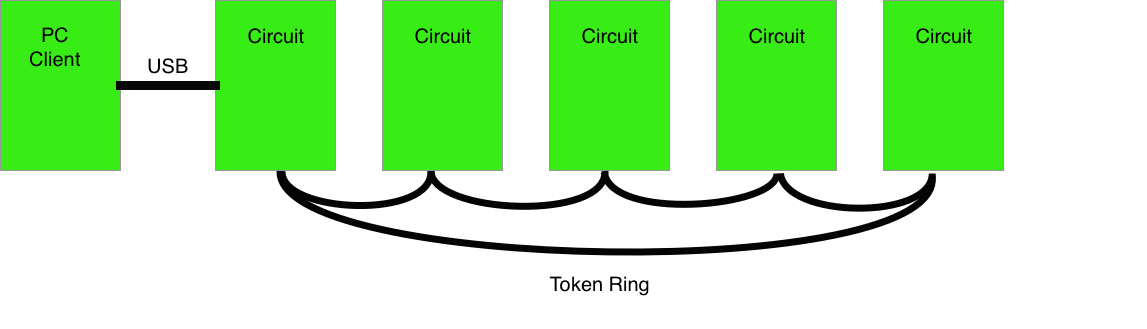
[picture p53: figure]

Figure 1: Rapid Fire Assembly

As each shot is fired, the score is passed along to the next circuit in the loop until the message arrives at the central PC and the messages is sent along to the PC client. The PC client then adds the new score to the previous accumulation.

ASSEMBLY

The first part of the assembly is to build five conventional targets, just the same as any other air pistol target. You can elect to paint the front of the targets with a large black circle to emulate the appearance of a standard rapid fire target

Wiring

The trick to the rapid fire target is the token ring network linking the five targets back to the PC. The token ring cable is illustrated in Figure 2.

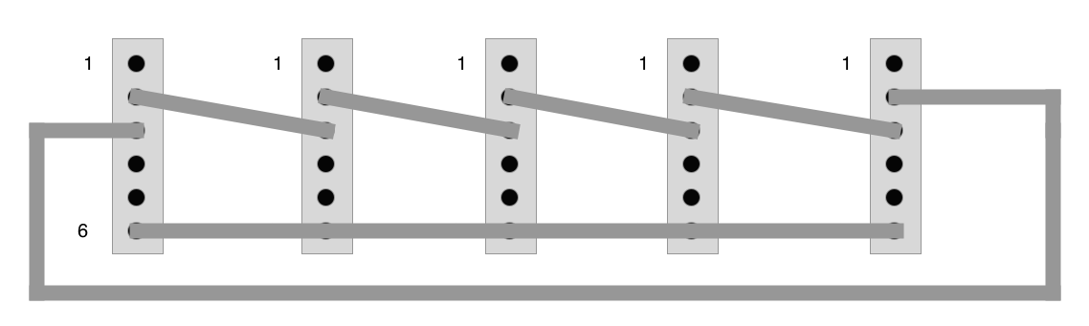
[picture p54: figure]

Figure 2: Token Ring Cable

The Token Ring cable connects the transmit of one circuit to the receive of the next until the ring is complete. A shot record sent from any of the circuits will circulate to the next until it reaches the circuit connected to the PC and the shot is relayed onto the PC.

The token ring cable attaches to the AUX connector (J12) on the Arduino shield. Please note that the WiFi and Token Ring cannot be used together, and communication to the PC is from the master circuit.

Settings

The rapid fire software is available on any firmware 4.2 and higher. To use the rapid fire option make sure that your software is up-to-date. After that you will need to enable the token ring

From the Arduino tab, set

{“TOKEN”:1}. This circuit is attached to the PC client

{“TOKEN””2}. This circuit is part of the ring and not connected to the PC directly.

Setting {“TOKEN”:0} will remove the token ring software and go back to WiFi

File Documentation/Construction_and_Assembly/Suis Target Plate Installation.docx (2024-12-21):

FREETARGET

Application Note: Suis Target Plate Installation

# REQUIRED

- Pistol target plate
- 2 x 5mm x 50mm machine screws
- 2x 3D printed alignment pins

# ASSEMBLY

- Remove the pistol plate and remove the 3D printed paper holder
- At the locations shown in Figure 1, insert the alignment pegs

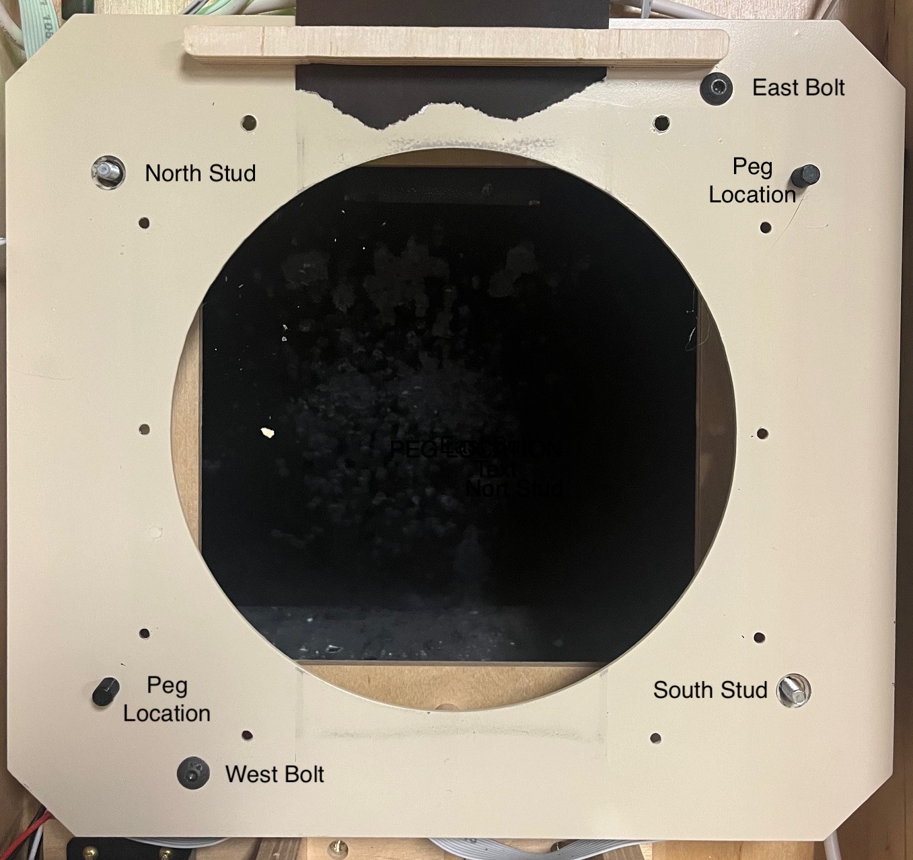
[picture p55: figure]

Figure 1: Component Location

- Insert the alignment pegs as shown in Figure 2. The pegs will be slightly tight but will install with a light tap.
- From the back, hold the peg in place with the grommet as shown in Figure 3. The grommet will have a tight fit and may need to be pushed into place with a light hammer

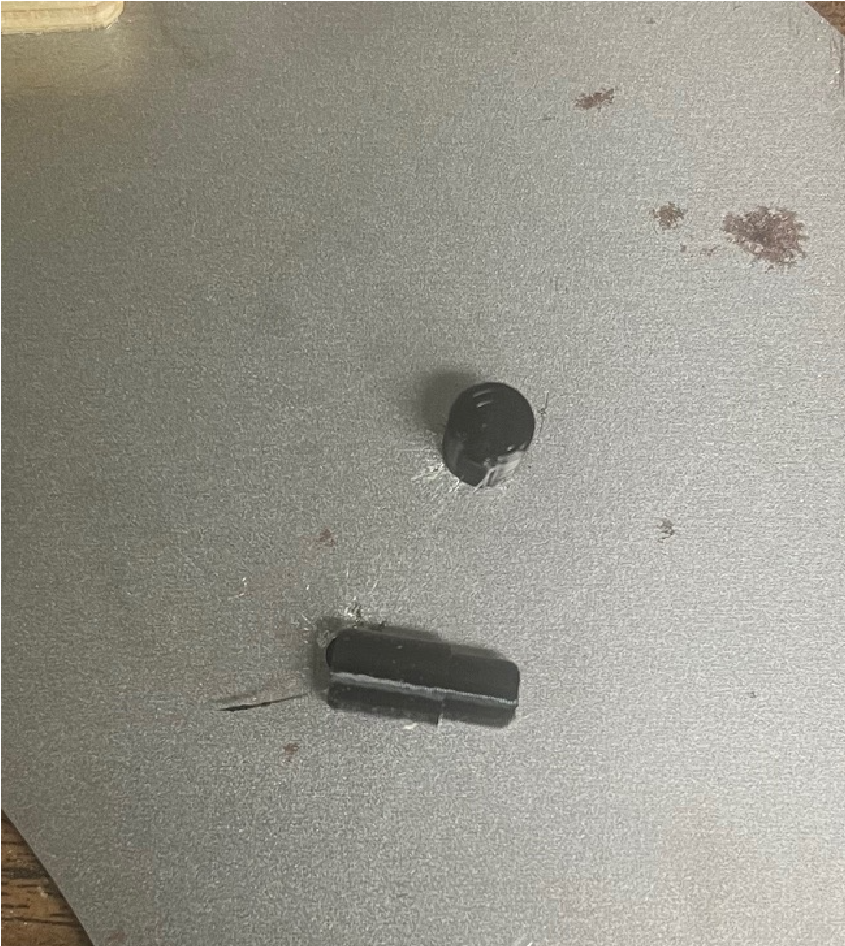
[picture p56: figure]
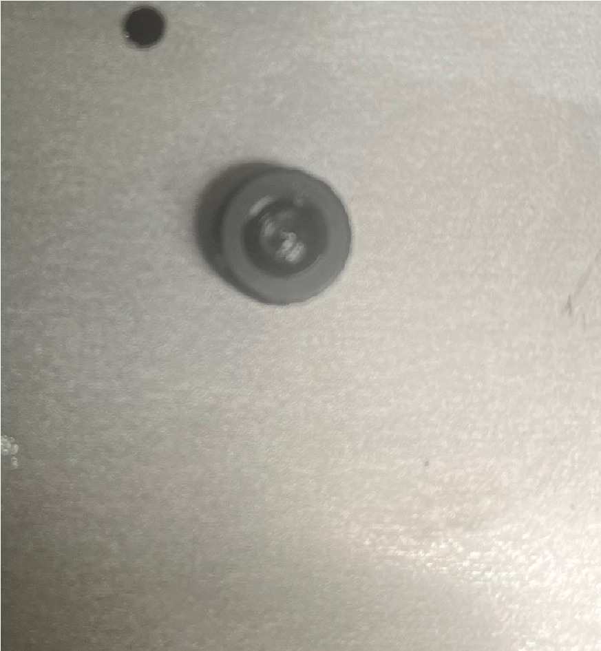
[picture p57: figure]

Figure 2: Aligment Peg | Figure 3: Retention Grommet

- Reattach the plate to the target using the East and West bolts, same as a regular target
- From the rear, insert the 50mm bolts through the sensor mount. When finished about 10mm should protrude.

# INSTALLING TARGETS

The target is assembled onto the target plate as shown in Figure 4.

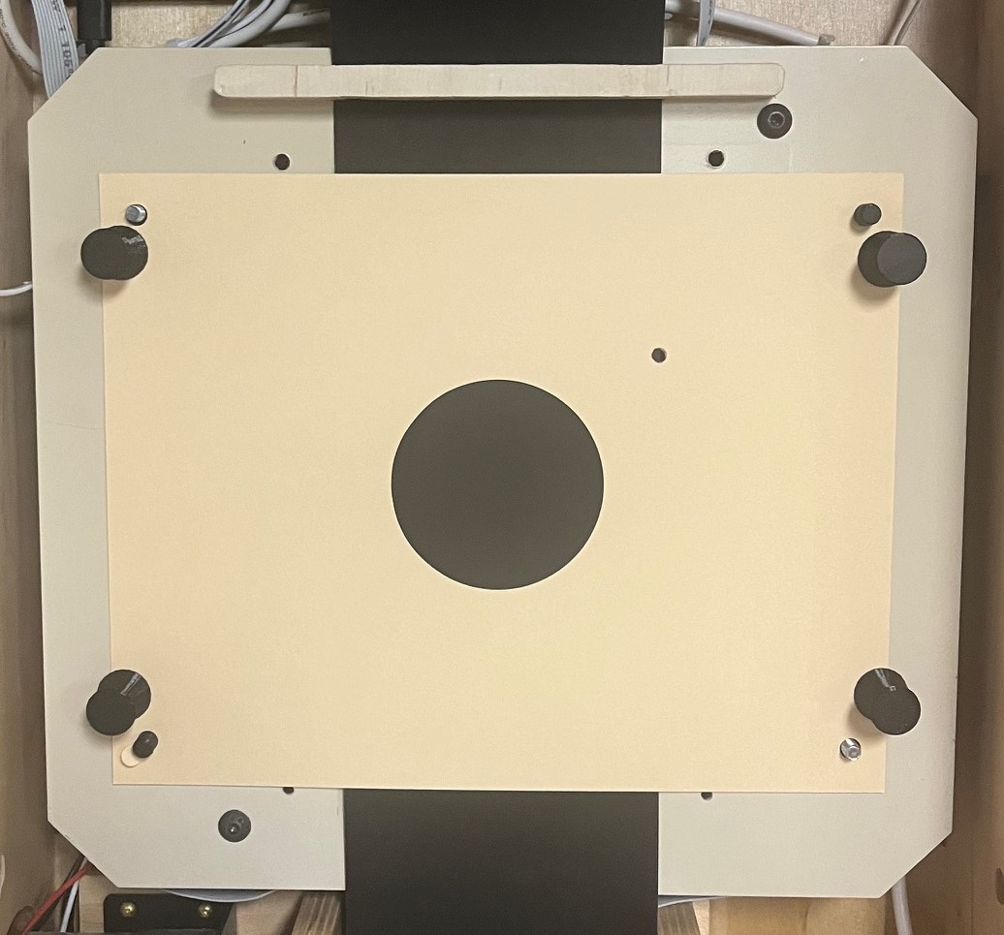
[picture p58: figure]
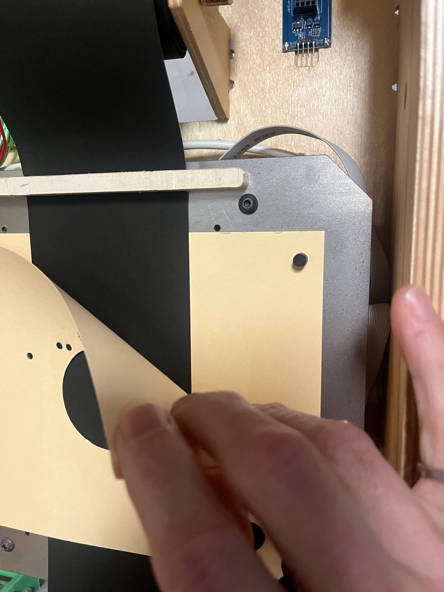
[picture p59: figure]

| | Target Plate Suis target backer Witness paper Fresh Suis target Magnets or tape to hold it in place

Figure 4: Target Assembly

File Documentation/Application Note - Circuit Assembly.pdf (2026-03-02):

FREETARGET

## Fabricatioin Instructions: Circuit Assembly and Test

INTRODUCTION

This document provides instructions for programming, assembly, and testing of a new circuit board from the assembly line. New circuit boards arrive unprogrammed meaning that they must programmed and configured before they will work. This is performed by the following steps

- Assemble into the target
- Flashing firmware – Putting software onto the board
- Selftest
- Serial number injection
- First Run

PREPARATION

Before beginning the assembly, the following software packages are required

- FreeETarget PC Client
- Dog training clicker (Amazon ASIN B0CS3MG3BQ or similar)

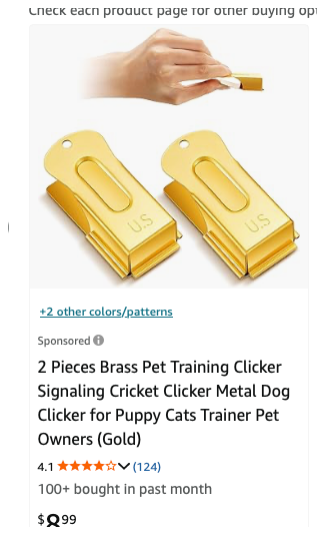
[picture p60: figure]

ASSEMBLE AND TEST

Assemble Into the Target

Assemble the circuit into the target as you normally would; circuit, sensors, cable, witness paper drive, LED illumination, and USB cable

Flash Firmware

Using the PC Client, connect to the circuit as normal, and download the production software into the circuit board.

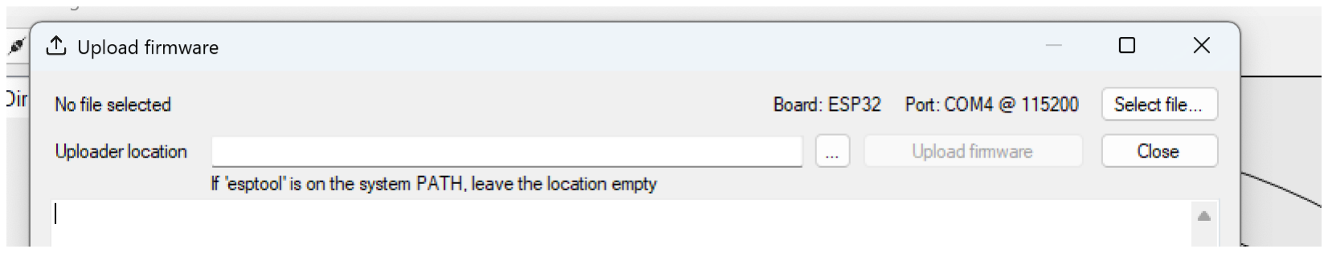
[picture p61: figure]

Use the freeetarget.bin file

IMPORTANT

- Each circuit will result in a new COM port being allocated, for example the first circuit would be COM3 while the second circuit would be COM4 and so forth
- The PC client recognizes the target only when launched. Attaching a second target requires that the PC client be closed and reopened.

Self Test

Once the firmware has been flashed, the circuit will restart itself and determine that this is the first time the software has been run. It will immediately enter a self test that allows you to ensure that the circuit works as expected.

- Connect to the target using the PC Client.
- The target will output some dialog and start the test

•

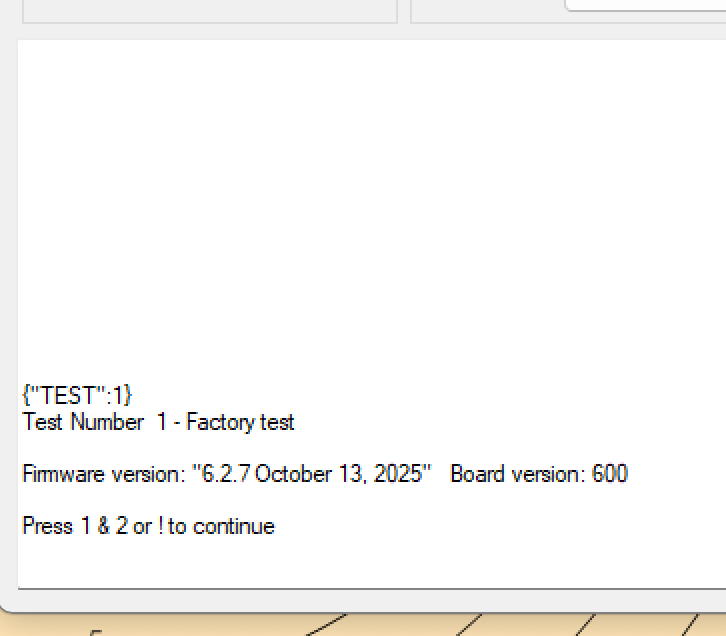
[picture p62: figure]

- Press and hold buttons 1 & 2 to start the test

•

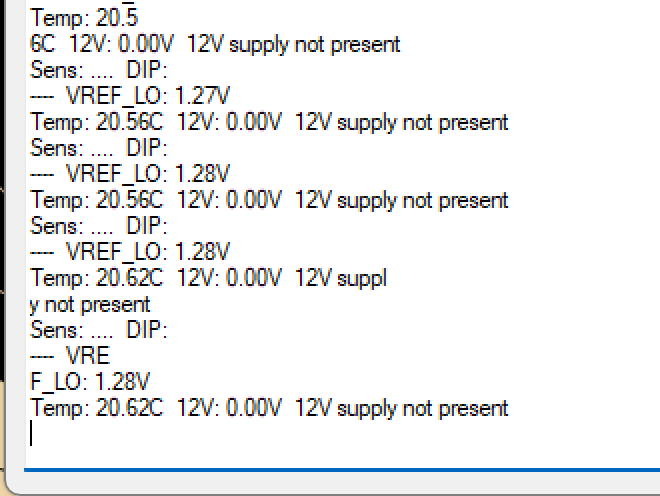
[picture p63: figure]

- The program will cyclically exercise the circuit
- The witness paper motor will advance in steps
- The LED illumination will get brighter and then go off
- The temperature should be approximately the room temperature
- The 12V supply should be nominally 12V
- VREF_LO should be nominally 1.25V
- Cover one of the sensors and click the dog clicker near the sensors
- The self test will report what sensors have detected the clicker
- Uncover the sensor and click the dog clicker
- The self test will report the ‘missing’ sensor
- The circuit passes if:
- All four sensors have detected sound
- Switches 1 and 2 were pressed
- VREF_LO is 1.25V +/- 0.125 volts
- V12 is between 10 and 14 volts
- The motor advances
- The LEDs change brightness
- The test reports PASS
- Press ! to end the test
- You will be prompted to enter the serial number
- Enter the serial number and press !

This completes the self test and the target will go into service.

- RDY LED blinks
- Console reports the startup sequence and ends with RUNNING

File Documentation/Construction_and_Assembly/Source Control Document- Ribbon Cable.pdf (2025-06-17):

FREETARGET

# Source Control Document: Ribbon Cable

## INTRODUCTION

This document describes the requirements for the freeETarget flat cable used to connect the control board to the four sensors.

## DRAWING

The ribbon cable consists of five IDC connectors and a ten-conductor ribbon as shown in Figure 1.

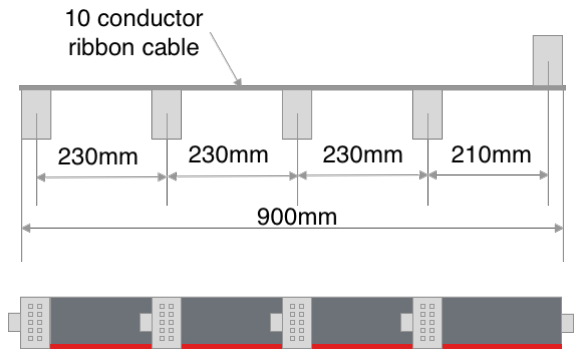
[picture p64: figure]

Figure 1: Ribbon Cable Assembly

Note the orientation of the connectors. The first four connectors are on one side, and the last one is on the opposite side.

BOM

Item | Qty | Description | Amazon P/N
1 | 5 | IDC Cable Connectors FC-10P | B00O9Y6FL6
1 | 900mm | 10 Conductor Flat Cable | B07P77YRB2

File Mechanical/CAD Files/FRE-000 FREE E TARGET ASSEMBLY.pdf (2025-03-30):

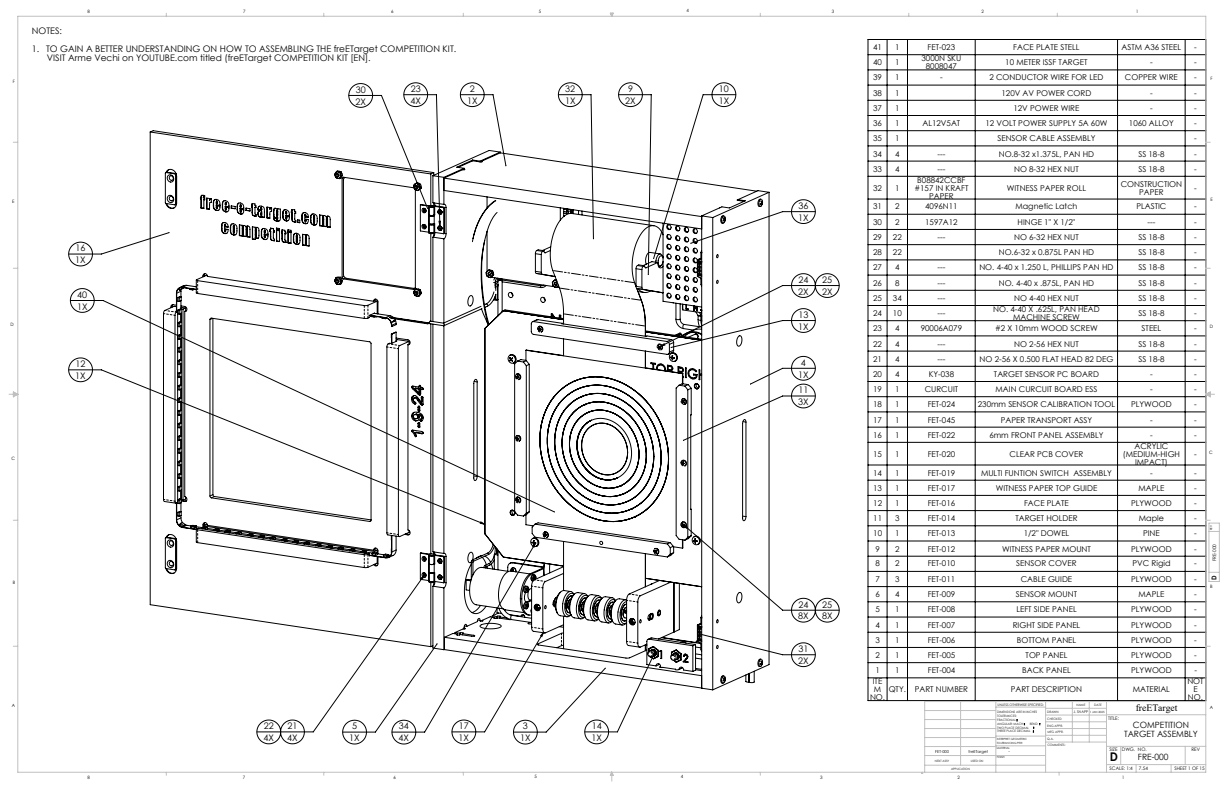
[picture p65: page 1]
FREV FRE-000; SHEET 1 OF 15; TARGET ASSEMBLY; J. SNAPP 1 JAN 2025; SCALE: 1:4 7.54; DWG. NO.; REV; freETarget NAME; DATE; MFG APPR.; ENG APPR.; INTERPRET GEOMETRIC TOLERANCING PER:; ANGULAR: MACH; BEND; NEXT ASSY; USED ON

NOTES:
1. TO GAIN A BETTER UNDERSTANDING ON HOW TO ASSEMBLING THE freETarget COMPETITION KIT.
VISIT Arme Vechi on YOUTUBE.com titled (freETarget COMPETITION KIT [EN].

41 | 1 | FET-023 | FACE PLATE STELL | ASTM A36 STEEL | -
40 | 1 | 3000N SKU 8008047 | 10 METER ISSF TARGET | - | -
39 | 1 | - | 2 CONDUCTOR WIRE FOR LED | COPPER WIRE | -
38 | 1 | | 120V AV POWER CORD | - | -
37 | 1 | | 12V POWER WIRE | - | -
36 | 1 | AL12V5AT | 12 VOLT POWER SUPPLY 5A 60W | 1060 ALLOY | -
35 | 1 | | SENSOR CABLE ASSEMBLY | | -
34 | 4 | --- | NO.8-32 x1.375L, PAN HD | SS 18-8 | -
33 | 4 | --- | NO 8-32 HEX NUT | SS 18-8 | -
32 | 1 | B08842CCBF #157 IN KRAFT PAPER | WITNESS PAPER ROLL | CONSTRUCTION PAPER | -

31 | 2 | 4096N11 | Magnetic Latch | PLASTIC | -
30 | 2 | 1597A12 | HINGE 1" X 1/2" | --- | -
29 | 22 | --- | NO 6-32 HEX NUT | SS 18-8 | -
28 | 22 | | NO.6-32 x 0.875L PAN HD | SS 18-8 | -
27 | 4 | --- | NO. 4-40 x 1.250 L, PHILLIPS PAN HD | SS 18-8 | -
26 | 8 | --- | NO. 4-40 x .875L, PAN HD | SS 18-8 | -
25 | 34 | --- | NO 4-40 HEX NUT | SS 18-8 | -
24 | 10 | --- | NO. 4-40 X .625L, PAN HEAD MACHINE SCREW | SS 18-8 | -
23 | 4 | 90006A079 | #2 X 10mm WOOD SCREW | STEEL | -
22 | 4 | --- | NO 2-56 HEX NUT | SS 18-8 | -
21 | 4 | --- | NO 2-56 X 0.500 FLAT HEAD 82 DEG | SS 18-8 | -
20 | 4 | KY-038 | TARGET SENSOR PC BOARD | - | -
19 | 1 | CURCUIT | MAIN CURCUIT BOARD ESS | - | -
18 | 1 | FET-024 | 230mm SENSOR CALIBRATION TOOL | PLYWOOD | -
17 | 1 | FET-045 | PAPER TRANSPORT ASSY | - | -
16 | 1 | FET-022 | 6mm FRONT PANEL ASSEMBLY | - | -
15 | 1 | FET-020 | CLEAR PCB COVER | ACRYLIC (MEDIUM-HIGH IMPACT) | -

14 | 1 | FET-019 | MULTI FUNTION SWITCH ASSEMBLY | - | -
13 | 1 | FET-017 | WITNESS PAPER TOP GUIDE | MAPLE | -
12 | 1 | FET-016 | FACE PLATE | PLYWOOD | -
11 | 3 | FET-014 | TARGET HOLDER | Maple | -
10 | 1 | FET-013 | 1/2" DOWEL | PINE | -
9 | 2 | FET-012 | WITNESS PAPER MOUNT | PLYWOOD | -
8 | 2 | FET-010 | SENSOR COVER | PVC Rigid | -
7 | 3 | FET-011 | CABLE GUIDE | PLYWOOD | -
6 | 4 | FET-009 | SENSOR MOUNT | MAPLE | -
5 | 1 | FET-008 | LEFT SIDE PANEL | PLYWOOD | -
4 | 1 | FET-007 | RIGHT SIDE PANEL | PLYWOOD | -
3 | 1 | FET-006 | BOTTOM PANEL | PLYWOOD | -
2 | 1 | FET-005 | TOP PANEL | PLYWOOD | -
1 | 1 | FET-004 | BACK PANEL | PLYWOOD | -
ITE M NO. | QTY. | PART NUMBER | PART DESCRIPTION | MATERIAL | NOT E NO.

UNLESS OTHERWISE SPECIFIED:

DIMENSIONS ARE IN INCHES
TOLERANCES:
FRACTIONAL
TWO PLACE DECIMAL
THREE PLACE DECIMAL

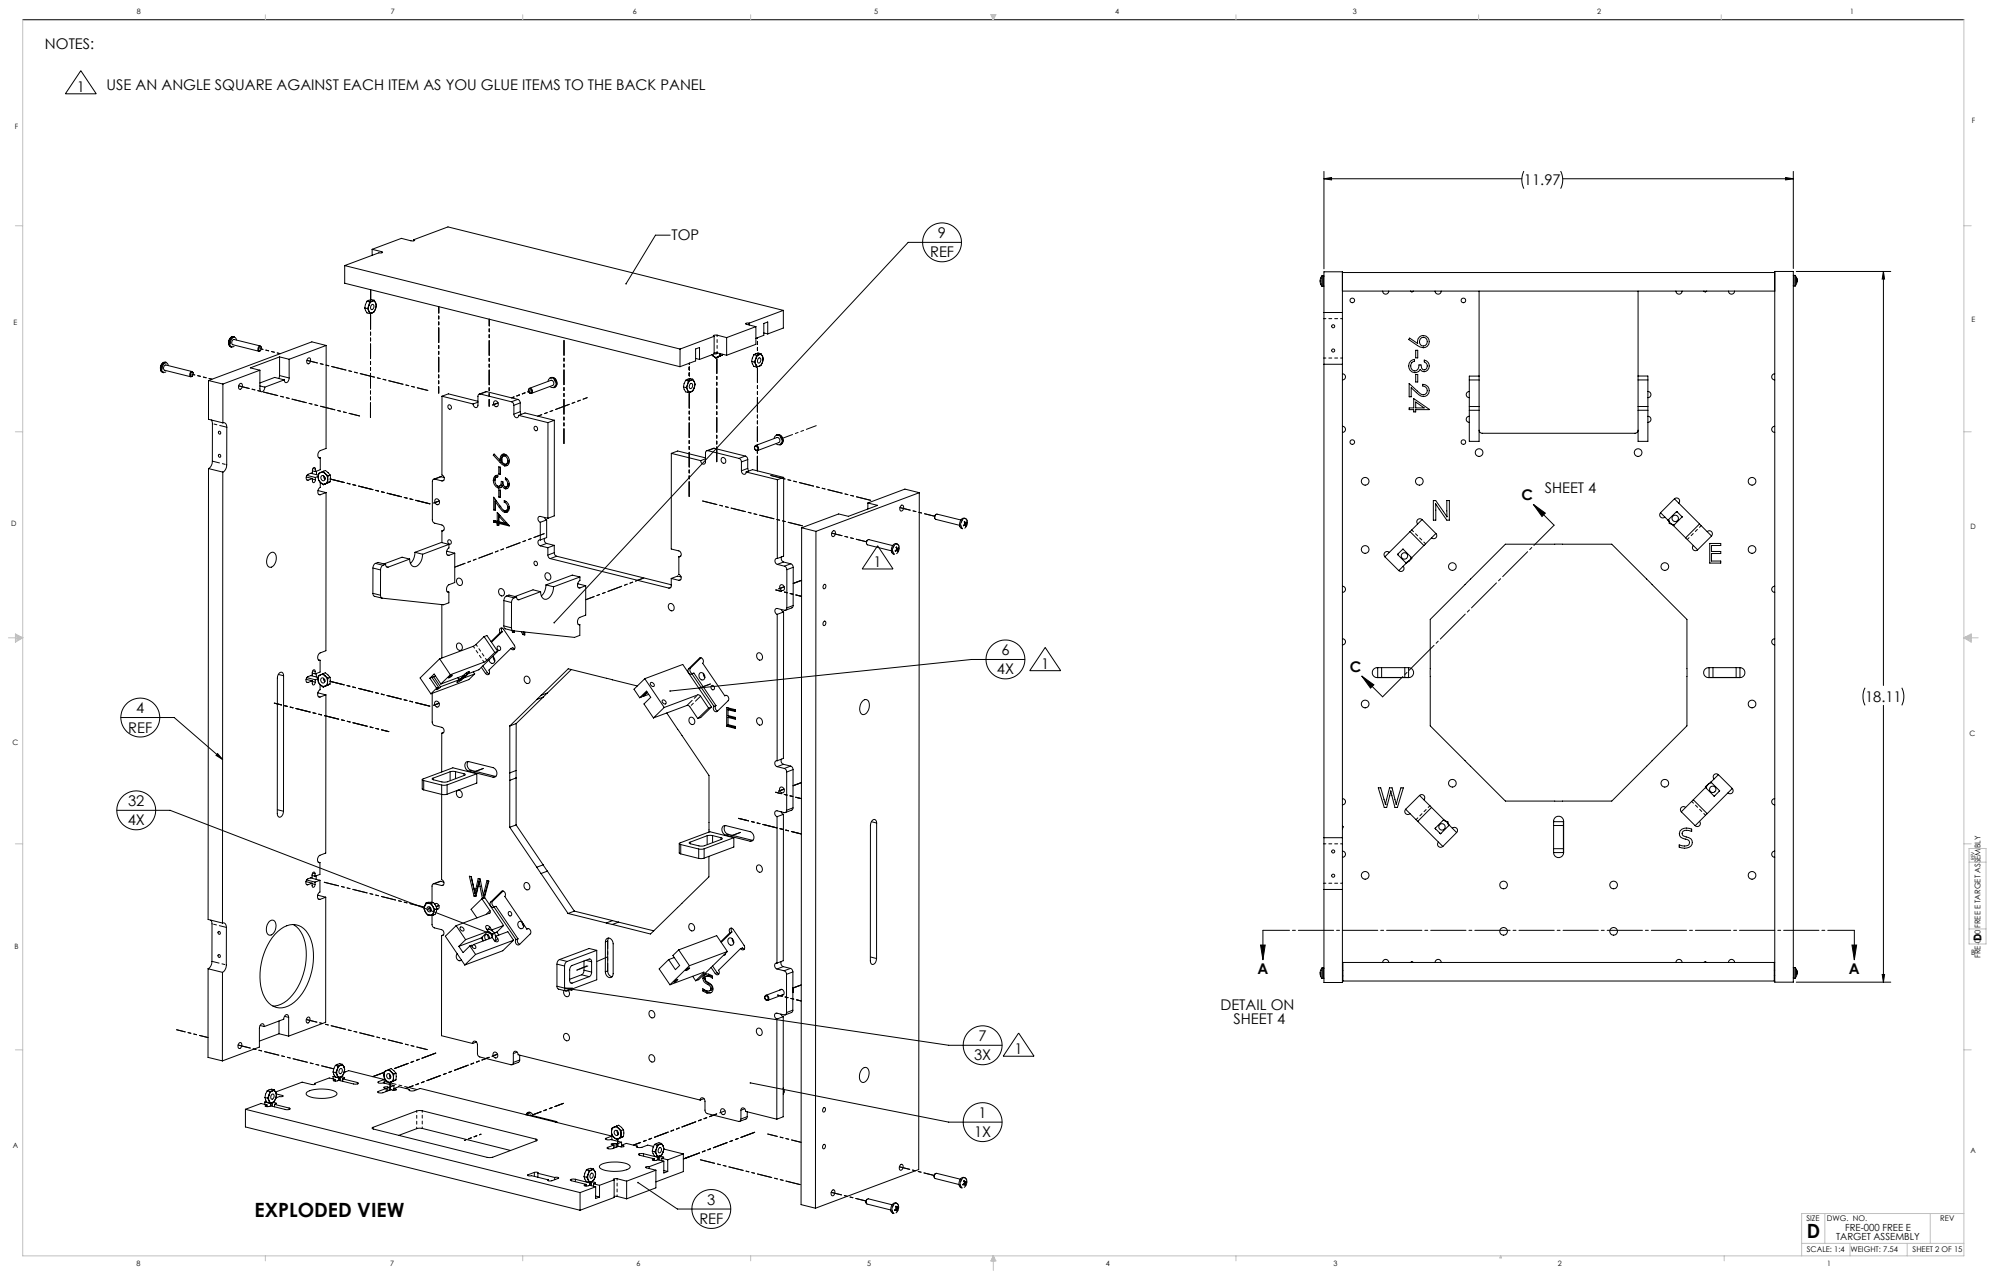
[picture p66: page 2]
C SHEET 4; EXPLODED VIEW; DETAIL ON SHEET 4; FRE-000 FREE E; SCALE: 1:4 WEIGHT: 7.54; SHEET 2 OF 15

USE AN ANGLE SQUARE AGAINST EACH ITEM AS YOU GLUE ITEMS TO THE BACK PANEL

FREV FRE-000 FREE E TARGET ASSEMBLY D

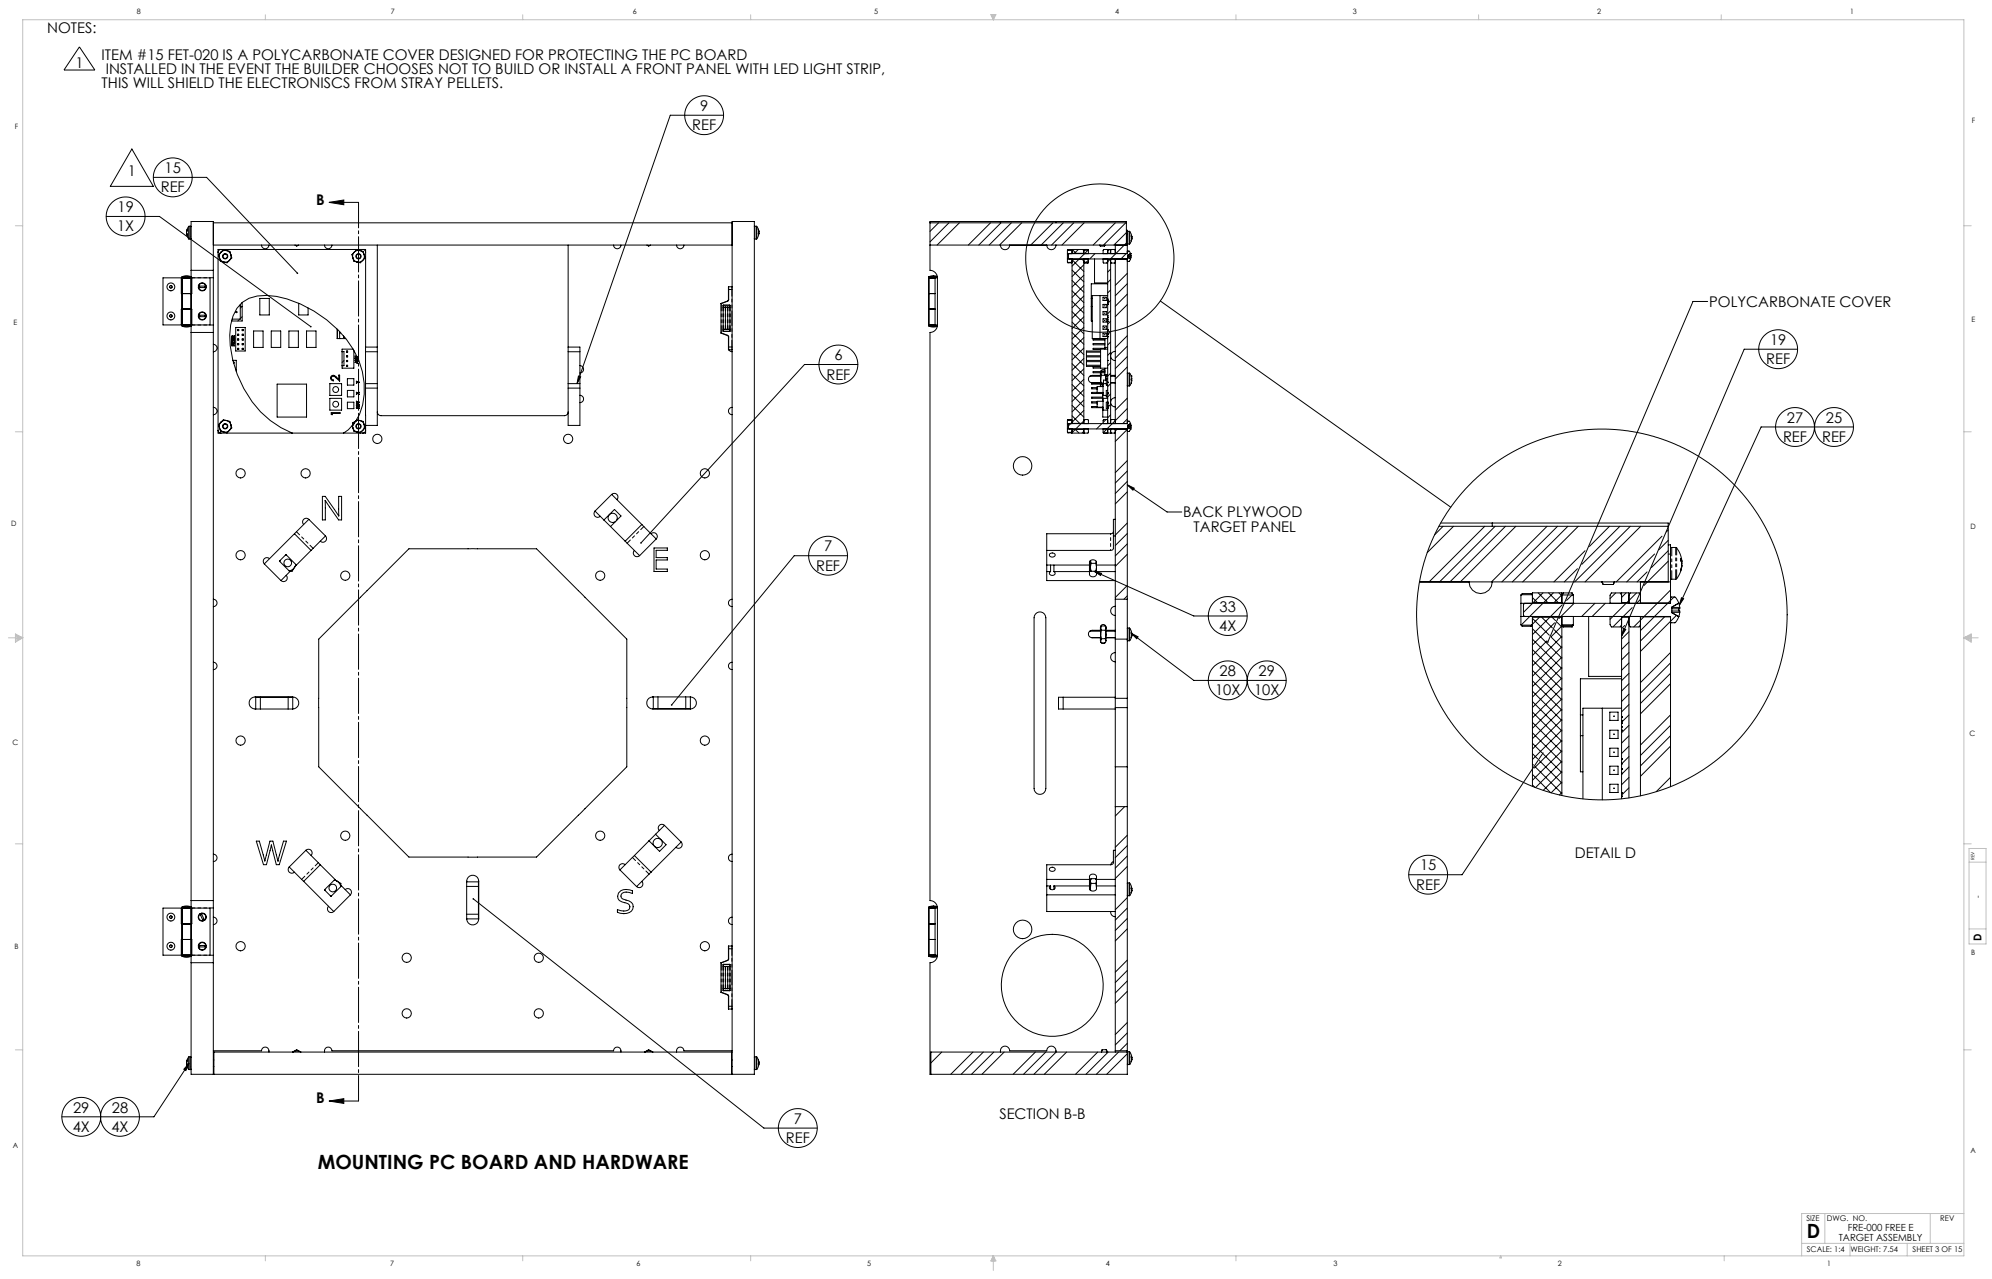
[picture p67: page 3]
SECTION B-B; BACK PLYWOOD TARGET PANEL; DETAIL D; POLYCARBONATE COVER; SCALE: 1:4 WEIGHT: 7.54; SHEET 3 OF 15

NOTES:
ITEM #15 FET-020 IS A POLYCARBONATE COVER DESIGNED FOR PROTECTING THE PC BOARD
INSTALLED IN THE EVENT THE BUILDER CHOOSES NOT TO BUILD OR INSTALL A FRONT PANEL WITH LED LIGHT STRIP,
THIS WILL SHIELD THE ELECTRONISCS FROM STRAY PELLETS.

MOUNTING PC BOARD AND HARDWARE

SECTION A-A; DETAIL D; 6-32 X 7/8" PAN HEAD; 6-32 NUT; SECTION C-C; SEE NOTE 1; SEE NOTE 2; SEE NOTE 3; CABLE GUIDES ARE GLUED IN ONLY NO SCREW HOLES ARE PROVIDED.; SCALE: 1:1 WEIGHT: 7.54; SHEET 4 OF 15

1 SENSOR MOUNTS ARE GLUED IN AS SHOWN . HOLES ARE PROVIDED SO
BUILDER CAN USE ADDITIONAL SCREWS.
3 INSTALL 4 8-32 NUTS INTO THE 4 SENSOR SUPPORTS.

FREV FRE-000 FREE E TARGET ASSEMBLY D

EAST SENSOR; SOUTH SENSOR; WEST SENSOR; NORTH SENSOR; SECTION E-E; CABLE CONNECTOR; TARGET SENSOR; PC BOARDS; PROTECTIVE COVER; FINGER HOLES; WEIGHT: 7.54; SHEET 5 OF 15

NOTES:
1 MAKE YOUR OWN SENSOR
PACING TOOL BY USING
THE DRAWING AT THE RIGHT.
WHEN IN POSITION THE 4 LEGS
WILL POSITION THE CORNERS
IN THE PROPER POSITION.

SENSOR SPACING TOOL

SENSOR AND CABLE ASSEMBLY

DETAIL H; DETAIL G; DETAIL J; 120V POWER; 12 VOLT DC TO; SECTION F-F; WEIGHT: 7.54; SHEET 6 OF 15

THIS WIRE RUNS TO (+) AND (-)
ON PCB MOTOR CONNECTOR
SEE SHEET 11 FOR WIRING DIAGRAM

RED WIRE TO +

BLACK WIRE TO -

ESS PC BOARD

WIRING POWER SUPPLY CONNECTIONS TO PC BOARD WITNESS PAPER DRIVE

GRAY WIRE OPPOSITE PIN A; YELLOW WIRE OPPOSITE PIN B; SECTION L-L; SWITCH 1; DETAIL M; SWITCH 2; WIRES GRAY / BLUE; WIRES RED / YELLOW; DETAIL N; BLUE WIRE CONTACT PIN A; RED WIRE CONTACT PIN B; SECTION K-K; WEIGHT: 7.54; SHEET 7 OF 15

THIS SHEET SHOWS THE WIRING OF THE MULTIFUNCTION SWITCHES.
SEE SHEET 13 FOR CLEARER WIRING DIAGRAM.

4 WIRE CONDUCTOR
RUN ALONE BOTTOM
PLATE

DETAIL R; DETAIL P; SCALE: 1:2 WEIGHT: 7.54; SHEET 8 OF 15

1. TO WIRE THE LED STRIP LOCATE A 2 CONDUCTOR WIRE. CONNECT THE RED WIRE TO (+) TERMINAL ON THE PC BOARD
CONNECT THE BLACK WIRE TO (-) CONNECTOR ON THE PC BOARD. RUN THE WIRE IN ANY METHOD YOU CHOOSE. THE
EXAMPLE SHOWN IS THIS DESIGNERS CHOICE, YOU RUNS YOU HOW EVER YOU WISH.
2. SOLDER THE SECOND OF THE WIRES TO THE (+) AND (-) SOLDER POINTS ON THE LED STRIP AND GIVE YOUR SELF ENOUGH
WIRE SO NOT TO STRAIN IT WHEN OPENING THE FRONT PANEL. SEE SHEET 12 FOR CLEARER WIRING DIAGRAM.

FREV FRE-000 FREE E TARGET ASSEMBLY D

RED LED WIRE INTO +

BLACK LED WIRE INTO -

LED WIRE PATH
ROUTED AROUND
THE PC BOARD

DRAWING OF WIRING THE LED

SCALE: 1:4 WEIGHT: 7.54; SHEET 9 OF 15

ISOMETRIC EXPLODED VIEW
WITH RIGHT SIDE AND TOP PANEL
HIDDEN FOR CLARITY

120 VOLTS AC; NEUTRAL WIRE; LINE VOLTAGE; GROUND WIRE

BLACK WIRE TO (-)

RED WIRE TO (+)

RED WIRE TO (+) SCREW

BLACK WIRE TO (-) SCREW

WIRING 12 VOLT POWER SUPPLY TO ESS PC BOARD

SCALE: 1:1 WEIGHT: 7.54 SHEET 10 OF 15

BLACK WIRE TO (-) TERMINAL; RED WIRE TO (+) TERMINAL

BLACK WIRE TO (-) TERMINAL

RED WIRE TO (+) TERMINAL

WIRING WITNESS PAPER DRIVE ASSEMBLY

SCALE: 1:2 WEIGHT: 7.54 SHEET 11 OF 15

LED STRIP; BLACK WIRE TO (-) TERMINAL; RED WIRE TO (+) TERMINAL

12 VOLT LED STRIP

LED WIRING TO ESS PCB

SOLDER WIRE TO MARKED SOLDER POINTS
MARKED ON THE LED STRIP

SCALE: 1:2 WEIGHT: 7.54 SHEET 12 OF 15

N.O. PUSH BUTTON; WHITE WIRE; BLUE WIRE; RED WIRE; YELLOW WIRE

22 OR 24 GAUGE WIRE 4 CONDUCTOR

WIRING MULTI FUNCTION SWITCHES TO PCB

SCALE: 1:1 WEIGHT: 7.54 SHEET 13 OF 15

WEST CONNECTOR; EAST CONNECTOR; SOUTH CONNECTOR

RIBBON CABLE CONNECTION

ESS CIRCUIT BOARD

NORTH SENSOR PCB

EAST SENSOR PCB

RIBBON CABLE WITH
CONNECTOR FOR EACH

MOUNT SENSORS ONTO SENSOR MOUNTS (NOT SHOWN)
AND PLUG IN EACH PLUG FROM RIBBON CABLE MAKING
SURE EACH CONNECTION MATCHES THE LABLING.
NORTH TO NORTH, SOUTH TO SOUTH ON SO ON.

WEST SENSOR PCB

SOUTH SENSOR PCB

- WEIGHT: 7.54 SHEET 14 OF 15

OPTION 2 DESIGN

10 METER (5) SHOT TARGETS STRIP
EDELMANN (5) TARGET STRIP

SLOT CUT INTO BOTH BOTH SIDES FOR THE
COMPETITION HOUSING TO ACCEPT THE
EDELMANN (5) TARGET STRIP.

PURCHASE 10 METER (5 ) TARGET STRIP AND USE THEM TO SAVE ON 10 METER ISSF TARGETS.

SCALE: 1:4 WEIGHT: 7.54 SHEET 15 OF 15

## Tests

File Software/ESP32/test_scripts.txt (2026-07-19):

//
// WIFI Tests 
//
Static IP  { "WIFI_SSID": "googlefiber",  "WIFI_PWD": "kansas6108", "NAME_ID": 100, "NAME_TEXT":"ENGINEERING", "WIFI_IP":"192.168.86.109" }
Static IP  { "WIFI_SSID": "googlefiber",  "WIFI_PWD": "kansas6108", "NAME_ID": 100, "NAME_TEXT":"NEXUS", "WIFI_IP":"192.168.86.109" }
Static IP  { "WIFI_SSID": "googlefiber",  "WIFI_PWD": "kansas6108", "NAME_ID": 100, "NAME_TEXT":"62I", "WIFI_IP":"192.168.86.111" }
Static IP  { "WIFI_SSID": "COMET", "WIFI_IP":"192.168.0.103", "WIFI_GATEWAY":"192.168.0.1" }
Default IP { "WIFI_SSID": "", "WIFI_IP":"192.168.0.103", "WIFI_GATEWAY":"192.168.0.1" }
Dynamic IP { "WIFI_SSID": "googlefiber",  "WIFI_PWD": "kansas6108", "NAME_ID": 100, "NAME_TEXT":"ENGINEERING"}
{ "NAME_ID": 99, "NAME_TEXT":"ALLAN"}
{ "NAME_ID": 101}
HTTP Trace             {"TRACE":128}
Reset the target       {"RESET":0}
Reinitialize the board {"INIT":0}

{ "WIFI_SSID": "",  "WIFI_PWD": "", "NAME_ID": 4}

//
// Witness Paper Settings 
//
Practice witness paper { "PAPER_TIME":250, "PAPER_ECO":30, "PAPER_SHOT":4}
Practice witness paper { "PAPER_TIME":250, "PAPER_ECO":40, "PAPER_SHOT":2}
Practice witness paper { "PAPER_TIME":125, "PAPER_ECO":40, "PAPER_SHOT":4}

{ "AUTH_CODE":1234,  "AUTH_CODE":4321}
{ "AUTH_CODE":1234, "AUTH_CODE":0, "ECHO":0 }
{"WIFI_SSID":"FSixC! Box FE":, "WIFI_PWD":":1234512345123451234512345"}

Firmware debug trace   { "TRACE":16, "TRACE":32, "TRACE":64, "TEST":142}
Calculation debug trace {"TRACE": 2048, "TRACE":8, "TRACE":64}
Rapid Fire {"TRACE":2048}
Turn on RS488 {"AUX_MODE":8}

//
// Rapid Fire and Tabata 
//
Output for Rapid Fire  { "MFS_HOLD_C":18, "MFS_HOLD_D":20, "MFS_SELECT_CD":24}
LED control { "MFS_HOLD_C":18, "MFS_HOLD_D":20, "MFS_SELECT_CD":24}
ISSF 50m Rapid Fire       Five shots into a single target            {"TRACE":2048, "EVENT":"RFP Allan", "RAPID_COUNT":5,  "RAPID_TIME":8,   "RAPID_WAIT":5, "RAPID_ENABLE":0}
ISSF 50m Rapid Fire       Five shots into a single target            {"TRACE":2048,  "EVENT":"RFP Allan", "RAPID_COUNT": 1 , "RAPID_WAIT":3, "RAPID_TIME":8, "RAPID_ENABLE": 1 }
ISSF 50m Rapid Fire       No Trace                                   {"TRACE":2048, "EVENT":"RFP Allan", "RAPID_COUNT": 1 , "RAPID_WAIT":3, "RAPID_TIME":8, "RAPID_ENABLE": 1 }
ISSF 50m Rapid Fire       Five shots into a single target            {"TRACE":2048, "EVENT":"Rapid Fire 8S",      "RAPID_COUNT":5,  "RAPID_TIME":8,   "RAPID_WAIT":5, "RAPID_ENABLE":1}ISSF 25m Standard Pistol  Five shots into a single target           
 {"RAPID_REPEAT":5} 
 {"TRACE":2048, "EVENT":"Rapid Fire 30s",     "RAPID_COUNT":5,  "RAPID_TIME":30,  "RAPID_WAIT":5, "RAPID_ENABLE":1}
 
 {"TRACE":2048, "EVENT":"Rapid Fire 8S", "RAPID_COUNT":5, "RAPID_WAIT":7, "RAPID_TIME":50, "RAPID_ENABLE": 1 }

NRA Sport Pistol ON         One shot into a single target, repeat 5x {"TRACE":2048, "EVENT":"SPP Allan", "RAPID_COUNT":1,  "RAPID_TIME":3,   "RAPID_WAIT":7, "RAPID_ENABLE":1}
                                                                     {"TRACE":2120, "EVENT":"SPP Allan", "RAPID_COUNT":1,  "RAPID_TIME":3,   "RAPID_WAIT":7, "RAPID_ENABLE":1}
NRA Sport Pistol OFF        One shot into a single target, repeat 5x {"TRACE":2048, "EVENT":"SPP Betty", "RAPID_COUNT":1,  "RAPID_TIME":3,   "RAPID_WAIT":7, "RAPID_ENABLE":0}
NRA Sport Pistol ON         One shot into a single target, repeat 5x {"RAPID_COUNT":1,  "RAPID_TIME":3,   "RAPID_WAIT":7, "RAPID_ENABLE":1}

Tabata                      Tabata timing                            {"TRACE":2048, "EVENT":"Tabata",  "RAPID_COUNT": 1 , "RAPID_WAIT":3, "RAPID_TIME":7, "RAPID_ENABLE": 1 }
Done {"RAPID_ENABLE":0}

Turn Tabata on by switch   {"MFS_TAP_1":6}

//
// MFS Operation
//
PC Shot Test {"MFS_TAP_1":4 }
{"}
Start a download {"DOWNLOAD":1234567}
RS485 {"AUX_MODE":8}

{"ECHO":0}

//
// Calibration Tests 
//
Raw
{"CAL":1, "CAL":8, [-55.24, -61.51, 18.04, 78.51, -35.96, -43.34, -12.31, -35.85, 25.12, 40.27, -17.49, 32.01, -16.46, -29.50, 15.00, -65.67, -52.11, 22.98, -21.67, -16.85, 35.60, -41.26, 29.78, -24.88, 30.48, 91.39, -51.31, -0.62, -26.73, 21.00, -55.49, 10.10, 29.73, 14.96,  22.81, -23.55, -41.35, -7.55]}

Target Scan
{"CAL":2}
1
"1","1","7.7","-21.03","-15.66"
"2","1","6.9","-15.21","-28.20"
"3","1","6.5","-11.33","-33.89"
"4","1","6.4","-17.67","32.17"
"5","1","6.3","30.30","-21.61"
"6","1","4.9","23.84","42.26"
"7","1","4.3","36.51","-38.42"
"8","1","4.1","-34.60","-42.56"
"9","1","3.9","-51.80","22.48"
"10","1","3.0","16.47","-61.17"
"11","2","9.8","-0.24","-9.43"
"12","2","7.8","-8.49","-23.85"
"13","2","7.1","22.33","-20.86"
"14","2","6.8","28.63","17.05"
"15","2","6.6","-26.95","21.98"
"16","2","5.8","-41.04","-6.76"
"17","2","4.6","-50.76","0.22"
"18","2","3.9","-55.14","10.89"
"19","2","0.0","19.04","78.51"
"20","2","0.0","-56.24","-61.51"
!

Table Data
{"CAL":2}
2
-21.03, -15.66, -15.21, -28.20, -11.33, -33.89, -17.67, 32.17, 30.30, -21.61, 23.84, 42.26, 36.51, -38.42, -34.60, -42.56, -51.80, 22.48, 16.47, -61.17, -0.24, -9.43, -8.49, -23.85, 22.33, -20.86, 28.63, 17.05, -26.95, 21.98, -41.04, -6.76, -50.76, 0.22, -55.14, 10.89!

Commit Calibration {"CAL":3}

Show Calibration {"CAL":4}

void Calibration {"CAL":5}

ESPEFUSE

>ESPEFUSE adc_info --port COM3 --baud 115200

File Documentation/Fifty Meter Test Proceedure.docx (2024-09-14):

FreeETarget

Fifty Meter

Test Procedure

# SUMMARY

This document is the test procedure for validating FreeEtarget operation using 22cal ammunition on a fifty meter target

The purpose of the test is to validate different target materials and the performance of the target sensors. Particular emphasis on determining the tolerance between making and missing a shot.

The document is made up as:

Required Equipment – What is needed to perform the test

Rifle Target – Dimensions and materials for rifle targets

Pistol Target – Dimensions and materials for pistol targets

Ammunition – Spread between competion target and plinking ammunition

## APPLICABLE DOCUMENTS

ISSF Rule Book: https://usashooting.org/app/uploads/2022/04/2013_USAS_GTR.pdf

Sections 6.3.4.2 50 Meter Rifle Target

https://backoffice.issf-sports.org/getfile.aspx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

# REQUIRED EQUIPMENT

The following are required for the test

Item | Quantity | Description
1 | 1 | Oscilloscope
2 | 1 | Test cable harness
3 | 1 | PC with development software
4 | 1 | USB interface
5 | 2 | 150 Foot Cat 5 cable
6 | 1 | FreeETarget Air Pistol, 165 dia
7 | 1 | FreeETarget Pistol Target, 500mm dia
8 | 10 | 50 meter rifle target (10 meter air pistol target may be used
9 | 10 | 50 meter pistol target
10 | 1 | 22Cal rifle
11 | 1 | 22 Cal pistol
12 | 50 | Target velocity rifle ammunition
13 | 50 | High velocity rifle ammunition
14 | 50 | Target pistol ammunition
15 | 50 | High velocity pistol ammunition
16 | 1 | Notebook
17 | 5 | Thin rubber material
18 | 5 | Thick rubber material
19 | 1 | WiFi router

# RiFLE Target

The specifications for a 50meter rifle target are provided below

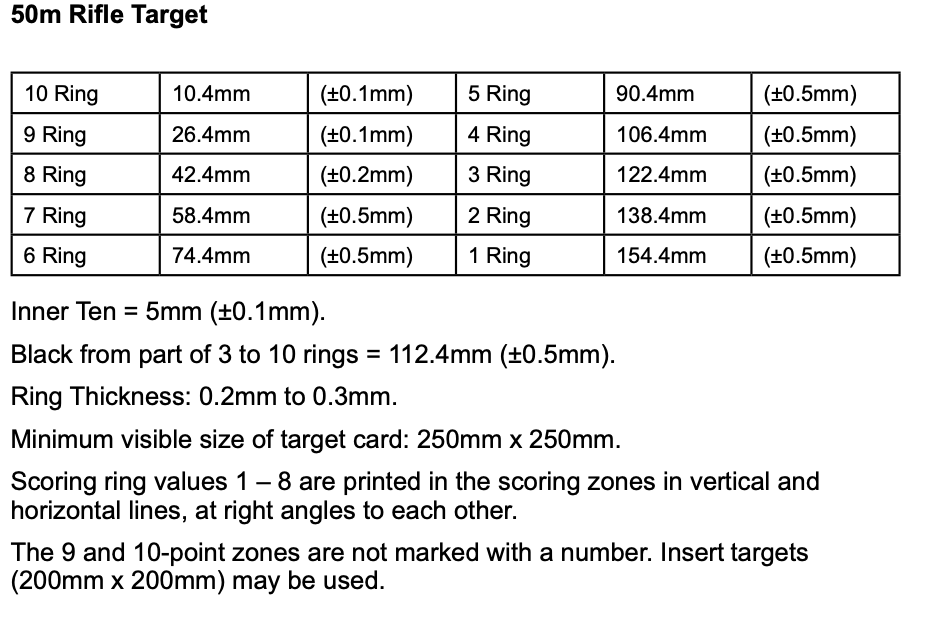
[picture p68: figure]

For the purposes of this test, a 10 meter pistol target may be used

# 25m Precision and 50m Pistol Target

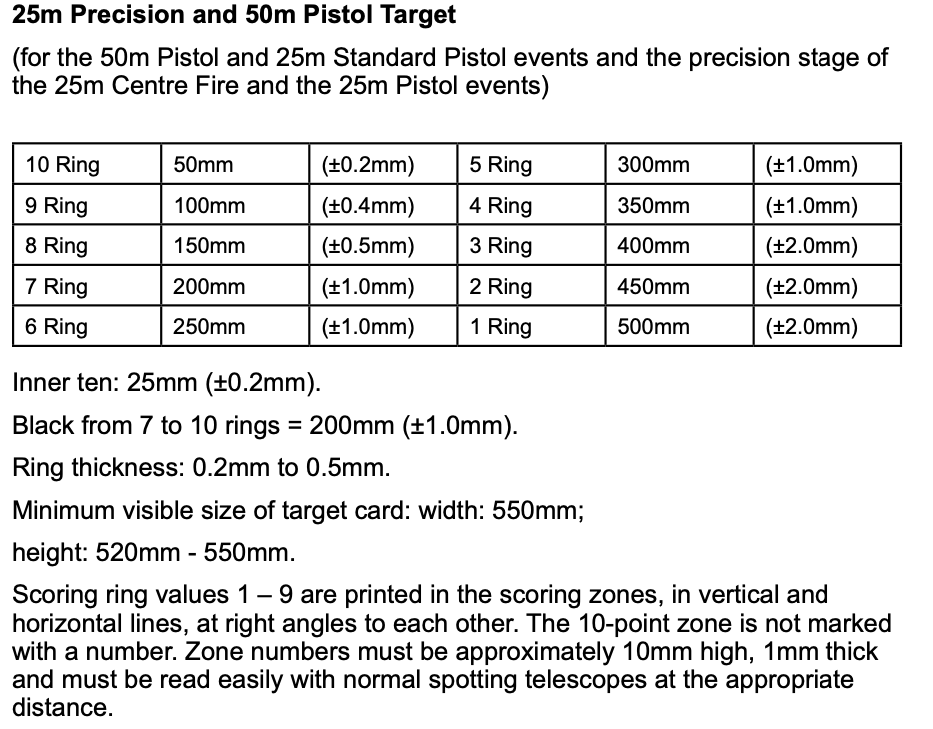
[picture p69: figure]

# Test Procedure (RIFLE)

- Setup the target 50 meters from the firing point
- Connect the sensor cable harness to the oscilloscope
- Connect the oscilloscope to the PC using one of the 150 foot ethernet cables
- Open a web browser and connect to the target
- Connect the target to the PC using one of the 150 foot ethernet cables.
- Launch the Visual Studio program to monitor the internals of the target
- Connect target to the using a WiFI connection
- Launch the PC client
- Verify that all connections are working
- For each test on the test data sheet, record the required data

The test is performed by arming the oscilloscope and firing a shot into the approximate ring location. The actual location of the shot does not need to be accurate.

Once fired, the following are recorded

- Computed shot location
- Actual shot location
- Amplitude of each of the sensors North to West

A shot is deemed a success if the target recognizes the shot and computes a location for the shot.

A test may be abandoned if it fails to identify three or more shots into the target

## RIFLE TEST

Using 10 meter air rifle target

### Simple Test Fire, Paper Target, Target Rifle Ammunition

Test | Aiming Point | EST Score | Paper Score | North | Eash | South | West
1 | 10 ring
2 | 9
3 | 8
4 | 7
5 | 6
6 | 5
7 | 4
8 | 3
9 | 2
10 | 1

Notes

### Simple Test Fire, Rubber ROLL Target, Target Rifle Ammunition

Test | Aiming Point | EST Score | Paper Score | North | Eash | South | West
1 | 10 ring
2 | 9
3 | 8
4 | 7
5 | 6
6 | 5
7 | 4
8 | 3
9 | 2
10 | 1

Notes

### Simple Test Fire, DENSE RUBBER MAT, Target Rifle Ammunition

Test | Aiming Point | EST Score | Paper Score | North | Eash | South | West
1 | 10 ring
2 | 9
3 | 8
4 | 7
5 | 6
6 | 5
7 | 4
8 | 3
9 | 2
10 | 1

Notes

Based on the results of the target velocity ammunition, repeat one or more tests using supersonic ammunition

### Simple Test Fire, Paper Target, Supersonic Ammunition

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

Notes

### Simple Test Fire, RUBBER ROLL, SUPERSONIC Ammunition

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

Notes

### Simple Test Fire, RUBBER MAT, SUPErSONIC Ammunition

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

Notes

## PISTOL TEST

Using 500 mm test grid

### Simple Test Fire, Paper Target, Target Pistol Ammunition

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

Notes

### Simple Test Fire, Rubber ROLL Target, Target PISTOL Ammunition

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

Notes

### Simple Test Fire, DENSE RUBBER MAT, TargetPISTOL Ammunition

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

Notes

Based on the results of the target velocity ammunition, repeat one or more tests using supersonic ammunition

### Simple Test Fire, Paper Target, Supersonic Ammunition

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

Notes

### Simple Test Fire, RUBBER ROLL, SUPERSONIC Ammunition

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

Notes

### Simple Test Fire, RUBBER MAT, SUPErSONIC Ammunition

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

Notes

freETarget INTRODUCTION

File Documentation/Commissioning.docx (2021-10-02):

# freETarget

Application Note: Commissioning

SUMMARY

This application note describes the steps needed to put a freETarget into service and trouble shoot problems as they arise.

REQUIRED

- freETarget V2.1 or higher
- Firmware V3.0 or higher

INTRODUCTION

freETarget has built in test software that helps to identify problems in the installation and ensure correct operation.

IMPORTANT

Your freETarget was tested when it was assembled and arrived with the latest firmware and calibrated. Straight out of the box it should work first shot (pun intended).

INSPECTION

After you have assembled the freETarget into the target holder, inspect the following

- The flat cable is pressed firmly into the sensors and signal board
- There are no kinks or sharp bends in the flat cable.
- All of the sensors are correctly installed North through West

POWER ON

When powered on, the LEDs will go through a short cycle RDY – X – Y to indicate that the power has been applied, the software is valid, and the circuit is functioning. See Figure 1 to see the expected operation.

| | | RDY | X | Y
LED
Test
Cycle
Test Timer Circuit
Display Set Point | | | show | set | point
Ready for Operation

Figure 1: Power On Test Cycle

SENSOR TEST

At the beginning of each cycle, the software does a quick check to make sure that the hardware is ready for the next shot. If no errors are found, the RDY LED is illuminated and the circuit is ready to go. If a sensor is not detected, the fault LED is lit and the remaining LEDs are used to identify the faulty sensor

| | | RDY | X | Y
Ready for Operation
North Sensor Failed
East Sensor Failed
South Sensor Failed
West Sensor Failed

Figure 2: Sensor Fault Indication

If the sensors show ready for operation, tapping the face of the sensor will trigger a shot and indicate that the sensor is capable of detecting the projectile. In Figure 3, all of the LEDs are briefly illuminated to show that the shot was detected and sent to the PC.

| | | RDY | X | Y
Ready for Operation
Shot Detected
Ready for Next Shot

Figure 3: LEDs During and After a Shot

CONNECTING TO THE PC

Launch the PC program and make sure that the correct COM port has been selected.

- Press the Setup Icon (Gear Wheel)
- Inspect Hardware
- Verify that the correct COM port is used.
- Press the CONNECT button on the PC program
  - Does the program show CONNECTED?
  - The current firmware version and date is shown?
  - The competition timer starts running?
  - If the answer is no to any of these questions,
    - check the USB cables
    - the selected COM port
    - make sure the driver for the CH340 chip is loaded (google ch340 driver for instructions)

FIRST SHOT

From a distance of 10 meters, fire your first shot into the target.

- Does the shot register on the PC program?
  - No, check the cables and settings
  - Unplug the FACE sensor if it is plugged in

Fire a series of 9 more shots onto the target.

- Do all 10 shots show up on the display?
  - No, check the cables and settings
- Are the shots more-or-less in the correct place?
  - You’re done. Happy Shooting
- Are the shots correct, but the mirror image?
  - The sensors are installed correctly, but mirror image.
  - Swap North and East
  - Swap West and South
  - Go back to the beginning and test the circuit.
- Are the shots correct, but the reversed top and bottom?
  - The sensors are installed correctly, but upside down.
  - Swap North and West
  - Swap South and East
  - Go back to the beginning and test the circuit.

SET TRIGGER POINT

At this moment, your freETarget is working correctly. Once you get confident in how it works, you might want to change the trigger point and try to improve the accuracy. Refer to the Application Note: Setting the Trigger Point for more instructions.

TECHNICAL SUPPORT

If something goes wrong please send an email to free-e-target and we will try to resolve your problem

Before sending an email, please follow these steps, it will make things go a lot quicker

1. Go onto the PC program,
2. Connect to the target
3. Using the Arduino button, (upper right, small green circle icon) view the settings, example below
4. Send the screen shot of the settings

"NAME":"TARGET",

"ANGLE": 45,

"CALIBREx10": 45,

"DIP": 0,

"LED_BRIGHT": 50,

"MFS": 0,

"NAME_ID": 0,

"PAPER_ECO": 0,

"PAPER_TIME": 0,

"POWER_SAVE": 30,

"SEND_MISS": 0,

"SENSOR": 230.00,

"SN": 92,

"STEP_COUNT": 0,

"STEP_TIME": 0,

"TARGET_TYPE": 0,

"TEST": 0,

"Z_OFFSET": 0,

"NORTH_X": 0,

"NORTH_Y": 0,

"EAST_X": 0,

"EAST_Y": 0,

"SOUTH_X": 0,

"SOUTH_Y": 0,

"WEST_X": 0,

"WEST_Y": 0,

"IS_TRACE": 0,

"TEMPERATURE": 29.50,

"SPEED_SOUND": 0.35,

"V_REF": 1.01,

"TIMER_COUNT":5568,

"DIP_HEX": 0x0,

"WiFi": 1,

"VERSION": "3.04.11 October 2, 2021",

"BD_REV": 3.10

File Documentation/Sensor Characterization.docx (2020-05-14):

Sensor Characterization

This is a summary of the sensor designs and their performance

Design #1

Simple Inverting Amp

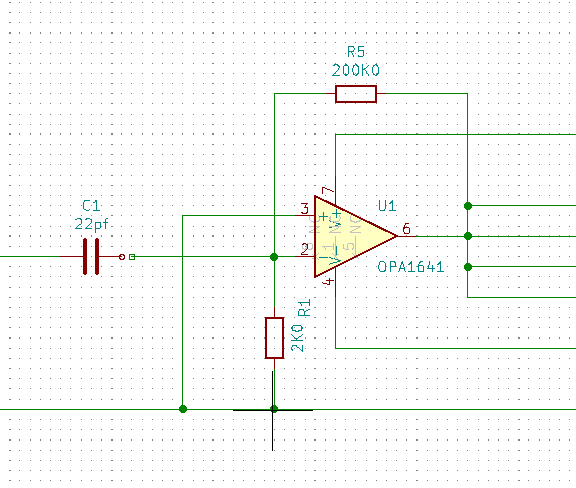
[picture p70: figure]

Figure 1: Simple Inverting Amp

This was the design used in Version 1.0X. The signal from the microphone is negative going on the leading edge, hence an inversion was done to flip the signal over and make it useable for the comparator on the circuit board.

Performance of this circuit was good, but very sensitive. Opening the air cylinder at 6 meters would trigger a detection. Moving the mouse on a table nearby would also generate a trip. Clearly too sensitive.

Design #2

Classical Inverting Amplifier

The pull down resistor was moved to be a series resistor, and set to 0Ohms. The 2K pull up resistor attached to the microphone acts as the current limit for the amplifier feedback

No apparent change in the sensitivity. Pulling trigger (click) would be detected at 6m.

Design #3

Feedback set to 47K0 Ohms

Does not detect trigger click at 6m, but does detect snapped fingers at about 1/2m

Does not detect mouse clicks on the table.

Setting threshold to 1V, all sensors detect snapped fingers.

Picks up the sound of the air rifle at 6m

Design #4

Feedback set to 10K0 Ohms

Does not trigger with air rifle discharge,

Will trigger with snapped fingers

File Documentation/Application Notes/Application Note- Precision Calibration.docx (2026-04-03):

# freETarget

Application Note: Precision Calibration

INTRODUCTION

Straight out of the box, the FreeETarget circuit operates with relatively low calibration with no extra work. For those users who demand the best in accuracy, the target can be calibrated to remove errors due to assembly or other defects. This document describes the calibration and the steps needed to do this on the target.

REQUIRED EQUIPMENT

Item | Description | Required
1 | Air Pistol Target | 2 required
2 | Suis target mask | 2 required
3 | Target Scan smartphone app
4 | Notepad or similar text editor
| Alternate if you do not have TargetScan
3A | Graph paper | 2 required
3B | Thumbtack | 1 required

THEORY OF OPERATION.

Aligning the paper needs to take care of the following sources of error

- Relative position of the paper to the sensors
- Angular orientation of the paper to the sensors
- Consistency in the location of the sensors

The calibration procedure takes care of these errors by comparing the calculated to the actual and applying a correction to each source of error.

An exaggerated sample of a paper target to the electronic target is shown in Figure 1. This shows a target with two holes (red) and two reported locations (black)

The four errors are:

- Static Position Error due to a misalignment between the paper and the sensors. This error will be consistent for each shot.
- Angular Position Error due to skew between the paper and sensors. This error will be consistent for each shot
- Radial Error, a difference between what the paper and the electronics support. This error may vary based on the position of the shot due to errors in locating the individual sensors
- Angular Position error, a difference between the location of the shot and it’s computed value. This error may be based on how the sound travels to the sensor.

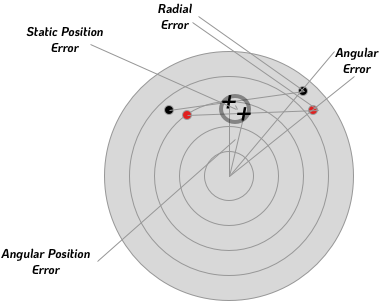
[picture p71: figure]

Figure 1. Target Error Sources

Static Position Error

The Static Position Error is eliminated by:

- Finding the geometric centre of the shots reported by the target
- Finding the geometric centre of the shots as recognized on the paper.
- Correcting for the difference between the two locations.

Static Angular Position Error

After shifting the shots to align the geometric centres of the actual to the paper shots, the Angular Position Error is eliminated by:

- Averaging the angular position of the actual target shots
- Averaging the angular position of the paper shots
- Adding the angular error to each new shot as it arrives.

Angular Error

The Angular Error occurs when there is a position error in the sensor that places the sensor out-of-round. This will skew the shots so that they appear uneven. The Angular Error is corrected by starting with a sample of (say) ten shots that can be compared between actual and target.

- Divide the circle of shots into arcs between the sample shots
- In each arc build a spline function that interpolates the angular difference between the two shots.
- As each shot arrives, determine which arc the new shots belongs to
- Determine the angular error and add it to the angular displacement of each new shot

Radial Error

The Radial Error occurs when the position error of the sensor is out of round and skews the shots so that they appear in an oval. Much the same as the Angular Error, the Radial Error is corrected by

- Divide the circle of shots into arcs between the sample shots.
- Correct each sample shot for the angular error calculated above
- For each arc, build a spline function that interpolates the ratio (scale factor) between the actual and target shots.
- As each new shot arrives, determine which arch the shots belongs to
- Multiply the computed radial displacement by the spline computed scaling factor

CALIBRATION PROCEDURE

The calibration procedure is done in the following steps:

- {“CAL”:1} -Prepare to calibrate the target
- Take twenty (20) sample shots
- {“CAL”:2} – Enter the reference data into the target

All of these steps can be carried out using the debug tab on the PC client.

Prepare the Calibration

Start by carefully locating the centre of the two paper target in the centre of two Suis mask.s as shown in Figure 1. It is important that this be done precisely since an error here will translate into the final calibration.

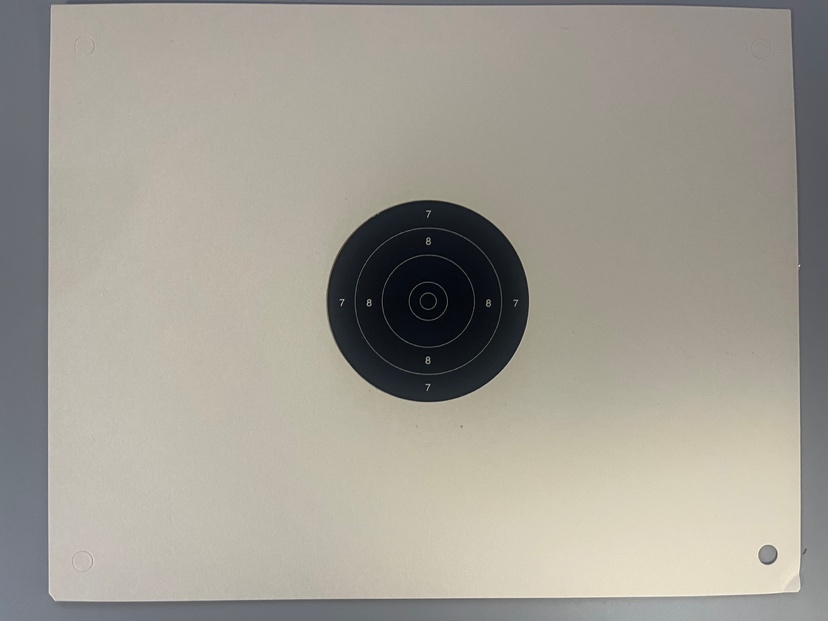
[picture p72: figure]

Figure 1: Target and Mask Assembly

On the PC with the Client

- Open the PC client
- Connect to the target
- Press the Debug tab to observe the target as you shoot
- Send the command {“CAL”:1} to the target. This removes the current calibration and prepares the software to accept the data.

Take Twenty Sample Shots

Take twenty sample shots. Ideally the shots need to land in a circle in the four ring. As shown in Figure 2, you want to spead the shots out across the target as much as possible.

DO NOT EXIT THE PC CLIENT UNTIL CALIBRATION IS COMPLETE, OTHERWISE THE SHOT DATA WILL BE LOST.

Importing the Target Reference Data

Using the upload icon at the bottom of the Target Scan Page (lower left square with an up arrow) email the Shots Data to yourself (Figure 2)

The shot data is a CSV file that can be observed using Excel or some other spread sheet. The target data is shown in Figure 3.

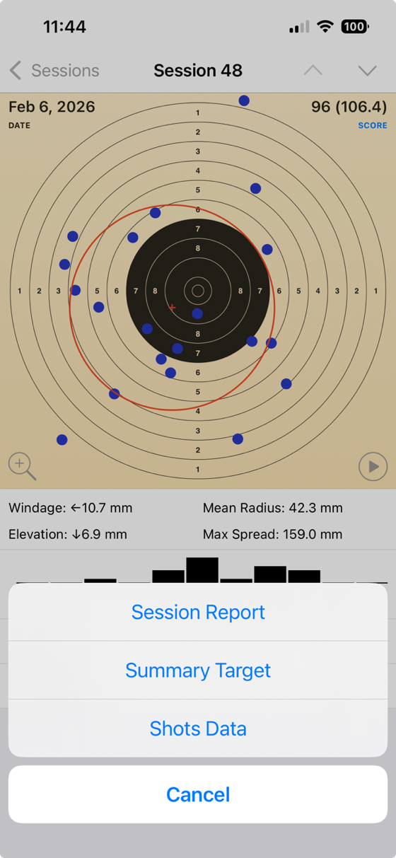
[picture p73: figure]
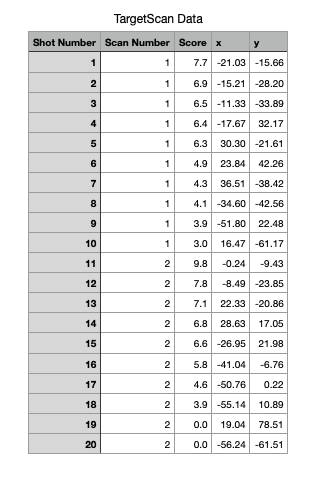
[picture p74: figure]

Figure 2: Sending Shots Data | Figure 3: Target Scan Data

Calibrate the Target

Send the command {“CAL”:2} to the target using the GENERIC COMMAND box in the debug tab

The target will prompt the user to select a calibration reference.

1 - TargetScan CSV file

2- Tabulated Data

Enter mode:

Enter 1 and press SEND if using a TargetScan file, or 2 is entering the data by hand.

Figure 4: Calibration Command Line

The target will match up the target scan data to the shot data and keep the ten shots furthest way from the 10 ring. It will then generate a series of calibration constants that will be used to adjust the shots.

At the end of the calibration, you will be prompted to save the settings. Clear the command box and enter Y then send.

The target is now calibrated.

Erasing the Calibration

If you make a mistake in the calibration, you can clear the calibration by sending the command {“CAL”:8}. You will be prompted to confirm that the calibration should be cleared.

APPENDIX 1

ALTERNATE CALIBRATION METHOD

If you do not have Target Scan, you can use an alternate calibration method using graph paper.

Using a thumbtack or pin, align the centre of the target to the centre line of the graph paper as shown in Figure A1

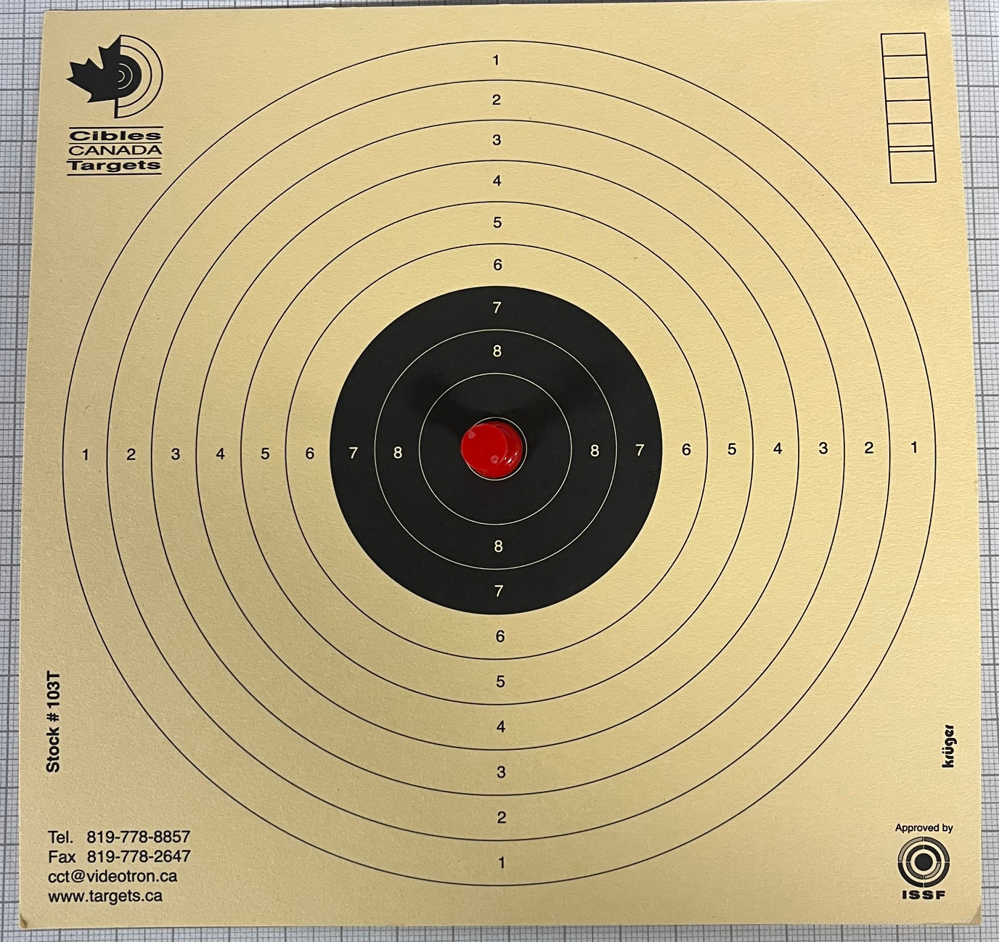
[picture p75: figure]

Figure A1. Graph Paper Alternative to Target. Scan

- Tape the target to the graph paper
- Attach the target and graph paper to the target as you would normally
- Shoot 10 shots into the target/graph paper
- Change to a second target/graph paper and repeat
- Carefully locate the centere of each pellet hole
- Write down the X-Y coordinates of each centrepoint
- Use these coordinates for the {“CAL”:2… } command

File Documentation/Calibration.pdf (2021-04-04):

FREETARGET

# Application Note: Setting the Trip Point

## SUMMARY

This application note describes the procedure for calibrating the trip point of the circuit.

## REQUIRED

- freETarget V2.1 or higher
- Firmware V3.0 or higher
- Small Screw Driver
- Header Jumper

## INTRODUCTION

freETarget uses the sound of the projectile passing the sensors to trip a circuit and measure the time difference between the various sensor. Using the time difference the software computes the location and displays the results.

Ideally the hardware wants to detect the pellet at the moment the signal starts to appear. In practice setting the trip point close to zero would make it susceptible to false triggering from other targets. Setting the trip point too high would prevent the circuit from detecting some shots. freeETarget has a variable control that lets you adjust the trip point based on your range and shooting preferences.

## PREPARATION

The circuit is put into calibration mode by inserting the CAL jumper as shown in Figure 1.

The trip ranges are selected by adding an additional jumper to the A or B header. The ranges are shown in Table 1.

Table 1: Jumper Settings

Low | Normal | High
Jumper A | None | Jumper B

Start by setting the calibration to the NORMAL mode. Use the HIGH setting for outdoor ranges with high calibre weapons. The low setting is provided for reference only.

## ADJUSTMENT

The trip point is adjustable in three ranges and 15 levels as shown in Table 2. Using the small screwdriver adjust the trim pot (Figure 2) and observe the LED indicators (Figure 3). The circuit is delivered calibrated to a trip point of roughly 600mV. Adjust upwards if you are getting false trips. Adjust downwards to improve the detection threshold.

Table 2: Trip Point Adjustment Low
(mV)

Normal
(mV)

High
| | | (mV) | RDY | X | Y
Do Not Use | 233 | 350 | 525
| 267 | 400 | 600
| 300 | 450 | 675 | | | BLINK
| 333 | 500 | 750
| 367 | 550 | 825 | | BLINK
Factory Setting | 400 | 600 | 900
| 433 | 650 | 975 | | BLINK | BLINK
| 467 | 700 | 1050
| 500 | 750 | 1125 | BLINK
| 533 | 800 | 1200
| 600 | 900 | 1350 | BLINK | | BLINK
| 667 | 1000 | 1500
| 733 | 1100 | 1650 | BLINK | BLINK
| 800 | 1200 | 1800
Do Not Use | 867 | 1300 | 1950 | BLINK | BLINK | BLINK

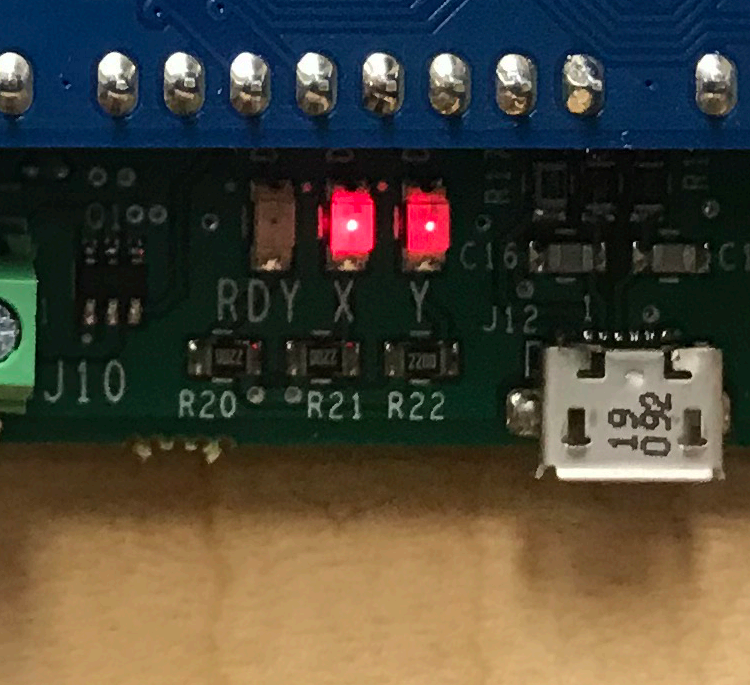
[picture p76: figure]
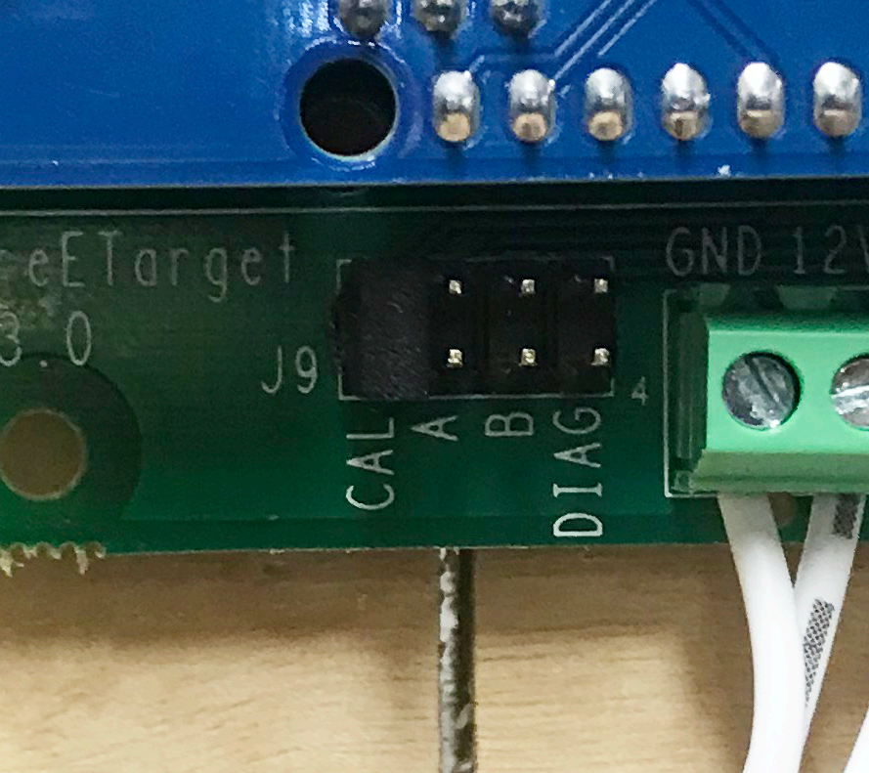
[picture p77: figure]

Figure 1: Calibration Jumper | Figure 2: Adjusting Potentiometer | Figure 3: Indicator LEDs

IMPORTANT

No LEDs or all blinking indicates under or over range and should not be used.

## FINISHING UP

- Record the LED settings and date
Date | S | X | Y | Reason for Change
- Remove the calibration and other jumpers
- Cycle power to the freETarget
- Verify that the LEDs return to the conventional RDY-OFF-OFF setting

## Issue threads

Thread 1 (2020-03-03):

The display part

modena01, 2020-03-03:
Hi Allan, what calculation output do you intend the Arduino to output? Just thinking about the display code, will the Arduino output X/Y coordinates (in mm?) or will it output raw timers values, or something else?

ten-point-nine, 2020-03-03:
The Arduino will read the counters, perform the calculations, and output the position as a JSON message

The display PC would have to make a pretty picture

Allan

Sent from my iPhone

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

ten-point-nine, 2020-03-03:
I figure an xy coordinate in mm would do nicely

That way pistol or rifle should work.

I’ll put together an ICD once I send the board out for fabrication

Allan

Sent from my iPhone

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

modena01, 2020-03-03:
Thanks, easy.

modena01, 2020-03-06:
will the Arduino be outputting to an IP network interface, or are you planing on serial or something else?

ten-point-nine, 2020-03-06:
I was thinking serial over usb.  But no reason not to be WiFi

Allan

Sent from my iPhone

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

modena01, 2020-03-06:
WiFi be best, yes.

TigraTT, 2020-08-12:
as far as i know this project should work for private ranges, but i think that some shooters want to have a cheap solution for ther club ranges.
I and some of my teammates for example want to build up 5 or 10 ranges for 50m and 100m .22 rifle shooting.
For this i thought about a 5 port gateway from serial to ethernet like Moxa or Advantech.
I can check such an solution here in my office because i´m working in the industrial IT and have these parts here for testing.
I will check this and give you an feedback.

AzmodanRO, 2020-08-12:
well, Allan would probably know better...
but as far as i know, we are limited on what the arduino board is capable.
and the current arduino only supports USB for direct connectivity. There might be solutions to extend the USB over longer distances via ethernet or wifi, but that would only be a bridge.

Closed 2021-01-31.

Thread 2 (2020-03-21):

Missing what the sensors are and so on, how can i contact the author to get more information?

ArnoBrinkman, 2020-03-21:

ten-point-nine, 2020-03-22:
Hi

Sorry with all the crisis going around your email fell down my list.

The sensors are four microphones in a circle.   Currently working on the microphones now.

Can you help with this?

Sent from my iPhone

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

ArnoBrinkman, 2020-03-22:
I couldn't find your mail address or other way to contact you then this.
My mail address is arno@abvisie.nl

ten-point-nine, 2020-03-22:
Thank you

I can be reached at allan.brown.atl@gmail.com

How did you find the github page?

Regards

Allan

Sent from my iPhone

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

clivegarnham, 2020-03-23:
Hi Allan,

Have you thought yet about what type of microphones to use? Do you have any idea what other target systems use? I would be willing to do some experimental and development work in this area if that would help.

I see from your documentation that your interest is making something for 10m air, and that seems a great place to start. I would be interested in extending the system to include smallbore distances, ie 25 yards/metres, 50 metres and even 100 yards. With different target hardware, I think the same basic system could be adapted to work at all these distances. For competition use, I'm not sure that the counter size and clock frequency are high enough, but that is something that can be looked at later.

Regards,

Clive Garnham

ArnoBrinkman, 2020-03-23:
I've send you a private mail

ten-point-nine, 2020-03-23:
I have not done much work in that area, so any help would be great.

The cable harness supplies 3.3 and 5.0 volts.  There are separate conductors for each microphone.

The circuit goes into a simple competitor that has an adjustable reference voltage.   I anticipate a trip voltage of about a volt would be ok.  Once started the software shuts down the circuit after 500us

I was thinking of an wideband microphone to capture the rising edge of the sound wave

Anything you could do would be great

Thanks

Allan

Sent from my iPhone

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

Closed 2021-08-14.

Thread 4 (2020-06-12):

How make to start de software on Windows

Rebelmuzick, 2020-06-12:
Hello friends, I am a member of the facebook group of 10.9, I was interested in putting together this electronic target, my question is how can I run the software with windows 7 or 10. What software do I need to run the program in C #
Thank you so much

AzmodanRO, 2020-06-12:
you need Visual Studio 2019 Community Edition  (it's free - download from
microsoft)

On Fri, Jun 12, 2020 at 6:37 PM Rebelmuzick <notifications@github.com>
wrote:

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

Rebelmuzick, 2020-06-12:
> necesitas Visual Studio 2019 Community Edition (es gratis - descarga desde microsoft)
> [...](#)

Thank you very much, surely when you have the microphones of the scheme and build the boards I will consult how they are mounted and then how to program the various sketches of the arduino since the times that I have done it I only programmed one sketch. ino at the same time. total thanks

Closed 2020-06-12.

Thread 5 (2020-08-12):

Changing PC Software to work an 25m Pistol and 50m rifle

TigraTT, 2020-08-12:
dear Azmodan,
i did not know if we are in contact before, but i´m in contact with Allann over messanger.
And i´m sorry, but i could not reach you ofer the Meisterschützen Forum or any other way, so i post my question here.

at first a big thank your for giving us this freeware, i think your project could be a very good solution for all shooters to get a cheap electronic target.

I chat with Allan for ordering two sets of electronic boards, but actual they have a longer delivery time. If i understand him right??

You have to know that my skills in programming are not so good, and C# is completely new for me. I am working in industrial automation and there i know several PLC systems and a little bit VB.net.

I have loaded the software and i could change for example the air pistol target to a 25m .22 Pistol target. (in Germany we use the same target for smallbore rifle at 100m)

Also i have changed the zoom so if i change between Pistol and rifle, the targets are both fullscreen.

My Problem is, if i make some shots (with the simulation) i get the right picture but the shot value is wrong. (On the 25m target!)

For example a shot in "Center" is right with 10.9, but a shot with -30 and 0 is a 7,2 instead of a 9,8?

I understand that the value is calculated for the 10m air pistol target, but i do not find this part in your program to change this calculation offset to my new target.

(30mm on the ar pistol arget seems to be a 7,2)

I think if you can add a 25m Pistol target and also a 50m rifle target this would bring a great boost for your free Target and you can sell many of the boards.

as i read in Facebook oder some shooters forums this question is coming up from different users?

I want to build up two completely working targets to show them in my club, to convince other shooters to invest in 8 more targets, because then we have all our 50m and 100m lines running electronic targets. If we want to buy them at Meyton, Sius, Seta or others, this will cost ust about 50.000€ and this is money we do not have.

Did you test for example with USB to Ethernet adapters to get a longer distance than 10m??

Kind regards, and thanks a lot for your free work!

Ralph

AzmodanRO, 2020-08-12:
hi
yeah..i don;t check the meisterschutzen forum very often :) here is better.
yes, you are correct, that the 25m and 50m requests are abundant. we are looking at this for sure, but first we would like to finalize the current setup (10m) since it;s easier to test (at home - for longer distances we need a shooting range).

please understand that the project is still in beta testing and the time frame for further features is still uncertain. Allan also has to perfect the fabrication process. he is doing it manually as of now.

but, in the interest of the current conversation, i would need exact specification of your 25m target. is it the free pistol target, used for 25m center fire precision stage also? since i only shoot 10 air pistol, i;m not too familiar with small bore targets/distances/disciplines

TigraTT, 2020-08-12:
hi, and thanks for your answer!
i do understand that this is a beta, and i know that time is the most expensive material in such projects.
At the moment me and my teammate (he is Carpenter) are working on a wooden target and the cabeling for about 100m.
This is not easy because 100m is a bit too long for RS-232, so i decide to work with serial to ethernet converter, or maybe to a RS232 to RS485 transmission. I will give you a feedback if it is working.
On my private Meyton frame i have a RS232 connection, but this is only 50m!

i have played around a little bit and i found these settings in your code:
**public const float pistol1X = 5.6f; //oficial scoring dimentions
public const float pistol1Y = 10.3f;
public const float pistol2X = 4f;
public const float pistol2Y = 10.5f;**

if i change the 5.6 for example to 10 the value of the shot is calculated better but not right.
But if i change this, a 10.9 is not longer a 10,9, so i wonder where i have to change more??

here is the code for the 25m target (or in your words the Free Pistol 50m target):
public const decimal outterRingPistol = 500m; //mm
public const decimal ring2Pistol = 450m; //mm
public const decimal ring3Pistol = 400m; //mm
public const decimal ring4Pistol = 350m; //mm
public const decimal ring5Pistol = 300m; //mm
public const decimal ring6Pistol = 250m; //mm
public const decimal ring7Pistol = 200m; //mm
public const decimal ring8Pistol = 150m; //mm
public const decimal ring9Pistol = 100m; //mm
public const decimal ring10Pistol = 50m; //mm
public const decimal innerRingPistol = 25m; //mm

public const decimal innerTenRadiusPistol = 25m;

the air pistol target has ring wide of 8mm and the 25m target has ring wide of 25mm, and the pellet caliber is different from 4.5mm air pistol to 5.6mm Free Pistol.

did you have any informations when the boards will be deliverable or is this Allans part?

Kind regards, Ralph

AzmodanRO, 2020-08-12:
as i wrote in the a code comment, i use linear interpolation using the calculations from here: http://targettalk.org/viewtopic.php?p=100591#p100591
i have no idea how he calculated those values (decimal score versus shot radius ), but they work. if i can find the formula, i will implemented in the code so no to have hardcoded values

TigraTT, 2020-08-12:
i have found it and changed your code to his values and it seems to be working!
 **public const float pistol1X = 16.35f; //5.6f; //oficial scoring dimentions
        public const float pistol1Y = 10.4f;  //10.3f;
        public const float pistol2X = 13.85f;  //4f;
        public const float pistol2Y = 10.5f;**

i will continue with testing and i hope that i can get two sets of boards in the near future.

AzmodanRO, 2020-08-12:
cool
i am also waiting to get a sets of boards :)
after we are happy with the current setup, i will refactor the code to include more targets

TigraTT, 2020-08-12:
these are very good news!
if you need help, for testing on ranges up to 100m, please contact me.
i also will try to improve my skills in C#, maybe i can make some easy changes, such as translation for example.
I have even made the translations for the Trace! shooting software.

ten-point-nine, 2020-08-12:
Just joining at the end

I added a calibration message to my Arduino code.

How big is a 100 meter target 1 ring?

Allan

Sent from my iPhone

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

ten-point-nine, 2020-08-12:
I modified the Arduino code so that you can calibrate it for a larger target.

The JSON message {"DIA":new size} **to** the Arduino will adjust the algorithm for the new sensor location.

The sensors must be placed at least 1.4x the diameter apart.

Right now I seem to have a problem with shots that are close to one sensor and far away from the other (ex 3 ring at 12'oclock)  I think if I boost up the microphone sensitivity I should be OK.

As Azmodan  said earlier, right now time is the most expensive commodity, and with the summer and COVID, things are not moving as fast as I would hope.

TigraTT, 2020-08-12:
Hi together,
i have send the code with the target size in my second post, but here is a picture. (only in german, but i think it is the international pistol precision or free pistol 50m target.
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
TigraTT, 2020-09-09:
now at least here is my latest code and a screenshot:
//draw shot on target
            int count = getShotList().Count;
            Color c = Color.FromArgb(200, 190, 190, 190); //semitransparent shots
            Pen p = new Pen(Color.LightSkyBlue);
            Brush bText = new SolidBrush(Color.Black);
            if (l == count - 1)
            {
                if (shot.decimalScore > 9.9m)
                {
                    c = Color.Red;
                }
                else if (shot.decimalScore > 8.9m && shot.decimalScore < 10.0m)
                {
                    c = Color.Yellow;
                }
                else if (shot.decimalScore < 9.0m)
                {
                    c = Color.LightSkyBlue;
                }

                p = new Pen(Color.Blue);

                if (shot.decimalScore > 10.2m)
                {
                    bText = new SolidBrush(Color.Yellow);
                }
                else
                    bText = new SolidBrush(Color.Black);
            }

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

ten-point-nine, 2020-09-09:
I would like to add a feature to the UI

Download a firmware image from the PC to the Arduino.

Needs

A dialog box to locate the Arduino file
Open a serial port at 38,800
Send some control bytes to the Arduino
Send the contents if the file to the Arduino
Close the connection
Close the file

If I get the details of the flow can one of you code it?

Allan

Sent from my iPhone

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

TigraTT, 2020-09-09:
Allan, sorry but thats too much for my poor skills in C#
I´m very happy that i could change the things i have made so far, and mostly happy that they are working!

AzmodanRO, 2020-09-09:
of course i can code it

AzmodanRO, 2020-09-09:
pushed the shot color customization to git

TigraTT, 2020-09-09:
i found that you have changed the fontcolour for all 10ring shots, i only have made Yellow for "Inner Tens", means over 10.2

AzmodanRO, 2020-09-09:
inner ten means different decimal score depending on the target. for pistol it;s above 10.4

TigraTT, 2020-09-09:
OK, thas right.

TigraTT, 2020-09-09:
with the latest download i get an SQL Lite error when debugging??
Sorry, but i did not know how to continue

AzmodanRO, 2020-09-09:
what error?

TigraTT, 2020-09-09:
this is the error:
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

AzmodanRO, 2020-09-09:
yes. i added that check to make sure the journal database is accessible.
if you are running the program from visual studio, u need to install the "System.Data.SQLite" package using NuGet

TigraTT, 2020-09-09:
OK i found it!
Nice work with the settings page for custom colours!
Now there should be only one more color for "Inner Tens" text colour and maybe for the fontsize?

AzmodanRO, 2020-09-09:
i intend to refactor a lot of the "target" setup in order to support all target sizes. in there will be the place to setup more stuff like font size and the like

TigraTT, 2020-09-09:
you are my hero!
i think this project will grow and make many shooters happy with a cheap and simple electronic target for practice and training.

I have so many ideas to implement in such a training system, for example to work online with a Scatt or Trace! sensor, building time axles for analysing the shot rythm and so on.

A next step for evolution could be a LED lightning frame that could be controlled in brightnes and light colour by the user interface?
I have build a light frame for my training at home with a Trace! sensor, but the brightness is only adjustable by a poti.
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

ten-point-nine, 2020-09-09:
There was a delay in getting production going so I took the opportunity to add an accessory connector to the board.

It provides power and ground and 4 logic/communication signals.  The intention is to drive a paper roll or change from USB to something like RS-488

It would be easy to have a light driver to illuminate the target.

Allan

Sent from my iPhone

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

mjbedford, 2020-09-09:
On the topic of external connections, will the Arduino shield allow for stacking shields?

I’d like to explore using a messaging protocol over ethernet or wifi, and would like to into face with a DIP switch or similar to set an identity for each target so each lane can be identified individually output captured mentally for competition scoring etc…

Martyn

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

ten-point-nine, 2020-09-09:
At the present there is no plan to stack shields.

There is a jumper heading on the board that could be used as a lane selector.  There is also provision to download an electronic DIP switch setting via JSON but currently there is no software that uses it

The accessory connector can be used to drive an external Ethernet or WiFi link if the software was added

Allan

Sent from my iPhone

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

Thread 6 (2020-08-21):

How to build this project

mjbedford, 2020-08-21:
Sorry I am now a windows users so I am struggling to get this project open in VS and built.

I have cloned the repo and installed the Installer plugin for VS but I can see no way to open the project or build it.

Could someone point me to how to do this please it appears to be very different that the equivalent on a MAC (Visual Code)

Thanks

AzmodanRO, 2020-08-23:
- you need to use the windows version of visual studio. Allan is using a Mac as well, and he managed to run the windows visual studio with parallels.
- i'm sure that a cross platform platform would be better. one that runs on all devices (PC, Mac, Linux, Android, iOS, etc). if anyone wants to develop it, he;s welcome. this is an open source project. anyone can contribute.
- the system does use messages (JSON). these messages are now transmitted via USB serial port. they could be transmitted via tcp/ip using wifi or ethernet, if the hardware would allow. it does not (in the current iteration. maybe in the future)
- i cannot say what errors you encounter. please post a screenshot and error stack-trace in order to debug the program.

mjbedford, 2020-08-25:
I have installed the released package from free-e-target.com and I get a very similar exception

Log Name:      Application
Source:        .NET Runtime
Date:          25/08/2020 08:36:43
Event ID:      1026
Task Category: None
Level:         Error
Keywords:      Classic
User:          N/A
Computer:      JCW_Laptop_2013
Description:
Application: freETarget.exe
Framework Version: v4.0.30319
Description: The process was terminated due to an unhandled exception.
Exception Info: System.NullReferenceException
   at freETarget.frmMainWindow.drawTarget()
   at freETarget.frmMainWindow.targetRefresh()
   at freETarget.frmMainWindow.frmMainWindow_Resize(System.Object, System.EventArgs)
   at System.Windows.Forms.Control.OnResize(System.EventArgs)
   at System.Windows.Forms.Form.OnResize(System.EventArgs)
   at System.Windows.Forms.Control.OnSizeChanged(System.EventArgs)
   at System.Windows.Forms.Control.UpdateBounds(Int32, Int32, Int32, Int32, Int32, Int32)
   at System.Windows.Forms.Control.UpdateBounds(Int32, Int32, Int32, Int32)
   at System.Windows.Forms.Control.SetBoundsCore(Int32, Int32, Int32, Int32, System.Windows.Forms.BoundsSpecified)
   at System.Windows.Forms.Form.SetBoundsCore(Int32, Int32, Int32, Int32, System.Windows.Forms.BoundsSpecified)
   at System.Windows.Forms.Control.ScaleControl(System.Drawing.SizeF, System.Windows.Forms.BoundsSpecified)
   at System.Windows.Forms.ScrollableControl.ScaleControl(System.Drawing.SizeF, System.Windows.Forms.BoundsSpecified)
   at System.Windows.Forms.Form.ScaleControl(System.Drawing.SizeF, System.Windows.Forms.BoundsSpecified)
   at System.Windows.Forms.Control.ScaleControl(System.Drawing.SizeF, System.Drawing.SizeF, System.Windows.Forms.Control)
   at System.Windows.Forms.ContainerControl.Scale(System.Drawing.SizeF, System.Drawing.SizeF, System.Windows.Forms.Control)
   at System.Windows.Forms.ContainerControl.PerformAutoScale(Boolean, Boolean)
   at System.Windows.Forms.ContainerControl.PerformNeededAutoScaleOnLayout()
   at System.Windows.Forms.ContainerControl.OnLayoutResuming(Boolean)
   at System.Windows.Forms.Control.ResumeLayout(Boolean)
   at freETarget.frmMainWindow.InitializeComponent()
   at freETarget.frmMainWindow..ctor()
   at freETarget.Program.Main()

Event Xml:
<Event xmlns="http://schemas.microsoft.com/win/2004/08/events/event">
  <System>
    <Provider Name=".NET Runtime" />
    <EventID Qualifiers="0">1026</EventID>
    <Level>2</Level>
    <Task>0</Task>
    <Keywords>0x80000000000000</Keywords>
    <TimeCreated SystemTime="2020-08-25T07:36:43.000000000Z" />
    <EventRecordID>3891</EventRecordID>
    <Channel>Application</Channel>
    <Computer>JCW_Laptop_2013</Computer>
    <Security />
  </System>
  <EventData>
    <Data>Application: freETarget.exe
Framework Version: v4.0.30319
Description: The process was terminated due to an unhandled exception.
Exception Info: System.NullReferenceException
   at freETarget.frmMainWindow.drawTarget()
   at freETarget.frmMainWindow.targetRefresh()
   at freETarget.frmMainWindow.frmMainWindow_Resize(System.Object, System.EventArgs)
   at System.Windows.Forms.Control.OnResize(System.EventArgs)
   at System.Windows.Forms.Form.OnResize(System.EventArgs)
   at System.Windows.Forms.Control.OnSizeChanged(System.EventArgs)
   at System.Windows.Forms.Control.UpdateBounds(Int32, Int32, Int32, Int32, Int32, Int32)
   at System.Windows.Forms.Control.UpdateBounds(Int32, Int32, Int32, Int32)
   at System.Windows.Forms.Control.SetBoundsCore(Int32, Int32, Int32, Int32, System.Windows.Forms.BoundsSpecified)
   at System.Windows.Forms.Form.SetBoundsCore(Int32, Int32, Int32, Int32, System.Windows.Forms.BoundsSpecified)
   at System.Windows.Forms.Control.ScaleControl(System.Drawing.SizeF, System.Windows.Forms.BoundsSpecified)
   at System.Windows.Forms.ScrollableControl.ScaleControl(System.Drawing.SizeF, System.Windows.Forms.BoundsSpecified)
   at System.Windows.Forms.Form.ScaleControl(System.Drawing.SizeF, System.Windows.Forms.BoundsSpecified)
   at System.Windows.Forms.Control.ScaleControl(System.Drawing.SizeF, System.Drawing.SizeF, System.Windows.Forms.Control)
   at System.Windows.Forms.ContainerControl.Scale(System.Drawing.SizeF, System.Drawing.SizeF, System.Windows.Forms.Control)
   at System.Windows.Forms.ContainerControl.PerformAutoScale(Boolean, Boolean)
   at System.Windows.Forms.ContainerControl.PerformNeededAutoScaleOnLayout()
   at System.Windows.Forms.ContainerControl.OnLayoutResuming(Boolean)
   at System.Windows.Forms.Control.ResumeLayout(Boolean)
   at freETarget.frmMainWindow.InitializeComponent()
   at freETarget.frmMainWindow..ctor()
   at freETarget.Program.Main()

</Data>
  </EventData>
</Event>

I suspect this is the same exception I get in VS relating to the default target being null when it tries to draw the main window.

mjbedford, 2020-08-25:
Also, I appreciate your comment about this being an open source project, in that light  please could you remove your copyright from all the code

AzmodanRO, 2020-08-25:
push a change to check on the event type on session creation.
however, i cannot figure out where the problem comes from. the only thing i can think of is that, being on mac, somehow the .exe.config file is not loaded/not written correctly.

.net executables have the app settings saved in a .exe.config file that usually sits right next to the exe file. in case that directory is not writable, the config file is written in the default user directory. maybe the macos refuses to do that.

TigraTT, 2020-08-28:
why do you want the copyrights to be removed? i´m new in open source projects, so i ask!
For me this is a private shooting range solution, am i wrong? (or did you want to sell it to any customers?)

as is see in your post, the copyrights should be you smalles problem??
maybe if i get some time in the next days i will test on my iMac and give a feedback.
On my W10/64Pro systems everything works fine and i could make all the changes i want.

mjbedford, 2020-08-28:
I think a copy right is a completely incompatible with almost all
recognised open source licensing.

By applying a copyright to code you are asserting your ownership of the
code therefore no one can reproduce or extend it without your consent.

Martyn Bedford
+44 (0)7796692467

On 28 Aug 2020, at 12:52, TigraTT <notifications@github.com> wrote:

why do you want the copyrights to be removed? i´m new in open source
projects, so i ask!
For me this is a private shooting range solution, am i wrong? (or did you
want to sell it to any customers?)

as is see in your post, the copyrights should be you smalles problem??
maybe if i get some time in the next days i will test on my iMac and give a
feedback.
On my W10/64Pro systems everything works fine and i could make all the
changes i want.
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
TigraTT, 2020-08-28:
OK; understand.
thank you

AHenricsson, 2020-08-28:
Hi,

That is not accurate. One automatically has copyright of any work one
creates no matter if one assert ones ownership or not. This project uses
the MIT license which grants anyone the right to reproduce or extend it.
The copyright notice does not change this, but instead helps users. In
fact it is only through using their copyright that an author can license
their work under an free and open source license. The copyright notice
at the top of the MIT license is important and should not be removed as
1. it makes authorship clear and 2. it helps people who redistribute
(possibly modified) versions give credit to the original author(s).

It is also not true that copyright is incompatible with open source
licensing. In fact many free and open source licenses start with a
copyright notice.

So please keep the license as it is now.

Kind Regards

Anders Henricsson

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

ten-point-nine, 2020-08-28:
Anders

Thank you for your thoughtful comment.

When I started this project the intention was that the project could be open to anybody who wanted to build their own electronic target.  Not being an expert on copyrights, it seemed like the MIT license achieved those goals with a minimum of interference,

I agree that if the copyright notice serves the dual purpose of recognizing the author's contribution while not preventing somebody else from using it, then the goals of the project are achieved.

I suppose I need to put a copyright notice on the Arduino code and the circuit drawings.  I will copy Azmodan's text into mine.

mjbedford, 2020-08-28:
In my experience the copyright if any is that of the open source project
not the individual

Martyn Bedford
+44 (0)7796692467

On 28 Aug 2020, at 14:11, AHenricsson <notifications@github.com> wrote:

Hi,

That is not accurate. One automatically has copyright of any work one
creates no matter if one assert ones ownership or not. This project uses
the MIT license which grants anyone the right to reproduce or extend it.
The copyright notice does not change this, but instead helps users. In
fact it is only through using their copyright that an author can license
their work under an free and open source license. The copyright notice
at the top of the MIT license is important and should not be removed as
1. it makes authorship clear and 2. it helps people who redistribute
(possibly modified) versions give credit to the original author(s).

It is also not true that copyright is incompatible with open source
licensing. In fact many free and open source licenses start with a
copyright notice.

So please keep the license as it is now.

Kind Regards

Anders Henricsson

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
https://github.com/ten-point-nine/freETarget/issues/6#issuecomment-682483409
>,
> or unsubscribe
> <
https://github.com/notifications/unsubscribe-auth/AE3YGYTEB57ZNN6GY2WXMB3SC6LBNANCNFSM4QHNE6VQ
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
https://github.com/ten-point-nine/freETarget/issues/6#issuecomment-682497354>,

> or unsubscribe
> <
https://github.com/notifications/unsubscribe-auth/AISCRGZWDKYYEQE7DPCAGN3SC6PA5ANCNFSM4QHNE6VQ
>.
>

—
You are receiving this because you authored the thread.
Reply to this email directly, view it on GitHub
<https://github.com/ten-point-nine/freETarget/issues/6#issuecomment-682550266>,
or unsubscribe
<https://github.com/notifications/unsubscribe-auth/AE3YGYU6RXKM2UYK3D7KC3LSC6UJRANCNFSM4QHNE6VQ>
.

TigraTT, 2020-08-29:
i´m sorry, but i could not make the MAC OS test because my iMac is too old.
I only have MAC OS 10.11 and for that i only can use Visual Studio 2017, but on the microsoft website i only found VS 2019.

AzmodanRO, 2020-08-29:
VS2017 should be ok (2017 and 2019 are the almost the same release)

TigraTT, 2020-08-31:
i have canceled my iMac tests because it is a time thief, and for me Windows 10 is working.
I think my iMac is too old for running VS2017, because the installation does not complete, so i stopped these tests.
sorry Martyn, i could not help in this case.........

Closed 2021-01-31.

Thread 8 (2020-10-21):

Motor paper connect port

Rebelmuzick, 2020-10-21:
Hello everyone, I am Ismael Barone I a member of the 10.9 group on facebook, I am starting this wonderful project, check the J2 connection port on the targetboard is the paper output connector motor? If so, how does it connect?

ten-point-nine, 2020-10-21:
The accessory connector grounds one of the logic pins to signal a motor to turn.

I’ll update the documentation with instructions.

Allan

Sent from my iPhone

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

AzmodanRO, 2021-08-14:
rev3.0 has a dedicated port for the motor. documentation is on the website

Closed 2021-08-14.

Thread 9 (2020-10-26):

where are the latest board revisions?

normanrembarz, 2020-10-26:
Hi, where can i find the rev. 2.2 of the sensor pcb and the main pcb ?
Please add your version 2.2 to the repo.
Many THX

AzmodanRO, 2020-10-26:
https://free-e-target.com/contact/

ten-point-nine, 2020-10-27:
The current schematics are on the GIT hub.

Closed 2021-01-31.

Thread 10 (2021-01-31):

Website https://free-e-target.com/about/ has broken link to targettalk

danmoy, 2021-01-31:
Web page reads:

```
Join the conversation on TargetTalk.org. freETarget
```

It links to TargetTalk.org.or, which does not exist.  I don't know if the webpage's code is on this github or not, but the change is thus:

```
<a href="http://targettalk.org.or">TargetTalk.org</a>
```

Should instead be:

```
<a href="http://targettalk.org">TargetTalk.org</a>
```

danmoy, 2021-01-31:
Actually while we're at it, you should probably prefer to link to `https://targettalk.org`, since TargetTalk doesn't have automatic redirect to https set up.

AzmodanRO, 2021-01-31:
done. link fixed. now it points to the freetarget thread

Closed 2021-01-31.

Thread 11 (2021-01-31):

Sensor board dimensions and placing

mjbedford, 2021-01-31:
Continuing the thread on FB.

I am modelling a frame for the sensors to be attached to the back of a faceplate, and a gig to ensure it is exactly centred on the target holder, to get the distance exactly correct I would like to know if the 230mm distance is from the face of the sensor mount or the front of the microphone. If it is from the microphone could measure the height of the microphone and the PCB thickness. Thanks Martyn

AzmodanRO, 2021-01-31:
the distance from the microphones from face should be 230mm. the PCB plus microphone has 4mm in thickness, but i put some distancing washers (so that the soldered pins on the back of the PCB are not crushed). so the final "thickness" of the sensor is 6mm. that means that the sensor block should be 6mm away from the point where the microphone face will be.

i took that into consideration when i built my 3D model

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

AzmodanRO, 2021-01-31:
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

ten-point-nine, 2021-01-31:
Hello Martyn

The 230 mm is measured from the face of the microphone to the opposite face.

The 230 is the 160mm target dia x sqrt(2)

Allan

Sent from my iPhone

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

ten-point-nine, 2021-01-31:
Let me see if I can get the DXF of the board.

Version 3 sensor boards will be the same size.

Allan

Sent from my iPhone

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

ddraig576, 2021-01-31:
I was thinking a 3D printed mount for the modules to go in the corners of something similar to a SCATT LED light box (I'm looking at possibility of getting a cheaper model manufactured locally) would work well for 10m. Obviously for .22LR or high power air, the target face would need to be thicker steel to protect the components.

Doug

mjbedford, 2021-01-31:
Thats great Thanks, I have a parametric model so I can tweak the dimensions based on experiment easily enough without having to rebuild
I'll post a render when I have made a bit more progress

mjbedford, 2021-01-31:
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
A rough render, the top layer is a single print with the sensor mounts as one piece, I have also modelled a jig which fits in a 155mm hole in the front plate of your choice and aligns the sensor mounting frame to the back a bit of glue, screws or your preferred brand of duck tape and you should have the sensor in the right place and you can remove the jig.

I'll run a print off during the week to test for alignment and tolerances etc..

mjbedford, 2021-01-31:
P.S. its small enough to print on a domestic 3d printer and should cost no more than $2 to print the frame and the same for the jig

ten-point-nine, 2021-01-31:
Martyn

The hole in the middle needs to be square and the corners as close to the sensors as possible.

During test I found occasions where the circle could occlude the sound from reaching the sensor.

Allan

Sent from my iPhone

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

ten-point-nine, 2021-01-31:
How are you attaching the sensor to the printed plate?

Allan

Sent from my iPhone

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
>>> On Jan 31, 2021, at 11:49, Martyn Bedford <notifications@github.com> wrote:
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

ten-point-nine, 2021-01-31:
PS

Looks like you’re on the development team. I can bump you up to the top of the list.

I can send you a PayPal request if you like.

Allan

Sent from my iPhone

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
>>> On Jan 31, 2021, at 11:49, Martyn Bedford <notifications@github.com> wrote:
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

AzmodanRO, 2021-01-31:
the target face needs to look something like this:
-square hole (16x16 cm for air pistol)
-mounting blocks for the sensors at the corners of the hole (230 mm for air pistol)
-some way to put the paper target on the other side of the plate, with the position on the paper aligned the hole and the sensors (the center of the paper target needs to be at the center of the hole and at the intersection of the sensor diagonals)

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

ten-point-nine, 2021-01-31:
As to tolerances.

Moving one of the sensors by 1mm radially will move the centre pint by 1/2 mm.  It would have a gain effect over the span of the target.

Centered on the paper target is nice, but a bit like SCATT the gun is sighted in to what the target thinks is zero.  This gives a bit of tolerance to the overall construction.

I use regular paper targets because I am too cheap to buy the good ones

Alla

Sent from my iPhone

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

niggli, 2021-01-31:
I am also going to construct parts for 3D printing as soon as I have the hardware, but I would suggest not to integrate the front plate: 1) ist going to make the print very challenging to print due to the big flat surface and 2) it will not survive any impacts from diabolos. I was thinking about constructing a holder for the paper target and a jig for the sensors.

mjbedford, 2021-01-31:
Alan

Yes that you be great send me the PayPal link

Martyn Bedford
+44 (0)7796692467

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

AzmodanRO, 2021-01-31:
> I am also going to construct parts for 3D printing as soon as I have the hardware, but I would suggest not to integrate the front plate: 1) ist going to make the print very challenging to print due to the big flat surface and 2) it will not survive any impacts from diabolos. I was thinking about constructing a holder for the paper target and a jig for the sensors.

1) i agree
2) the face is mounted on rails behind a shield
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

of course the face plate could be smaller, but you need to link the paper holder and the sensor jig somehow, so they are aligned.

ten-point-nine, 2021-01-31:
I was thinking the same.  A small frame that holds the sensors onto a stronger plate.

Allan

Sent from my iPhone

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

mjbedford, 2021-01-31:
I can easily change the frame to a square

It’s already modelled to fit to the back of a front plate made of other
material

It will be easier to align if it’s a square

Martyn Bedford
+44 (0)7796692467

On 31 Jan 2021, at 19:53, Allan Brown <notifications@github.com> wrote:

I was thinking the same. A small frame that holds the sensors onto a
stronger plate.

Allan

Sent from my iPhone

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
hardware, but I would suggest not to integrate the front plate: 1) ist
going to make the print very challenging to print due to the big flat
surface and 2) it will not survive any impacts from diabolos. I was
thinking about constructing a holder for the paper target and a jig for the
sensors.
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

—
You are receiving this because you authored the thread.
Reply to this email directly, view it on GitHub
<https://github.com/ten-point-nine/freETarget/issues/11#issuecomment-770440241>,
or unsubscribe
<https://github.com/notifications/unsubscribe-auth/AE3YGYRKCGYJUK4ORBWRY2LS4WYLDANCNFSM4W3J3QJA>
.

ddraig576, 2021-01-31:
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
I was considering 4 corner mounts with a suitable sized template to get them equally distant similar to image, but if I read the earlier post right, does the centre need to be a set distance from the sensor? Or put it another way are the distances between sensors fixed?

I like the idea of using light boxes as they already exist, but could design something to match the requirements of the sensor layout.

ten-point-nine, 2021-01-31:
The critical dimensions are

Face to face sensor distance.
Perpendicularity
Orientation (45 degrees)

Face to face makes the target bigger
Perpendicularity skews the circle to an ellipse
Orientation rotates the results

There is an override in my software to adjust the sensor angle, but it is fixed to 45 degrees.

Assuming everything is square and true, Alex’s software lets you adjust the centre.

Allan

Sent from my iPhone

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

ten-point-nine, 2021-01-31:
Yes

The nose-to-nose distance is fixed by the 0 ring.  Root2 x 0 ring

There is a calibration in Alex’s software.

Allan

Sent from my iPhone

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
>>> On Jan 31, 2021, at 14:20, ddraig576 <notifications@github.com> wrote:
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

mjbedford, 2021-02-03:
could someone confirm the hole size in the sensor board and confirm that the replacing is still 3.80mm from the base of the sensor mount and 14.00 mm apart equidistant from the centre? I took these measurements from the PDF files in the cad.rar package. Thanks

ten-point-nine, 2021-02-03:
Martin

The hole numbers look good although if you can hold off for a few days.  My PCB guy wants to move the connector to the front of the board, make it right angle, and polarize it.

The speaker and mounting holes will remain i the same place.

He is ahead of schedule on the version 3 boards so I’d you want I’ll move you from the version 2 list to 3.   The new boards have light control and face strike detection.

Allan

Sent from my iPhone

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

mjbedford, 2021-02-03:
Allan, Thanks, that sounds great

LotusElan, 2021-05-23:
Looking for confirmation.  I just received the version 3 board and sensors.  I am seeing conflicting information regarding the layout of the target box.  I see where the sensor are located at 12, 3 ,6 ,& 9 O'clock  and also skewed 45 degrees from that.  The 45 degree arrangement seems to be the most current info.  Is that correct?
Also, I want to confirm the component stack from front to back.
|| = Wood or whatever.

**||**LED	Lights -------- Paper Target**||**Sensors ---------- Pellet Trap**||**

Is the distance from the microphone to the paper target important other than to avoid parallax?

Thanks
John

ten-point-nine, 2021-05-23:
Hi

Here is a link to the correct geometry.

sensor-geometry-1.pdf <https://allanbrownatl.files.wordpress.com/2021/04/sensor-geometry-1.pdf>

It shows the sensors 230 mm apart and rotated 45 degrees.

The 90 degree orientation was the first attempt and the sensors were too close.

Can you tell me where the 90 degree documentation is so I can delete it.  Thanks

Cover
LED lights
Sensor
Paper
Trap

I have about a 35 mm space between the front face and the target plane.

Allan

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

LotusElan, 2021-05-23:
Thank you.

I looked up and saw your reply and thought how did I miss that?  Then I realized it was your really fast  reply.

The picture a few post above and the last page of the **freETarget - Interface Control Document**.

LotusElan, 2021-05-24:
Allan,

Thank you.

It is on the last page of the freETarget - Interface Control Document

John

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

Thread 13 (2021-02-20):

Need help!

Muammer06, 2021-02-20:
hey allan, I am student at university and our team make some machine learning things about
shooting accuracy so we need record shootings like around 1000-1500. And I can just found your projects but I need help for setup. I can't understand to using which type of sensors and arduino coding. Also I am the new in coding like 3 months. if you help me thank you. I need this project in one month. thanks

AzmodanRO, 2021-02-20:
go to https://free-e-target.com/ to learn more about the project.

ten-point-nine, 2021-02-20:
Where are you located?

I have some detector boards I could send.

You would need for add your own processing boards.

Allan

Sent from my iPhone

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

Muammer06, 2021-02-21:
Hey, I am living in Ankara,Turkey. I am student at Hacettepe University and I am so glad about these boards. I have esp32 and arduino. Thank you again. Where we can talk my email is= muammert9@gmail.com

Closed 2021-08-14.

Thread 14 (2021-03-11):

error when debugging with latest software

TigraTT, 2021-03-11:
dear all,
i have received the boards and i get a working setup very fast.
Now i want to make some tests with the pc software by debug in visual studio, but if i do not have connected a arduino board there is always an error when trying to enter the settings page.
This error came up even when the Targetsimulator is running and the COM ports are connected crossover.
With an older version of the pc software everything works fine.
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

AzmodanRO, 2021-03-11:
committed fix to master branch

Closed 2021-03-11.

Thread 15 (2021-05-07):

MainBoard PCB

iliahz, 2021-05-07:
I have the opportunity and really want to implement this project.
Please add the missing files in freETarget/KiCad/Main Board/:
Electronic Target-pcb
Electronic Target_net
From my side, I can adapt this project for use on SMT Nucleo Board with greater performance(https://www.st.com/en/evaluation-tools/stm32-nucleo-boards.html)
BRG

ten-point-nine, 2021-05-07:
Unfortunately you will need to manually enter the schematic for your particular board and do a layout to generate the appropriate Gerber files.

iliahz, 2021-05-07:
SMT Nucleo=Arduino
Can you provide these missing files?
Unfortunately, I don't have a lot of development experience. I'll just spend a lot of time learning and designing.
Experience: with Arduino about 10  working projects  in production +C# developer.
my project: https://www.youtube.com/watch?v=y7md_O7nt5M
my dream: electronic scoring systems + shooter training systems in one system.

ten-point-nine, 2021-05-07:
The version 3 schematics are on git hub.  You will need to generate gerbers if you need them.

Otherwise I can sell you circuit boards and you fly wire them to the NXP board

Allan

Sent from my iPhone

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

Stefano-61, 2021-08-23:
Hello everyone, I introduce myself, I'm Stefano and I live in Italy near Treviso. I am a service technician. I travel for work also abroad. I am a fan of electronics and automation. As a hobby I like to shoot with the 10 m compressed air rifle. and 22 gauge rifle at 50 mt.
I found this project fantastic. I personally use EasyEDA for my PCBs. Now I try to create a PCB for the motherboard. I hope it will be of interest.
Good job everyone

Closed 2021-08-14.

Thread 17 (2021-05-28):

Doubt other type of plates

andressasousa, 2021-05-28:
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

Is it possible to use an Arduino Uno R3 SMD, a microcontroller board based on ATmega328, a Shield sensor Arduino 9 DOF? or in place of the Arduino 9 DOF Shield use a Ky038 Sound Sensor Module Arduino Microphone Sound Detector ?

andressasousa, 2021-05-28:
Is it possible to use an Arduino Uno R3 SMD, an ATmega328 based microcontrolled board, an Arduino 9 DOF Shield sensor? or, in place of the Arduino 9 DOF Shield, use a Ky038 sound sensor module, Arduino microphone, sound detector?

ten-point-nine, 2021-05-28:
Unfortunately no.

The Arduino typically samples around 40kHz for all channels.  This means that the four microphones would sample at 10kHz each.

The freETarget samples at 8MHz per channel or 32MHz overall.  This is needed so as to resolve the position to well under 1mm which is what is needed for ISSF rules.

The freETarget board also supports the power supplies so that the pellet sound is picked up correctly.  The board also supplied the light and motor controls.

Allan

Sent from my iPhone

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

andressasousa, 2021-05-28:
Could you enter the name of the sensors used and the Arduino?

So that I can check if you are in my country.

ten-point-nine, 2021-05-28:
All of the information you need should be on GitHub already.

Look under the kicad folder

Allan

Sent from my iPhone

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

ten-point-nine, 2021-05-28:
A complete hardware set is available from me for $200+$25 shipping

Allan

Sent from my iPhone

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

Closed 2021-08-14.

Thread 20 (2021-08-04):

PC Software upload failure

Moriniman, 2021-08-04:
I have a continual error msg when attempting to upload the Setup.exe for freETarget.
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

AzmodanRO, 2021-08-05:
looks like microsoft changed something to the redistributable file since publication.
best workaround is to manually download and install .NET Framework 4.7.2 - that way the setup will no longer try to download the prerequisite

https://support.microsoft.com/en-us/topic/microsoft-net-framework-4-7-2-offline-installer-for-windows-05a72734-2127-a15d-50cf-daf56d5faec2

Azmo

Closed 2021-08-14.

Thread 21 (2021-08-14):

Error starting Software

RcamiruagaJ, 2021-08-14:
I am trying to run last version (soft and firm) in Windows 10 but 32 bits, and give error of database (problem with SQLite).
In spite off the soft run but I can not save the session.
I will appreciate help to solve this. Thank you for comments.
[Doc1.docx](https://github.com/ten-point-nine/freETarget/files/6986505/Doc1.docx)

AzmodanRO, 2021-08-14:
there is a file in the installation folder . subfolder "log". name "freETarget.<date>.log
can you attach here the most current file (for the date when you encountered this problem)

thank you

RcamiruagaJ, 2021-08-14:
The subfolder "log" is not created

AzmodanRO, 2021-08-14:
can you send a screenshot of the installation folder? where the freetarget.exe is located

thanx

AzmodanRO, 2021-08-14:
also, after you click OK in the "database problem" error window, click in the textbox that is barely visible between the target and the timer (there you can see the word "Log").
then press Ctrl-A, then press Ctrl-C, and then go to the github page (here) and press Ctrl-V to paste the content of that textbox. and send it

thanx

RcamiruagaJ, 2021-08-14:
OK here attached in v
[freETarget data files.docx](https://github.com/ten-point-nine/freETarget/files/6986622/freETarget.data.files.docx)
ersion 2 and in version 1.16 with the corresponding behaviour and logs

RcamiruagaJ, 2021-08-14:
Thank you so much for your support

AzmodanRO, 2021-08-14:
you have some write permission problems. i think your account is too restricted and the program cannot write to the installation folder or the database folder. i don;t know how you managed that :)

you need to execute the program as administrator.
right-click on the freetarget icon, and from the context menu choose "Run as administrator".  and enter the administrator password if promted.

RcamiruagaJ, 2021-08-14:
Dear Sir,

Finally I run the software in a PC of 64 bits, I can not run in 32 bits.

After some tests I have noted that impacts in target are not the same that show in the display (software), I assume that is a calibration problem.

I have tested with "setting trigger point" document, all possible combinations... no good result.

And also I have tested setting the sensor positions (by software)...no good result.

My building is exactly to 230 mm and 165 mm between sensors.

I would be very appeciated if you can help me  on this subject.

Ramón

ten-point-nine, 2021-08-15:
What is the trip point set to?

Please send photos of target and display.

The sensors are 230 mm apart?

Allan

Sent from my iPhone

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

ten-point-nine, 2021-08-15:
What affects the accuracy is

Sensors in the correct location

Sensors 230 mm apart on the a diagonal

Trip point set to 1.25 volts

Paper close to the sensors

Remove face sensor

Shoot five shots into a clean target and post the pc and target pictures.

Thanks

Allan

Sent from my iPhone

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
>>> On Aug 14, 2021, at 18:03, RcamiruagaJ ***@***.***> wrote:
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

Closed 2022-01-11.

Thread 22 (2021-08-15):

Wifi communication between target and PC

mjbedford, 2021-08-15:
I am working on a bridge between. TCP and serial COM as  a short term solution to using the WiFI accessory without changes to the PC Software which I believe will be significant.

In the long run, I would like to suggest a switch to message-based communication, this would remove a lot of the complexities of handling byte streams.  At the same time, I think it would be good to add support for connection to an external WiFi AP so that multiple targets can share the same network, again this would simplify the setup and make it possible to easily support extra UIs for scoreboards, central data loggers etc...

There are a number of very easy to use message libraries for Arduino and C# that make it easier to send and receive data over TCP.

I know this is a large change but I think. it will make the system much more open to extension.

This is my speciality having worked in message-based integration for the best part of thirty years so I am happy to take on the bulk of the work.

Would it be ok to create a branch to use to work on this in the long run?

AzmodanRO, 2021-08-15:
this is an open source project. you can create a fork of the entire project and modify as much as you want

ten-point-nine, 2021-08-15:
What’s the difference between a fork and a branch?

Sent from my iPhone

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

AzmodanRO, 2021-08-15:
A repository code branch, like a branch of a tree, remains part of the
original repository. The code that is branched (main trunk) and the branch
know and rely on each other. Like a tree trunk's branch, a code branch
knows about the trunk (original code base) it originated from.

Branches are best used: when they are created as temporary places to work
through a feature, with the intent to merge the branch with the origin.

Unlike a branch, a fork is independent from the original repository. If the
original repository is deleted, the fork remains. If you fork a repository,
you get that repository and all of its branches.

Forks are best used: when the intent of the ‘split’ is to create a
logically independent project, which may never reunite with its parent.

On Sun, Aug 15, 2021 at 5:49 PM Allan Brown ***@***.***>
wrote:

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

Closed 2022-01-11.

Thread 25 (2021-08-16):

Missing PCB design

RespawnDespair, 2021-08-16:
Hi,

in issue #15 it is also mentioned, but for a different reason.
I recently discovered this great project, absolutely terrific work!

I have a lot of experience with Open Source projects, so i always run a sanity check whenever i want to dive into something new.
With this project that leads me to some issues:

- No true BOM for the electronic components. One can reverse engineer the schematics, but no shipping list is provided
- No PCB design for the main board

The issues above prevent newcomers from making a quick assesment of the project. I have no qualms about people ordering boards, but in a true Open Source project all files should be available.

With that being said, I would like to volunteer my time to help get the documentation in order. I was/am heavily involved in the Open.HD project where i mostly did project management and documentation. [Open.Hd](https://github.com/OpenHD/Open.HD) [Docs](https://openhd.gitbook.io/open-hd/)

I would love to start the build of this system myself and document the steps and necessary components.

My day-time profession is Developer and i have lots of experience with C# and Arduino, so no issues there.

Is any additional help appreciated and if so, where would my efforts be most needed?

ten-point-nine, 2021-08-16:
If you can create a BOM and gerbers they can be added to github.

Sent from my iPhone

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

ten-point-nine, 2021-11-08:
The updated schematics are on the web site.

Sent from my iPhone

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

Gary-77, 2021-11-08:
Thanks for it :)
I was speaking about the PCB design, will be great to have it such as 3d parts.

AussieMakerGeek, 2022-04-30:
@ten-point-nine  Such a shame that you gatekeep the PCB design for such a great project.

While I understand that you have put considerable time effort into the code and the project, if you make it so that people without technical knowledge of PCB layouts and high level electronics knowledge have no chance of making it without buying your boards, it might as well be a commercial product.

Considering the project can not be used on a commercial range (as it's not certified) and targeting personal use (no pun intended), having this as an open source project is useless if it's only able to be actually built by people with considerable PCB layout skills without buying your boards. That's not really in the true spirit of open source.

Personally - I have the skills but I just can't be bothered spending weeks laying it all out, ordering PCB, getting it wrong, redesigning, etc, etc, to the extent, i can't be bothered with the project, as much as i'd love to make one.  If PCB design was available, i'd give it a go.

Why not sell DIY PCB kits at least?

ten-point-nine, 2022-04-30:
The schematics are on GitHub hub and people with the technical knowledge can make a pcb from it.

Sent from my iPhone

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

ten-point-nine, 2022-04-30:
This could be your opportunity to contribute

Sent from my iPhone

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
>>> On Apr 29, 2022, at 21:59, Drew ***@***.***> wrote:
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

AussieMakerGeek, 2022-05-10:
Ok, I'll take this on.  I'm still interested in porting it to the ESP32 but that is going to take a longer and still trying to get my head around the maths of it.

I've been going over the v3.1 schematic and I have a couple of questions:

Why the two negative voltage generators?  Looking at the spec of the devices, they do the same thing but one is SMD and the other is through hole but they appear to be in parallel in the schematic anyway.

Any specific reason to use the LM75 over say a DS18B20?  LM75 +/- 2.0 deg accuracy, the DS18B20 is +/- 0.5.

Were you going to publish the V3.1 schematic kicad files?

ten-point-nine, 2022-05-11:
Can we switch this to ***@***.*** ***@***.***>?

Depending on price and availability one of the two negative converters is used.

No reason not to switch the op amps.

The KiCad shematics appear to be up-to-date.

Allan

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

AussieMakerGeek, 2022-05-11:
Not sure what you mean by the first comment - Do you mean swap to email comms?

Perfect - Makes sense

The LM75 is the temp sensor, not the op amp

The KiCad Schematics (actual SCH files) for the mainboard are only v3.0, not v3.1. Only the PDF is 3.1. Not much point designing a board that's already outdated.

ten-point-nine, 2022-05-11:
I’ll check the drawings again.  The change from 3.0 to 3.1 was to bring the high pass filters onto the main board.  I don’t thing the filters are actually needed but I left them just-in-case

Allan

Sent from my iPhone

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

joemaya03, 2024-03-16:
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
I have made the PCB Design using the V3.1 Schematics, I have some queries regarding the KiCad Schematics.

ten-point-nine, 2024-03-16:
What questions?I see that there are component changesAllanSent from my iPhoneOn Mar 16, 2024, at 12:45, joemaya03 ***@***.***> wrote:
Screenshot.2024-03-16.231304.png (view on web)
Screenshot.2024-03-16.231154.png (view on web)
Screenshot.2024-03-16.231132.png (view on web)
I have made the PCB Design using the V3.1 Schematics, I have some queries regarding the KiCad Schematics.

—Reply to this email directly, view it on GitHub, or unsubscribe.You are receiving this because you were mentioned.Message ID: ***@***.***>

joemaya03, 2024-03-17:
> What questions?I see that there are component changesAllanSent from my iPhoneOn Mar 16, 2024, at 12:45, joemaya03 ***@***.***> wrote:  Screenshot.2024-03-16.231304.png (view on web) Screenshot.2024-03-16.231154.png (view on web) Screenshot.2024-03-16.231132.png (view on web) I have made the PCB Design using the V3.1 Schematics, I have some queries regarding the KiCad Schematics. —Reply to this email directly, view it on GitHub, or unsubscribe.You are receiving this because you were mentioned.Message ID: ***@***.***>

What is the function of PIN D9, D10, D11 and D12 of the Arduino Mega2560?
Why have you shorted PIN D23 and PIN A7 of the Arduino Mega2560?

Apart from the above questions, I have incorporated the RC Filters in the Main Board itself, can you please have a look ? if everything is in order I will add the gerbers on Github.
[Schematic.pdf](https://github.com/ten-point-nine/freETarget/files/14626569/Schematic.pdf)

ten-point-nine, 2024-03-18:
The spare lines come into the board in-case in they are needed.  They are not used in the software D9 to D12 is a header that allows for configurations to be entered into the software.A and B are used for the multifunction switchesAllanSent from my iPhoneOn Mar 17, 2024, at 02:42, joemaya03 ***@***.***> wrote:

What questions?I see that there are component changesAllanSent from my iPhoneOn Mar 16, 2024, at 12:45, joemaya03 @.> wrote:  Screenshot.2024-03-16.231304.png (view on web) Screenshot.2024-03-16.231154.png (view on web) Screenshot.2024-03-16.231132.png (view on web) I have made the PCB Design using the V3.1 Schematics, I have some queries regarding the KiCad Schematics. —Reply to this email directly, view it on GitHub, or unsubscribe.You are receiving this because you were mentioned.Message ID: @.>

What is the function of PIN D9, D10, D11 and D12 of the Arduino Mega2560?
Why have you shorted PIN D23 and PIN A7 of the Arduino Mega2560?
Apart from the above questions, I have incorporated the RC Filters in the Main Board itself, can you please have a look ? if everything is in order I will add the gerbers on Github.
Schematic.pdf

—Reply to this email directly, view it on GitHub, or unsubscribe.You are receiving this because you were mentioned.Message ID: ***@***.***>

AussieMakerGeek, 2024-03-18:
Why go to the effort of designing a PCB now when Allan is just about to release an [ESP32 version](https://github.com/ten-point-nine/freETarget/issues/30#issuecomment-1930430719)?

ten-point-nine, 2024-03-19:
Thanks for the work.It helps people in some clubs and countries obtain electronic targets at the lowest possible cost.AllanSent from my iPhoneOn Mar 18, 2024, at 17:31, Drew ***@***.***> wrote:
Why go to the effort of designing a PCB now when Allan is just about to release an ESP32 version?

—Reply to this email directly, view it on GitHub, or unsubscribe.You are receiving this because you were mentioned.Message ID: ***@***.***>

ten-point-nine, 2024-03-19:
8 pin debug headerCal 1A.   2B.   3Debug 4Sent from my iPhoneOn Mar 19, 2024, at 09:45, joemaya03 ***@***.***> wrote:
The PCB design took just 6 hours to complete. It was no trouble at all. I would like to contribute more, let me know if I can be of any assistance.
And can you tell me which pin is A, B, Diag and Cal ?

—Reply to this email directly, view it on GitHub, or unsubscribe.You are receiving this because you were mentioned.Message ID: ***@***.***>

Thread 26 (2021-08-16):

Arduino specification

mjbedford, 2021-08-16:
I just tried pushing the code to an Arduino Clone an Elegoo Mega, it starts up and reports the test cycle on the serial port, but the LED all go off at the end of the test cycle and the LEDs cycle on and off.
What make of Ardunio are you using?

ten-point-nine, 2021-08-16:
I’m using an unnamed Arduino

I think I’ve used the elego boards elsewhere
without issue.

Nothing on the serial port?

Blinking leds probably indicates that the sensor cable is unconnected.

Allan

Sent from my iPhone

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

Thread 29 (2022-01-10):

50m target not loading

thirdwheel1, 2022-01-10:
when I click the tab I get the error message - Unhandled exception has occurred.

and in the details it shows:
See the end of this message for details on invoking
just-in-time (JIT) debugging instead of this dialog box.

************** Exception Text **************
System.NullReferenceException: Object reference not set to an instance of an object.
   at freETarget.Session.createNewSession(Event eventType, String user)
   at freETarget.frmMainWindow.initNewSession()
   at freETarget.frmMainWindow.disconnect()
   at freETarget.frmMainWindow.frmMainWindow_FormClosing(Object sender, FormClosingEventArgs e)
   at System.Windows.Forms.Form.OnFormClosing(FormClosingEventArgs e)
   at System.Windows.Forms.Form.WmClose(Message& m)
   at System.Windows.Forms.Form.WndProc(Message& m)
   at System.Windows.Forms.Control.ControlNativeWindow.OnMessage(Message& m)
   at System.Windows.Forms.Control.ControlNativeWindow.WndProc(Message& m)
   at System.Windows.Forms.NativeWindow.Callback(IntPtr hWnd, Int32 msg, IntPtr wparam, IntPtr lparam)

************** Loaded Assemblies **************
mscorlib
    Assembly Version: 4.0.0.0
    Win32 Version: 4.8.4420.0 built by: NET48REL1LAST_C
    CodeBase: file:///C:/Windows/Microsoft.NET/Framework/v4.0.30319/mscorlib.dll
----------------------------------------
freETarget
    Assembly Version: 3.3.0.0
    Win32 Version: 3.3.0.0
    CodeBase: file:///C:/Program%20Files%20(x86)/freETarget/freETarget.exe
----------------------------------------
System.Windows.Forms
    Assembly Version: 4.0.0.0
    Win32 Version: 4.8.4400.0 built by: NET48REL1LAST_C
    CodeBase: file:///C:/WINDOWS/Microsoft.Net/assembly/GAC_MSIL/System.Windows.Forms/v4.0_4.0.0.0__b77a5c561934e089/System.Windows.Forms.dll
----------------------------------------
System
    Assembly Version: 4.0.0.0
    Win32 Version: 4.8.4360.0 built by: NET48REL1LAST_C
    CodeBase: file:///C:/WINDOWS/Microsoft.Net/assembly/GAC_MSIL/System/v4.0_4.0.0.0__b77a5c561934e089/System.dll
----------------------------------------
System.Drawing
    Assembly Version: 4.0.0.0
    Win32 Version: 4.8.4390.0 built by: NET48REL1LAST_C
    CodeBase: file:///C:/WINDOWS/Microsoft.Net/assembly/GAC_MSIL/System.Drawing/v4.0_4.0.0.0__b03f5f7f11d50a3a/System.Drawing.dll
----------------------------------------
System.Configuration
    Assembly Version: 4.0.0.0
    Win32 Version: 4.8.4190.0 built by: NET48REL1LAST_B
    CodeBase: file:///C:/WINDOWS/Microsoft.Net/assembly/GAC_MSIL/System.Configuration/v4.0_4.0.0.0__b03f5f7f11d50a3a/System.Configuration.dll
----------------------------------------
System.Core
    Assembly Version: 4.0.0.0
    Win32 Version: 4.8.4390.0 built by: NET48REL1LAST_C
    CodeBase: file:///C:/WINDOWS/Microsoft.Net/assembly/GAC_MSIL/System.Core/v4.0_4.0.0.0__b77a5c561934e089/System.Core.dll
----------------------------------------
System.Xml
    Assembly Version: 4.0.0.0
    Win32 Version: 4.8.4084.0 built by: NET48REL1
    CodeBase: file:///C:/WINDOWS/Microsoft.Net/assembly/GAC_MSIL/System.Xml/v4.0_4.0.0.0__b77a5c561934e089/System.Xml.dll
----------------------------------------
System.Windows.Forms.DataVisualization
    Assembly Version: 4.0.0.0
    Win32 Version: 4.8.4200.0
    CodeBase: file:///C:/WINDOWS/Microsoft.Net/assembly/GAC_MSIL/System.Windows.Forms.DataVisualization/v4.0_4.0.0.0__31bf3856ad364e35/System.Windows.Forms.DataVisualization.dll
----------------------------------------
System.Data.SQLite
    Assembly Version: 1.0.112.1
    Win32 Version: 1.0.112.1
    CodeBase: file:///C:/Program%20Files%20(x86)/freETarget/System.Data.SQLite.DLL
----------------------------------------
System.Data
    Assembly Version: 4.0.0.0
    Win32 Version: 4.8.4270.0 built by: NET48REL1LAST_C
    CodeBase: file:///C:/WINDOWS/Microsoft.Net/assembly/GAC_32/System.Data/v4.0_4.0.0.0__b77a5c561934e089/System.Data.dll
----------------------------------------
System.Transactions
    Assembly Version: 4.0.0.0
    Win32 Version: 4.8.4084.0 built by: NET48REL1
    CodeBase: file:///C:/WINDOWS/Microsoft.Net/assembly/GAC_32/System.Transactions/v4.0_4.0.0.0__b77a5c561934e089/System.Transactions.dll
----------------------------------------
System.EnterpriseServices
    Assembly Version: 4.0.0.0
    Win32 Version: 4.8.4084.0 built by: NET48REL1
    CodeBase: file:///C:/WINDOWS/Microsoft.Net/assembly/GAC_32/System.EnterpriseServices/v4.0_4.0.0.0__b03f5f7f11d50a3a/System.EnterpriseServices.dll
----------------------------------------
Accessibility
    Assembly Version: 4.0.0.0
    Win32 Version: 4.8.4084.0 built by: NET48REL1
    CodeBase: file:///C:/WINDOWS/Microsoft.Net/assembly/GAC_MSIL/Accessibility/v4.0_4.0.0.0__b03f5f7f11d50a3a/Accessibility.dll
----------------------------------------

************** JIT Debugging **************
To enable just-in-time (JIT) debugging, the .config file for this
application or computer (machine.config) must have the
jitDebugging value set in the system.windows.forms section.
The application must also be compiled with debugging
enabled.

For example:

<configuration>
    <system.windows.forms jitDebugging="true" />
</configuration>

When JIT debugging is enabled, any unhandled exception
will be sent to the JIT debugger registered on the computer
rather than be handled by this dialog box.

AzmodanRO, 2022-01-10:
hi
can you upload the log file as well?
it is located in the My Documents\freETarget\log\freETarget.<date>.log

thank you

thirdwheel1, 2022-01-10:
Thank you alex for your efforts, here is the log file, I just tried to load the 50m target again so hope this has captured it.

2022/01/10 17:05:11:824 | ------------------------------------------------------------------------

Starting freETarget - v3.3.0 ...
2022/01/10 17:05:12:105 | Template database version = 3   -   User database version = 3
2022/01/10 17:05:12:105 | User database at: C:\Users\third\Documents\freETarget\database
2022/01/10 17:05:12:386 | ### New Session 'Pistol Practice' started ###
2022/01/10 17:20:44:317 | ------------------------------------------------------------------------

Starting freETarget - v3.3.0 ...
2022/01/10 17:20:44:426 | Template database version = 3   -   User database version = 3
2022/01/10 17:20:44:442 | User database at: C:\Users\third\Documents\freETarget\database
2022/01/10 17:20:44:708 | ### New Session 'Pistol Practice' started ###
2022/01/10 17:21:13:494 | Error connecting: A connection attempt failed because the connected party did not properly respond after a period of time, or established connection failed because connected host has failed to respond 192.168.10.9:1090
2022/01/10 17:21:59:053 | ------------------------------------------------------------------------

Starting freETarget - v3.3.0 ...
2022/01/10 17:21:59:193 | Template database version = 3   -   User database version = 3
2022/01/10 17:21:59:193 | User database at: C:\Users\third\Documents\freETarget\database
2022/01/10 17:21:59:468 | ### New Session 'Pistol Practice' started ###
2022/01/10 17:22:02:617 | TCP channel open...
2022/01/10 17:22:03:367 | ****************
Connected to freETarget "3.04.8 September 23, 2021" on TCP = 192.168.10.9:1090
2022/01/10 17:22:03:401 | ### New Session 'Pistol Practice' started ###
2022/01/10 17:22:03:432 | freETarget "3.04.8 September 23, 2021"
2022/01/10 17:22:04:808 | {
"NAME":"1",
"ANGLE": 45,
"CALIBREx10": 45,
"DIP": 0,
"LED_BRIGHT": 99,
"MFS": 0,
"NAME_ID": 1,
"PAPER_ECO": 0,
"PAPER_TIME": 30,
"POWER_SAVE": 30,
"SEND_MISS": 0,
"SENSOR": 230.00,
"SN": 0,
"STEP_COUNT": 0,
"STEP_TIME": 0,
"TARGET_TYPE": 0,
"TEST": 0,
"Z_OFFSET": 8,
"NORTH_X": 0,
"NORTH_Y": 0,
"EAST_X": 0,
"EAST_Y": 0,
"SOUTH_X": 0,
"SOUTH_Y": 0,
"WEST_X": 0,
"WEST_Y": 0,
"IS_TRACE": 0,
"TEMPERATURE": 7.00,
"SPEED_SOUND": 0.34,
"V_REF": 1.09,
"TIMER_COUNT":5568,
"DIP_HEX": 0x0,
"WiFi": 1,
"VERSION": "3.04.8 September 23, 2021",
"BD_REV": 3.00
}
2022/01/10 17:25:28:065 | *********
Disconnected.
2022/01/10 18:18:19:567 | ------------------------------------------------------------------------
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
AzmodanRO, 2022-01-10:
no.. the error is not in the log. if the error happened yesterday, you can find yesterday's log file in that directory.
also, you can attach the file here, not copy paste the text within.

from the previous error, it looks like the error message appeared when you were trying to close the window... so that is a little weird.

can you describe (or remake) the steps with performed when adding the 50m rifle event?
what name did you give to the event?
is the 50m rifle event showing in the vertical events tab when you start the application?

thirdwheel1, 2022-01-10:
Thank you alex.
It happens every time I hit the 50m tab so did it for that file before I pasted it to you, the error message wants me to quit the programme so I do. I followed your great video on the software and followed what was suggested to do to create an event, chose the name from the options list that is why I know the target is in there somewhere.
Do you think I should just download the latest software again and over write it and try and set it all up again, it might just have it's knickers in a bit of a twist. Ta again!

AzmodanRO, 2022-01-10:
hm. ok.
can you take 2 screenshots and post the pictures here? one of the "active events" tab and one with the "events" tab with the 50m rifle event selected? without connecting to the target. you can use the <snipping tool> from windows

reinstalling the software will not help.

thirdwheel1, 2022-01-10:
Alex here they are, hope they are there !!!

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

AzmodanRO, 2022-01-11:
all settings look to be ok.
i cannot reproduce the error on my system (with target simulator or actually connected to the target via both usb and wifi/tcp).

the next step would be to delete (actually rename) the database. go to the _MyDocuments\freETarget\database_ directory and rename the **Storage.db** file to something else.
and than restart the app, add the 50m rifle event again, add it to the active events list, close the app, start the app, connect to the target and switch to the 50m rifle tab

thirdwheel1, 2022-01-11:
WOOOOOO HOOOOOOO you are a flaming genius - but you might know that already.
I'm not really deep down computer savvy but I get by at the surface level so your help was followed correctly and it works, I down loaded a db reader but was not needed DOH just changed name of the root file and all is good. I owe you lots of beer.
Thank you so much for your help.

AzmodanRO, 2022-01-11:
you're welcome

still not clear how you managed to screw the database up... :)

thirdwheel1, 2022-01-11:
Give me a computer and I can screw up anything!!!
One more question and then I will be out of your hair, I'm going to build a 50m target as well as the 10m but the target is slightly larger so I will need to move the sensors out a bit so they are behind the steel and plywood shield, in the software you can set the distance between sensors, so asking the obvious can I just change it to what I want and all is good?
George

AzmodanRO, 2022-01-11:
theoretically yes.
practically...i;ve tested with my target in changing the sensor diameter with 5mm increments, and did not see any variation in the results.
this is something the arduino code is handling. the PC software just sends that parameter to the target. i;ve talked to Allan about this, but he could not explain it. (and neither can i).

so i would encourage you to test, with airpistol. change the sensor diameter from 200 to 250 (in 10mm increments) and shoot a target (so with the normal paper roll and paper mask, but also a normal paper target in the back as control) and compare the results.

these are my results from 10 October:
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

Closed 2022-01-11.

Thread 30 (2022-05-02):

Port to ESP32?

AussieMakerGeek, 2022-05-02:
I've spent several hours going over the code and the circuit schematic and I'm wondering if there might be an advantage to moving to a newer/faster microcontroller.

Although I don't yet completely understand the project in the detail I'm sure you do, I can see that you are sampling the microphones at 32mhz and using the binary counters for the timing, and then reading it back back in to overcome the limitations of the clock speed and analog sampling rate of the Atmega chip. Did I understand that correctly?

I have done some initial testing using an ESP32 which runs at 240Mhz (vs 16Mhz of the Atmega) and some basic microphone modules (The ones that just have a comparator chip to give a binary output) just using interrupts and it is looking very promising. I can get repeatable timings for impact points (within the parameters of the testing environment/code i have made). The ESP32 is also Dual core so we can run timing functions separate from the main loop if needed.

Moving to this microcontroller would mean the large amount of pins needed to control the extra chips would not be needed and the accompanying circuit board would be much simpler to construct, reducing the overall cost to build one (and possibly not even needed). It's early days and obviously I am not experienced in all of the intricacies of this project that I am sure you are aware of so can you see any reason my logic is flawed and this would not work?

ESP32 is about half the price of the Atmega and outperforms it in every way other than raw I/O pins, has built in Wifi so no need for external ESP-01 module and also has Bluetooth which can be used as a virtual com port to PC instead of USB. With the addition of some very basic modules that are easily available (such as the temperature sensor and Stepper driver or fets), it could be a full functioning system but would require a massive rewrite of the code.  I am happy to chainsaw in some code to yours as a deeper POC that you could potentially offer as a branch, or I could fork it into a separate project. The problem with that would be that it would be hard to incorporate revision changes to your code back into mine.

What are your thoughts?

ten-point-nine, 2022-05-02:
Hello

You are fundamentally correct in your understanding.  I’ve looked at an ESP, but I’ve been busy making housings.

I would not use an interrupt for the timing.  The latency between the interrupt and it’s processing would not be deterministic, not to the level needed to accurately measure the time time interval between microphone pings.  My thought was to use the comparators and use them to gate the on-board counters.  I would also look at using two comparators on each signal and a total of eight counters.

At this moment in time, most of the software changes I am making are for controlling the operation of the target using the multifunction switches.  Today I added a switch sequence for setting the LED brightness.

Probably the best thing is for you to fork it into your own project.  Much of the I/O type things have been abstracted in gipo.ino, analog.ino, and nonvol.ino.  The rest are somewhat platform independent.

Allan

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

AussieMakerGeek, 2022-05-02:
> I would not use an interrupt for the timing. The latency between the interrupt and it’s processing would not be deterministic, not to the level needed to accurately measure the time time interval between microphone pings.

Although there is a latency, it would be consistent across all sensors and therefore eliminate the error.  It would only be if the interrupt routine had not completed before a second sensor was triggered that it would be an issue. i.e the middle of the target.  So far, i have not seen this issue in my tests but neither have i set them up in a precision way and have a repeatable mechanism to test it.

I can definitely see your point though, it does make sense to me now to have external components to remove the delay in an interrupt.  I'll do some calculations on the processing time it takes to run the interrupt (clock cycles for the commands) and determine the potential error in terms of distance.  I'm not 100% sure on how the ESP32/Arduino handles interrupt priority either. i.e if an interrupt happens in the middle of another interrupt, is it dismissed or queued.

Using ASM directly in the interrupt routines would also likely reduce the processing time

I'll let you know how I go.

AussieMakerGeek, 2022-05-02:
So, looking at the ASM code for the ISRs, it would take 0.1041 Microseconds to process my current (fat) ISR (25 commands at 240mhz, per microphone).  This equates to an error of around 0.0356022 mm in raw distance to the microphone.  So unless the shot was in the *perfect* center of the sensors, the ISRs would not collide, but even if they did, for our purposes, the resulting shot would still be a 10.9.  I would say the error within the tolerances of the construction of the project would be a magnitude more than any error from 4 ISRs.

On paper, the interrupts would unlikely cause enough error to be of any substantial consequence.

AussieMakerGeek, 2022-05-04:
Hi Allan,
Can you help me get my head around the maths in determining the impact point?  I've gone over the 'Theory of operation' and 'Sample calculations' as well as the code in the compute_hit files but I can't make sense of it.

Primarily I have been using the 'Theory of operation' document but there seems to be conflicting information.

The Spreadsheet and the code use:
`=ACOS((D19^2-E19^2-F19^2)/(-2*E19*F19))`
`s->angle_A = acos( (sq(ae) - sq(be) - sq(s->c))/(-2.0d * be * s->c));`

But the example in the document uses:
`P = arcos( e2 - K2 / (2(s+e)K)) `

On top of that, in the triangulation diagram it shows the lengths of the sides of the triangle expressed as K, s+ e, e - Would it not be K, s-e,e?

ten-point-nine, 2022-05-04:
The theory of operation is simplified and should only be used for guidance.

The code is correct since it uses the rotated sensors

Allan

Sent from my iPhone

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

ten-point-nine, 2022-05-05:
It’s been three years since I looked at that document so I don’t remember much.

Looking back through the document there are some parts that need to be brought up to date, but the geometry portion is correct in principle.

In Figure 5 e is the thing we are trying to solve for, and is common to all sensors. The time from the pellet to the sensor is the value read from the sensor PLUS the unknown value e.  The unknown e is solved iteratively.

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

ten-point-nine, 2022-05-05:
The Github has been revised.

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

AussieMakerGeek, 2022-05-05:
Thanks for that, i'm still a bit confused but at least it makes more sense and I should be able to nut it out.

At the moment, I'm just trying to generate a working test that can reliably sense the location with a decent level of accuracy and give an xy coordinate as a more in depth POC.

From there, I can probably generate some custom functions to swap into the bulk of your code but it's going to be a far from trivial task since a lot of how your code is very specific to your timing method and the Arduino Mega.

I appreciate your help.
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
pawelros, 2024-01-17:
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

Sounds like you did a decent research. Damn, eliminating moving parts and a need to refill paper would be a killer!

ten-point-nine, 2024-01-17:
I tried just using the sound of the pellet passing the sensors but it’s just not loud and consistent enough.  AllanSent from my iPhoneOn Jan 17, 2024, at 03:20, Pawel Rosinski ***@***.***> wrote:

Hey @AussieMakerGeek did you manage to achieve some promising results? I am thinking about building a target without arduino and mobile device instead of a laptop.

No, I didn't. Not really for any specific reason other than losing interest in the project but I also struggled to get my head around the math involved for calculating the impact point. @ten-point-nine did provide some feedback but it wasn't enough for me to properly comprehend and move forward.
I had a test platform that worked extremely well and reliably to see the timings of the sounds but could not transform this into an x/y coordinate. Unfortunately, in the original code this is not just a simple function that can be exported.
I started looking into linear light based sensors pulled from computer scanners to simplify it, but this also ran into a bit of a dead end because I was unable to get enough technical data on the sensors. They seemed well suited, could support a suitable scanning frequency and are cheap. They worked but I could not get the expected results with lack of datasheets.

Sounds like you did a decent research. Damn, eliminating moving parts and a need to refill paper would be a killer!

—Reply to this email directly, view it on GitHub, or unsubscribe.You are receiving this because you were mentioned.Message ID: ***@***.***>

lboross, 2024-02-06:
@AussieMakerGeek  I recently came across this project and had the same idea as yourself.

I think I have the math/code figured out, but had issues getting reliable readings using the microphone modules I have.

I can contribute a function that will recursively calculate the X,Y based on time delay between sensors.

https://github.com/lboross/ESP_Target/blob/main/Arduino/ESP_Target/calculate.ino

If you are no longer interested in this project, I would appreciate if you could share how you got the timing working.

ten-point-nine, 2024-02-06:
Hello

Version 5 of the hardware to be announced in the next two weeks uses an ESP32 and developed for Visual Studio Code.

Version 5 has a number of new features

* Temperature and Humidity sensors
* Sampling rate increased to 10MHz per sensor
* Each sensor is sampled at two voltages and extrapolated back to the start of the signal.
* Onboard Multifunction Switches
* More LED colours and :LED status messages
* Better WiFi
* Possibility of BlueTooth interfaces
* Uses FreeRTOS to implement multiple threads across both cores.
* Digital control of the sensor trip points (no more potentiometer)
* Simpler motor connection

The current implementation uses a successive approximation as yours does.

Accuracy, or lack thereof stems from a number of issues:

* The sample rate has to be 2MHz or better
* Any phase delay between the samples will introduce an error.
* There is a second order error introduced between the plan position of the pellet on the target and the slant range between the hole and the sensor.  This error is balanced out when the shot is in the 10 ring, but gets worst if the shot is close to one sensor and far away from the others.  The setting Z_OFFSET tries to compensate for this by calculating the slant range and then projecting it back onto the target.
* Another error is introduced by sound fading based on the square of the distance to the hole to the sensor.  Again, this is worst when the shot is close to one sensor and far from the others
* Paper tearing.  Looking at lots of oscilloscope traces, I can see that some sensors pick up a nice sharp tear and the others will see a slopey one.  I presume that the paper does not always tear consistently around the pellet.

Allan

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

lboross, 2024-02-11:
@ten-point-nine
Wow, sounds like an impressive update. Looking forward to the next release!

Do you think this would work well with supersonic ammo? Would it pick up the sonic crack of the projectile rather than the paper?

ten-point-nine, 2024-02-11:
It should pick up the shockwave better than paper tearingAllanSent from my iPhoneOn Feb 11, 2024, at 06:23, lboross ***@***.***> wrote:
@ten-point-nine
Wow, sounds like an impressive update. Looking forward to the next release!
Do you think this would work well with supersonic ammo? Would it pick up the sonic crack of the projectile rather than the paper?

—Reply to this email directly, view it on GitHub, or unsubscribe.You are receiving this because you were mentioned.Message ID: ***@***.***>

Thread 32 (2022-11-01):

Mobile client

geniushkg, 2022-11-01:
I am software developer and so far I understand that all data passed in JSON format to windows application , not sure but with some technical guidance I think we can eliminate laptops completely and use Mobile device to display output.

would more then happy to write open source mobile app to connect to Free-target, but lets gauge intrest of community
if you all think this feature will be helpful please plus one this issue , or add comment

AzmodanRO, 2022-11-01:
hi
the pc client was done because of the quick and easy work with .NET framework. if you want to write a mobile client, go ahead. it would be a great idea and a great addition to the project.

ten-point-nine, 2022-11-01:
Hello

Arjen in the Netherlands has been working on a solution for some time now.

Maybe you can get with him to work on it.

Allan

Sent from my iPhone

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

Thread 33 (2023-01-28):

The problem with the launch

digitalsound3312, 2023-01-28:
I designed the board and filter according to the scheme provided in EasyEDA, I can provide the source files with your permission. But only when I achieve working condition. At the moment, after the power supply, the X LED lights up. (S sensor error, probably). I ask for help, where to look? According to the oscilloscope, it can be seen from the control points that the sensors are all triggered. For each separately, it can be seen that after hitting the contacts 3,6,8,11 74HC00, 8 MHz strobing begins on the counter 74LV8154. Which suggests that the sensor, amplifier and trigger are working.
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

digitalsound3312, 2023-01-28:
I will add that I do not connect the Face sensor. I put a jumper on the S sensor. When hitting the I sensor, the terminal writes: PASS

MikeHoed, 2023-01-29:
experiencing exact the same issue. designed pcb according 3.1 schematics in EasyEDA and only x-LED.  high pass connected, but no face sensor connected. shot not registered.

ten-point-nine, 2023-01-29:
It is showing that the calibration is not completed.Adjust the trip voltage to 1.25 voltsTest that the sensors work Type ! To acknowledge the test completeSent from my iPhoneOn Jan 29, 2023, at 04:10, MikeHoed ***@***.***> wrote:
experiencing exact the same issue. designed pcb according 3.1 schematics in EasyEDA and only x-LED.  high pass connected, but no face sensor connected. shot not registered.

—Reply to this email directly, view it on GitHub, or unsubscribe.You are receiving this because you are subscribed to this thread.Message ID: ***@***.***>

digitalsound3312, 2023-01-29:
Совершенно верно, я методом научного тыка нажал кнопку CALL в диалоговом окне, постучал по поверхности некоторое времяи заметил, что плата заработала. Мой вариант платы получился рабочим, если разрешат авторы, могу прислать исходные файлы, по которым сразу отправить на изготовление.

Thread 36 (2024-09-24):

Typo mismatch

rsamanez, 2024-09-24:
Hi,
Actually, I'm not sure if this is a typo or the code was modified for some reason.
It's in the Arduino software, in the "freeETarget.ino" file, in the arm() implementation function, line 380
```
if ( sensor_status & TRIP_EAST )
```
I think it should be changed with
```
if ( sensor_status & TRIP_NORTH )
```

ten-point-nine, 2024-09-24:
Thank you I’ll look into it.

Did it cause an error, or how did you find it?

Thanks

Allan

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

ten-point-nine, 2024-09-24:
You are correct it is a typo.Fortunately it doesn’t affect the normal operation of the target.I’ll see if it was copied to Version 5ThanksAllanSent from my iPhoneOn Sep 24, 2024, at 13:06, Rommel Samanez ***@***.***> wrote:
Hi,
Actually, I'm not sure if this is a typo or the code was modified for some reason.
It's in the Arduino software, in the "freeETarget.ino" file, in the arm() implementation function, line 380
if ( sensor_status & TRIP_EAST )

I think it should be changed with
if ( sensor_status & TRIP_NORTH )

—Reply to this email directly, view it on GitHub, or unsubscribe.You are receiving this because you are subscribed to this thread.Message ID: ***@***.***>

ten-point-nine, 2024-09-24:
ThanksI checked version 5 and that portion does the test a different way, so the bug was not propagated AllanSent from my iPhoneOn Sep 24, 2024, at 13:31, Allan Brown ***@***.***> wrote: Thank you I’ll look into it.Did it cause an error, or how did you find it?ThanksAllanOn Sep 24, 2024, at 1:06 PM, Rommel Samanez ***@***.***> wrote:Hi,
Actually, I'm not sure if this is a typo or the code was modified for some reason.
It's in the Arduino software, in the "freeETarget.ino" file, in the arm() implementation function, line 380
if ( sensor_status & TRIP_EAST )
I think it should be changed with
if ( sensor_status & TRIP_NORTH )
—Reply to this email directly, view it on GitHub, or unsubscribe.You are receiving this because you are subscribed to this thread.Message ID: ***@***.***>

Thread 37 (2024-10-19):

Missing ESP32 based Kicad Design Files

dhitalprabhat, 2024-10-19:
Hi, I can not find KiCad files or schematic for ESP32 based version. Can you point me in right direction?

ten-point-nine, 2024-10-19:
They are not currently availableSent from my iPhoneOn Oct 19, 2024, at 12:17, dhitalprabhat ***@***.***> wrote:
Hi, I can not find KiCad files or schematic for ESP32 based version. Can you point me in right direction?

—Reply to this email directly, view it on GitHub, or unsubscribe.You are receiving this because you are subscribed to this thread.Message ID: ***@***.***>

dhitalprabhat, 2024-10-20:
Is there any plan to release it or will it be closed source?

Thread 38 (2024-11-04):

second USB

genasamara, 2024-11-04:
Hello friends. Please tell me what is the second USB connector on the Main Board Version 3.1 Schematics for?

ten-point-nine, 2024-11-04:
That is to drive a second PC client for a coachAllanSent from my iPhoneOn Nov 4, 2024, at 01:55, genasamara ***@***.***> wrote:
Hello friends. Please tell me what is the second USB connector on the Main Board Version 3.1 Schematics for?

—Reply to this email directly, view it on GitHub, or unsubscribe.You are receiving this because you are subscribed to this thread.Message ID: ***@***.***>

genasamara, 2024-11-04:
thank you very much for your quick reply.

with your permission I will ask one more question.
did I understand correctly that output A 7 and D23 are shorted on the arduino board

ten-point-nine, 2024-11-04:
￼
This is the as-built schematic from the manufacturer.

A7 is unused and brought to a pad as a spare
D23 is also unused and used as a spare

Allan

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

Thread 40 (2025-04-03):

Can't connect to Wifi (Station Mode)

AussieMakerGeek, 2025-04-03:
Hi, I've got my ESP01 module connected to the target and it works fine in AP mode but I'd really like for it to be in Station/Client mode

When I configure using json:
`{"WIFI_SSID":"myap","WIFI_PWD":"mypassword"}`

It refuses to connect:
```
3.041368: esp01: Connecting to an access point: myap,mypassword
3.045548: esp01: Failed AT+CWQAP
43.464165: esp01: Failed AT+CWJAP_DEF="myap","mypassword"
43.467396: esp01: Failed AT+CIPMUX=1
43.471462: esp01: Failed AT+CIPSERVER=1,1090
43.475380: esp01: Failed AT+CIPSTO=7000
43.476002: esp01: Initialization complete
44.480274: POST LEDs
45.230930: Clearing serial buffers
45.231476: Finished startup
```
I increased the timeout to 20 seconds over the standard 10 as you can see in the timestamps, but it has not helped.
I expect the CWQAP command to fail because it was not currently connected to anything.

However, If I flash a a simple sketch for serial passthrough to the module, and manually type the commands, it works fine:
```
AT+CWMODE=1
OK
AT+CWJAP_DEF="myap","mypassword"

WIFI CONNECTED
WIFI GOT IP

OK
```

I can't see anything obvious as to why this is, as the commands seem identical, other than perhaps the response expected not matching, but then I would still expect the following AT commands to work.

Any idea why this might be happening?

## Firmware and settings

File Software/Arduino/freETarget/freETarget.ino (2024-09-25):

/*----------------------------------------------------------------
 * 
 * freETarget        
 * 
 * Software to run the Air-Rifle / Small Bore Electronic Target
 * 
 *-------------------------------------------------------------*/
#include "freETarget.h"
#include "gpio.h"
#include "compute_hit.h"
#include "analog_io.h"
#include "json.h"
#include "EEPROM.h"
#include "nonvol.h"
#include "mechanical.h"
#include "diag_tools.h"
#include "esp-01.h"
#include "timer.h"
#include "token.h"

shot_record_t record[SHOT_STRING];          //Array of shot records
volatile unsigned int this_shot;            // Index into the shot array  
volatile unsigned int last_shot;            // Last shot processed.

double        s_of_sound;                   // Speed of sound
unsigned int  shot = 0;                     // Shot counter
unsigned int  face_strike = 0;              // Miss Face Strike interrupt count
unsigned int  is_trace = 0;                 // Turn off tracing
unsigned int  rapid_count = 0;              // Number of shots to be expected in Rapid Fire
unsigned int  tabata_state;                 // Tabata state
unsigned int  shot_number;                  // Shot Identifier
volatile unsigned long  keep_alive;         // Keep alive timer
volatile unsigned long  tabata_rapid_timer; // Tabita or Rapid fire timer
volatile unsigned long  in_shot_timer;      // Time inside of the shot window
volatile unsigned long  power_save;         // Power save timer
volatile unsigned long  token_tick;         // Token ring watchdog
volatile unsigned long  gpt;                // General purpose timer

const char* namesensor[] = { "TARGET",                                                                                           //  0
                        "1",      "2",        "3",     "4",      "5",       "6",       "7",     "8",     "9",      "10",    //  1
                        "DOC",    "DOPEY",  "HAPPY",   "GRUMPY", "BASHFUL", "SNEEZEY", "SLEEPY",                            // 11
                        "RUDOLF", "DONNER", "BLITZEN", "DASHER", "PRANCER", "VIXEN",   "COMET", "CUPID", "DUNDER",          // 18  
                        "ODIN",   "WODEN",   "THOR",   "BALDAR",                                                            // 26
                        0};
                  
const char nesw[]   = "NESW";                  // Cardinal Points
const char to_hex[] = "0123456789ABCDEF";      // Quick Hex to ASCII
static void bye(void);                         // Say good night Gracie
static long tabata(bool reset_time);           // Tabata state machine
static bool discard_tabata(void);              // TRUE if the shot should be discarded 

#define TABATA_OFF          0         // No tabata cycles at all
#define TABATA_REST         1         // Tabata is doing nothing (typically 60 seconds)
#define TABATA_WARNING      2         // Time the warning LED is on (typically 2 seconds)
#define TABATA_DARK         3         // Time the warning LED is off before the shot (typically 2 seconds)
#define TABATA_ON           4         // Time the TABATA lED is on (typically 5 seconds)

/*----------------------------------------------------------------
 * 
 * function: setup()
 * 
 * brief: Initialize the board and prepare to run
 * 
 * return: None
 * 
 *--------------------------------------------------------------*/

void setup(void) 
{    
/*
 *  Setup the serial port
 */
  Serial.begin(115200, SERIAL_8N1);
  AUX_SERIAL.begin(115200, SERIAL_8N1); 
  DISPLAY_SERIAL.begin(115200, SERIAL_8N1); 
  POST_version();                         // Show the version string on all ports
  
  init_gpio();  
  init_sensors();
  init_analog_io();
  init_timer();
  set_LED('*', '.', '.');                 // Hello World
  read_nonvol();
  
  is_trace = DLT_CRITICAL;                // Turn on tracing

/*
 *  Set up the port pins
 */
  timer_new(&keep_alive,    (unsigned long)json_keep_alive * ONE_SECOND); // Keep alive timer
  timer_new(&tabata_rapid_timer,   0);                                    // Free running tabata or rapid fire timer
  timer_new(&in_shot_timer, FULL_SCALE);                                  // Time inside of the shot window
  timer_new(&power_save,    (unsigned long)(json_power_save) * (long)ONE_SECOND * 60L);// Power save timer
  timer_new(&token_tick,    5 * ONE_SECOND);                              // Token ring watchdog
  timer_new(&gpt,           0);                                           // General purpose timer
  
  randomSeed( analogRead(V_REFERENCE));   // Seed the random number generator
  
/*
 * Initialize variables
 */
   set_LED('.', '.', '*');                // Hello World
   tabata(true);                          // Reset the Tabata timers
  
/*
 * Run the power on self test
 */
  set_LED('*', '.', '*');                 // Hello World
  while ( (POST_counters() == false)      // If the timers fail
              && !DLT(DLT_CRITICAL))          // and not in trace mode (DIAG jumper installed)
  {
    Serial.print(T("POST_2 Failed\r\n"));// Blink the LEDs
    blink_fault(POST_COUNT_FAILED);       // and try again
  }
  
/* 
 *  Setup the timer
 */
  set_LED('.', '*', '.');                 // Hello World

  if ( DLT(DLT_CRITICAL) )
  {
    Serial.print(T("Starting timers"));
  }

  enable_timer_interrupt();
     
/*
 * Initialize the WiFi or token ring if available
 */

   set_LED('*', '*', '.');                 // Hello World
   esp01_init();                         // Prepare the WiFi channel if installed
   
/*
 * Ready to go
 */ 
  multifunction_switch();
  set_LED('*', '*', '*');                 // Hello World
  set_LED_PWM(json_LED_PWM);
  POST_LEDs();                            // Cycle the LEDs
  set_LED(LED_READY);                     // to a client, then the RDY light is steady on
  
  if ( DLT(DLT_CRITICAL) )
  {
    Serial.print(T("Clearing serial buffers"));
  }
  while ( available_all() )
  {
    get_all();                                // Flush any garbage before we start up
  }
  
  DLT(DLT_CRITICAL); 
  Serial.print(T("Finished startup\n\r"));
  show_echo();
  return;
}

/*----------------------------------------------------------------
 * 
 * function: loop()
 * 
 * brief: Main control loop
 * 
 * return: None
 * 
 *----------------------------------------------------------------
 */
#define SET_MODE      0           // Set the operating mode
#define ARM        (SET_MODE+1)   // State is ready to ARM
#define WAIT       (ARM+1)        // ARM the circuit and wait for a shot
#define REDUCE     (WAIT+1)     // Reduce the data
#define FINISH     (REDUCE+1)     // Wait for the shot to end

unsigned int state = SET_MODE;
unsigned int old_state = ~SET_MODE;

unsigned int  sensor_status;          // Record which sensors contain valid data
unsigned int  location;               // Sensor location 

char* loop_name[] = {"SET_MODE", "ARM", "WAIT", "AQUIRE", "REDUCE", "FINISH" };

void loop() 
{
  unsigned int i, j;              // Iteration Counter
  
/*
 * First thing, handle polled devices
 */
  multifunction_switch();         // Read the switches
  tabata(false);                  // Update the Tabata state

/*
 * Take care of any commands coming through
 */

  switch (json_token )
  {
    case TOKEN_WIFI:
      esp01_receive();
      break;

    case TOKEN_MASTER:
      if ( token_tick == 0)             // Time to check the token ring?
      {
        token_init();                   // Request an enumeration
        if ( my_ring == TOKEN_UNDEF )
        {
          token_tick = ONE_SECOND * 5;  //  Waiting to start up
        }
        else
        {
          token_tick = ONE_SECOND * 60; // Just check
        }
      }

    case TOKEN_SLAVE:
      token_poll();                     // Check the token ring
      break;
  }
    
  if ( read_JSON() )
  {
    power_save = (long)json_power_save * 60L * (long)ONE_SECOND;        // Reset the power down timer if something comes in
  }

/*
 * Take care of the TCPIP keep alive
 */
 if ( (json_keep_alive != 0)
    && (keep_alive == 0) )              // Time in seconds
 {
    send_keep_alive();
    keep_alive = json_keep_alive * ONE_SECOND;
 }

/*
 * Take care of the low power mode
 */
  if ( (json_power_save != 0 ) 
       && (power_save == 0) )                         // Time in minutes
  {
    bye();                                            // Dim the lights
    power_save = (unsigned long)json_power_save * (unsigned long)ONE_SECOND * 60L;   // Came back. 
    state = SET_MODE;                                 // Reset everything just in case
  }

/*
 * Cycle through the state machine
 */
  if ( (state != old_state) 
      && DLT(DLT_APPLICATION) )
  {
    Serial.print(T("Loop State: ")); Serial.print(loop_name[state]);;
  } 
  old_state = state;
  
  switch (state)
  {
/*
 *  Check for special operating modes
 */
  default:
  case SET_MODE:    // Start of the loop
    state = set_mode();
    break;

  case ARM:         // Arm the circuit
    state = arm();
    break;

  case WAIT:        // Wait for the shot to appear
    state = wait();
    break;

  case REDUCE:     // Reduce the result of one or more shots
    state = reduce();
    break;

  case FINISH:     // Finish up the cycle by movint the witness paper
    state = finish();
    break;
  }
  
/*
 * End of the loop. return
 */
  return;
}

/*----------------------------------------------------------------
 * 
 * function: set_mode()
 * 
 * brief: Set up the modes for the next string of shots
 * 
 * return: Exit to the ARM state
 * 
 *----------------------------------------------------------------
 *
 * The shot cycle is about to start.
 * 
 * This initializes the variables.
 * 
 * The illumination LED is set depending on whether or not 
 * the Tabata or Rapid fire feature is enabled
 *
 *--------------------------------------------------------------*/
 unsigned int set_mode(void)
 {
  unsigned int i;

  for (i=0; i != SHOT_STRING; i++)
  {
    record[i].face_strike = 100;    // Disable the shot record
  }

  if ( json_tabata_enable || json_rapid_enable ) // If the Tabata or rapid fire is enabled, 
  {
    set_LED_PWM_now(0);             // Turn off the LEDs
    set_LED(LED_TABATA_ON);         // Just turn on X
    json_rapid_enable = 0;          // Disable the rapid fire
  }                                 // Until the session starts
  else
  {
    set_LED_PWM(json_LED_PWM);      // Keep the LEDs ON
  }

/*
 * Proceed to the ARM state
 */
  return ARM;                      // Carry on to the target
 }
    
/*----------------------------------------------------------------
 * 
 * function: arm()
 * 
 * brief:  Arm the circuit and check for errors
 * 
 * return: Exit to the WAIT state if the circuit is ready
 *         Stay in the ARM state if a hardware fault was detected
 * 
 *----------------------------------------------------------------
 *
 * The shot cycle is about to start.
 * 
 * This initializes the variables.
 * 
 * The illumination LED is set depending on whether or not 
 * the Tabata or Rapid fire feature is enabled
 *
 *--------------------------------------------------------------*/
unsigned int arm(void)
{
  face_strike = 0;                  // Reset the face strike count
  if ( json_send_miss
        && (json_face_strike != 0))
  {
    enable_face_interrupt();        // Turn on the face strike interrupt
  }

  stop_timers();
  arm_timers();                     // Arm the counters
  
  sensor_status = is_running();     // and immediatly read the status
  if ( sensor_status == 0 )         // After arming, the sensor status should be zero
  { 
    if ( DLT(DLT_APPLICATION) )
    {
      Serial.print(T("Waiting..."));
    }  
    return WAIT;                   // Fall through to WAIT
  }

/*
 * The sensors are tripping, display the error
 */
  if ( sensor_status & TRIP_NORTH  )
  {
    Serial.print(T("\r\n{ \"Fault\": \"N\" }"));
    set_LED(NORTH_FAILED);           // Fault code North
    delay(ONE_SECOND);
  }
  if ( sensor_status & TRIP_EAST  )
  {
    Serial.print(T("\r\n{ \"Fault\": \"E\" }"));
    set_LED(EAST_FAILED);           // Fault code East
    delay(ONE_SECOND);
  }
  if ( sensor_status & TRIP_SOUTH )
  {
    Serial.print(T("\r\n{ \"Fault\": \"S\" }"));
    set_LED(SOUTH_FAILED);         // Fault code South
    delay(ONE_SECOND);
  }
  if ( sensor_status & TRIP_WEST )
  {
    Serial.print(T("\r\n{ \"Fault\": \"W\" }"));
    set_LED(WEST_FAILED);         // Fault code West
    delay(ONE_SECOND);
  }

/*
 * Got an error, try to arm again
 */
  return ARM;
}
   
/*----------------------------------------------------------------
 * 
 * function: wait()
 * 
 * brief: Wait here for a shot to be fired
 * 
 * return: Exit to the WAIT state if the circuit is ready
 *         Stay in the ARM state if a hardware fault was detected
 * 
 *----------------------------------------------------------------
 *
 * This loop is executed indefinitly until a shot is detected
 * 
 * In this loop check
 *    - State of the WiFi interface
 *
 *--------------------------------------------------------------*/
static bool rapid_once;

unsigned int wait(void)
{
/*
 * Monitor the WiFi and blink if WiFi is present but not connected
 * Set RDY to solid red if there is a connection to the PC client
 */
  if ( ((json_token == TOKEN_WIFI) && ((esp01_is_present() == false) || esp01_connected() ))         // If the esp01 is not present, or connected
          || ((json_token != TOKEN_WIFI) && (my_ring != TOKEN_UNDEF)) )
  {
    set_LED(LED_READY);                 // to a client, then the RDY light is steady on
  }
  else
  {
    if ( (millis() / 1000) & 1 )       // Otherwise blink the RDY light
    {
      set_LED(LED_READY);
    }
    else
    {
      set_LED(LED_OFF);
    }
  }

/*
 * Check to see if the time has run out if there is a rapid fire event in progress
 */

  if (json_rapid_enable == 1)         // The rapid fire timer has been turned on
  {
    if (tabata_rapid_timer == 0 )     // Do this until the timer expires
    {
      set_LED_PWM_now(0);
      Serial.print(T("{\"RAPID_OVER\": 0}\r\n"));
      return FINISH;                   // Finish this rapid fire cycle
    }
    else
    {
      if ( rapid_once )
      {
        Serial.print(T("{\"RAPID_START\": ")); Serial.print(json_rapid_time); Serial.print(T("}\r\n"));
      }
      set_LED_PWM_now(json_LED_PWM);   // make sure the lighs are on
    }
  }

/*
 * See if any shots have arrived
 */
  if ( this_shot != last_shot )
  {
    return REDUCE;
  }
  
/*
 * All done, keep waiting
 */
  return WAIT;
}


/*----------------------------------------------------------------
 * 
 * function: reduce()
 * 
 * brief: Loop through one or more shots and present the score
 * 
 * return: Stay in the reduce state if a follow through timer is active 
 *         Jump to ARM state if more shots are ecpected
 * 
 *----------------------------------------------------------------
 *
 * This function runs in foreground and loops through the 
 * shot structure whenever there are shots in hardware to be
 * reduced.
 * 
 * In the case of rapid fire, the shot processing stops when
 * the requisite number of shots have been received.
 *
 * The shots are accumulated in the timer interrrupt which keeps
 * a queue in record[last_shot -> this shot].  The reduce()
 * loops and reduces all of the waiting shots.
 * 
 *--------------------------------------------------------------*/
unsigned int reduce(void)
{
/*
 * See if any shots are allowed to be processed
 */
  if ( discard_shot() )                                       // Tabata is on but the shot is invalid
  {
    if ( DLT(DLT_APPLICATION) )
    {
      Serial.print(T("Discarding shot: ")); Serial.print(last_shot); Serial.print(T("\r\nTrigger: ")); 
    }
    last_shot = this_shot;
    send_miss(&record[last_shot]);
    return FINISH;                                              // Throw out any shots while dark
  }
  
/*
 * Loop and process the shots that were accumulated by the timer interrupt
 */
  while (last_shot != this_shot )
  {   
    location = compute_hit(&record[last_shot]);                 // Compute the score
    
    if ( DLT(DLT_APPLICATION) )
    {
      Serial.print(T("Reducing shot: ")); Serial.print(last_shot); Serial.print(T("\r\nLocation: ")); Serial.print(location);
    }

    if ( location != MISS )                                     // Was it a miss or face strike?
    {
      if ((json_rapid_enable == 0) && (json_tabata_enable == 0))// If in a regular session, hold off for the follow through time
      {
        delay(ONE_SECOND * json_follow_through);
        if ( DLT(DLT_APPLICATION) )
        {
          Serial.print(T("Follow through: ")); Serial.print(json_follow_through);
        }
      }
      send_score(&record[last_shot]);
      rapid_red(0);
      rapid_green(1);                                           // Turn off the RED and turn on the GREEN

      if ( (json_paper_time + json_step_time) != 0 )            // Has the witness paper been enabled?
      {
        if ( ((json_paper_eco == 0)                             // ECO turned off
            || ( sqrt(sq(record[this_shot].xphys_mm) + sq(record[this_shot].yphys_mm)) < json_paper_eco )) ) // Outside the black
        {
          drive_paper();                                        // to follow through.
        }
      } 
    }
    else
    {
      if ( DLT(DLT_APPLICATION) )
      {
        Serial.print(T("Shot miss...\r\n"));
      }
      blink_fault(SHOT_MISS);
      send_miss(&record[last_shot]);
      rapid_green(0);
      rapid_red(1);                                             // Show a miss
    }

/* 
 *  Check to see if we should stop sending scores
 */
    if ( rapid_count != 0 )                                     // Decriment shots remaining
    {
      rapid_count--;                                            // in rapid fire
    }
    
/*
 * Increment and process the next
 */
    if ( (tabata_rapid_timer != 0) )                            // In a rapid fire cycle
    {
      if ( rapid_count == 0 )                                   // And the shots used up?
      {
        last_shot = this_shot;                                  // Stop processing
        break;
      }
    }
    
    last_shot = (last_shot+1) % SHOT_STRING;                    // Increment to the next active shot
  } //   End while (last_shot != this_shot )

/*
 * All done, Exit to FINISH if the timer has expired
 */
  if ( tabata_rapid_timer == 0 )
  {
    return FINISH;
  } 
  else
  {
    return WAIT;
  }
}
    
/*----------------------------------------------------------------
 * 
 * function: finish()
 * 
 * brief: Finish up the shot cycle 
 * 
 * return: Retrn to the SET_MODE state
 *
 *----------------------------------------------------------------
 *
 *--------------------------------------------------------------*/
unsigned int finish(void)
{
 
/*
 * All done, return
 */
  power_save = (long)json_power_save * 60L * (long)ONE_SECOND;     
  return SET_MODE;
}

/*----------------------------------------------------------------
 * 
 * function: tabata_enable
 * 
 * brief:    Start or stop a tabata session
 * 
 * return:   Nothing
 * 
 *----------------------------------------------------------------
 *
 * {"TABATA_WARN_ON": 1, "TABATA_WARN_OFF":5, "TABATA_ON":7, "TABATA_REST":30, "TABATA_ENABLE":1}
 * {"TABATA_WARN_ON": 2, "TABATA_WARN_OFF":2, "TABATA_ON":7, "TABATA_REST":45, "TABATA_ENABLE":1}
 * {"TABATA_ENABLE":0}
 * 
 *--------------------------------------------------------------*/
 
 void tabata_enable
  (
    unsigned int enable     // Rapid fire enable state
  )
 {
  char str[32];
  long random_wait;

/*
 * If enabled, set up the timers
 */
  if ( enable != 0 )
  {
    set_LED_PWM_now(0);                                           // Turn off the LEDs (maybe turn them on later)
  }
  else
  {
    set_LED_PWM_now(json_LED_PWM);                                // Turn on the LED to start the cycle
  }
  
  tabata_state = TABATA_OFF;                                      // Reset back to the beginning
  json_tabata_enable = enable;                                    // And enable

  sprintf(str, "{\"TABATA_ENABLED\":%d}\r\n", enable);
  output_to_all(str);

  
/*
 * All done, return
 */
  return;
 }

/*----------------------------------------------------------------
 * 
 * function: tabata
 * 
 * brief:   Implement a Tabata timer for training
 * 
 * return:  Time that the current TABATA state == TABATA_ON
 * 
 *----------------------------------------------------------------
 *
 * A Tabata timer is used to train for specific durations or time
 * of events.  For example in shooting the target should be aquired
 * and shot within a TBD seconds.
 * 
 * This function turns on the LEDs for a configured time and
 * then turns them off for another configured time and repeated
 * for a configured number of cycles
 * 
 * OFF - 2 Second Warning - 2 Second Off - ON 
 * 
 * Test JSON 
 * {"TABATA_WARN_ON": 1, "TABATA_WARN_OFF":5, "TABATA_ON":7, "TABATA_REST":30, "TABATA_ENABLE":1}
 * {"TABATA_WARN_ON": 2, "TABATA_WARN_OFF":2, "TABATA_ON":7, "TABATA_REST":45, "TABATA_ENABLE":1}
 * {"TABATA_WARN_ON": 2, "TABATA_WARN_OFF":2, "TABATA_ON":7, "TABATA_REST":45, "TABATA_ENABLE":0}
 * 
 *-------------------------------------------------------------*/

static uint16_t old_tabata_state = ~TABATA_OFF;

static long tabata
  (
  bool reset_time                     // TRUE if starting timer
  )
{
  char s[32];

  
/*
 * Reset the variables based on the arguements
 */
   if ( (json_tabata_enable == 0) || reset_time )   // Reset the timer
   {
      tabata_state = TABATA_OFF;
   }
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

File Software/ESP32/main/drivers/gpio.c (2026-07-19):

/*-------------------------------------------------------
 *
 * gpio.c
 *
 * General purpose GPIO driver
 *
 * ----------------------------------------------------*/
#include <string.h>
#include "esp_log.h"
#include "driver/rmt_tx.h"
#include "gpio_types.h"
#include "driver\gpio.h"
#include "esp_timer.h"
#include "led_strip_types.h"

#include "freETarget.h"
#include "board_assembly.h"
#include "compute_hit.h"
#include "diag_tools.h"
#include "gpio.h"
#include "timer.h"
#include "json.h"
#include "serial_io.h"
#include "timer.h"
#include "pcnt.h"
#include "gpio_define.h"
#include "mfs.h"
#include "dac.h"
#include "analog_io.h"
#include "pwm.h"
#include "serial_io.h"
#include "../managed_components/espressif__led_strip/src/led_strip_rmt_encoder.h"

/*
 * function prototypes
 */

/*
 *  Typedefs
 */
typedef struct status_struct
{
  int blue;  // Bits to send to the LED
  int green;
  int red;
  int blink; // TRUE if blinking enabled
} status_struct_t;

/*
 * Variables
 */
status_struct_t status[3] = {
    {0, 0, 0, 0},
    {0, 0, 0, 0},
    {0, 0, 0, 0}
};
int                   paper_state;   // Drive is ON or OFF
time_count_t          paper_time;    // How long the paper will be on for
volatile unsigned int step_count;    // How many step counts do we need?
volatile unsigned int step_time;     // Interval to next step
static bool           motor_running; // TRUE if the motor is running (for diagnostics)

/*-----------------------------------------------------
 *
 * @function: is_running
 *
 * @brief: Determine if the clocks are running
 *
 * @return: TRUE if any of the counters are running
 *
 *-----------------------------------------------------
 *
 * Read in the running registers, and return a 1 for every
 * register that is running.
 *
 * It is up to the application to ignore unused RUN bits
 * (ex RUN_NORTH_HI) is PCNT Latency has been removed
 *
 *----------------------------------- ------------------*/
unsigned int is_running(void)
{
  unsigned int return_value;
  unsigned int i;

  return_value = 0; //

  /*
   * Read the running inputs
   */
  for ( i = N; i <= W; i++ )
  {
    if ( gpio_get_level(s[i].low_sense.sensor_GPIO) != 0 )
    {
      return_value |= s[i].low_sense.run_mask;
    }
    if ( PCNT_HIGH_GPIO & board_mask )
    {
      if ( gpio_get_level(s[i].high_sense.sensor_GPIO) != 0 )
      {
        return_value |= s[i].high_sense.run_mask;
      }
    }
  }
  /*
   *  Return the run mask
   */
  return (return_value); // Return the running mask INCLUDING PCNT HI
}

/*-----------------------------------------------------
 *
 * @function: arm_timers
 *
 * @brief: Strobe the control lines to start a new cycle
 *
 * @return: NONE
 *
 *-----------------------------------------------------
 *
 * The counters are armed by
 *
 *   Stopping the current cycle
 *   Clearing the counters
 *   Enabling the counters to run again
 *
 *-----------------------------------------------------*/
void arm_timers(void)
{
  gpio_set_level(CLOCK_START, CLOCK_TRIGGER_OFF);
  gpio_set_level(STOP_N, RUN_OFF);      // Reset the timer
  gpio_set_level(OSC_CONTROL, OSC_OFF); // Turn off the oscillator

  pcnt_clear();
  if ( (PCNT_HIGH_GPIO & board_mask) && json_pcnt_latency != 0 )
  {
    gpio_intr_enable(RUN_NORTH_HI);     // Turn on the interrupts
    gpio_intr_enable(RUN_EAST_HI);
    gpio_intr_enable(RUN_SOUTH_HI);
    gpio_intr_enable(RUN_WEST_HI);
  }
  gpio_set_level(OSC_CONTROL, OSC_ON);  // Turn on the oscillator

  gpio_set_level(STOP_N, RUN_GO);       // Then enable it
  return;
}

/*
 *  Stop the oscillator and RUN_xx controls
 */
void stop_timers(void)
{
  gpio_set_level(OSC_CONTROL, OSC_OFF); // Turn off the oscillator
  gpio_set_level(STOP_N, RUN_OFF);      // Clear the flip flop
  return;
}

/*
 *  Trigger the timers for a self test
 */
void trigger_timers(void)
{
  gpio_set_level(CLOCK_START, CLOCK_TRIGGER_OFF); // Send out a 0-1-0 to
  gpio_set_level(CLOCK_START, CLOCK_TRIGGER_ON);  // the flip flops to
  gpio_set_level(CLOCK_START, CLOCK_TRIGGER_OFF); // clock in a 1 and start the process

  return;
}
/*-----------------------------------------------------
 *
 * @function: read_DIP
 *
 * @brief: READ the jumper block setting
 *
 * @return: TRUE for every position with a jumper installed
 *
 *-----------------------------------------------------
 *
 * The DIP register is read and formed into a word.
 * The word is complimented to return a 1 for every
 * jumper that is installed.
 *
 *-----------------------------------------------------*/

unsigned int read_DIP(void)
{
  unsigned int return_value = 0;
  unsigned int dips[]       = {DIP_A, DIP_B, DIP_C, DIP_D};
  unsigned int bit_mask[]   = {0x08, 0x04, 0x02, 0x01};
  unsigned int i;

  for ( i = 0; i != 4; i++ )
  {
    if ( gpio_get_level(dips[i]) != 0 )
    {
      return_value |= bit_mask[i];
    }
  }

  return return_value;
}
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

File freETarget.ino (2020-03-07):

/*----------------------------------------------------------------
 * 
 * freETarget
 * 
 * Software to run the Air-Rifle / Small Bore Electronic Target
 * 
 *----------------------------------------------------------------
 *
 */
#include "gpio.h"
#include "compute_hit.h"

/*
 * Compilation Flags
 */
 #define TRACE_PWM      true
 
 // Trace the PWM registers
#define TRACE_COUNTERS true  // Trace the COUNTER values
#define ONE_SHOT       false // Just capture one shot
#define CLOCK_TEST     true  // Just sample the clock inputs
#define SHOW_PLOT      false // Disable the 2D graph
 

#define ONE_SECOND    1000      // 1000 ms delay
#define TRIP_POINT    50.0      // Set the trip point 5 above the dc_bias
#define PWM_GAIN      0.04     // Control loop gain
#define DEAD_BAND_LO  (dc_bias + (TRIP_POINT - 10.0))   // Allow a +/- deadband
#define DEAD_BAND_HI  (dc_bias + (TRIP_POINT + 10.0))   // High Hysterysis
#define SHOT_TIME     300       // Wait 300 ms for the shot to end

#define CLOCK_RATE    (8.0)               // Clock rate in MHz
#define CLOCK_PERIOD  (1.0/CLOCK_RATE)    // Seconds per bit

/*
 *  Sensor Geometry.  Note, values can be scaled on output
 */
#define RADIUS   (81.6/2.0)  // Radius of target in mm

#define NX 0.0             // Location of North sensor
#define NY RADIUS

#define EX RADIUS          // Location of East sensor
#define EY 0.00

#define SX 0.0             // Location of South sensor
#define SY (-RADIUS)

#define WX (-RADIUS)       // Location of West sensor
#define WY 0.0

#define WIDTH 300           // Width of target in pixels
#define FWIDTH (300.0)      // floating point value

/*
 * Target Geometry
 */
#define RIFLE   (46.0 / 2.0)       // Rifle target, 46 mm
#define PISTOL  (75.0 /2.0 )       // Pistol target, 75 m

/*
 * Variables
 */
unsigned int  north, east, south, west;           // 16 bit counter registers
unsigned int  portA, portB, portC, portD, portG, portL;


double        hit_x, hit_y;     // Location of the shot
double        score;            // Score based on 10.9
double        click_x, click_y; // Adjustment Clicks
int           shot_count;       // Shot counter
double        dc_bias;          // Computed DC bias
double        pwm_control;      // Control value sent to PWM
double        pwm_reference;    // Analog input read back from pwm
unsigned long time_out;

unsigned int b_intercept[WIDTH+1], c_intercept[WIDTH+1];
double d[WIDTH+1];              // Convert index to distance
unsigned int left, right;       // Left and right side of active target
const char* which_one[4] = {"  <<NORTH>>  ", "  <<EAST>>  ", "  <<SOUTH>>  ", "  <<WEST>>  "};

/*----------------------------------------------------------------
 * 
 * void setup()
 * 
 * Initialize the board and prepare to run
 * 
 *----------------------------------------------------------------
 */
void setup() 
{
  int i;
/*
 *  Setup the serial port
 */
  Serial.begin(115200);
  Serial.println("\n\rfreETarget");

/*
 *  Set up the port pins
 */
  init_gpio();

/*
 *  Initialize the variables
 */
  shot_count = 1;
  time_out = micros();

  for (i=0; i != WIDTH+1; i++)
  {
    d[i] = RADIUS - (float)i * 2.0 * RADIUS/FWIDTH;
  }
  
  left = (FWIDTH/2.0) * (1.0 - RIFLE/RADIUS);
  right = FWIDTH - left;

/*
 * All done, begin the program
 */
 Serial.print("\n\rReady");
 return;
}

/*----------------------------------------------------------------
 * 
 * void loop()
 * 
 * Main control loop
 * 
 *----------------------------------------------------------------
 */
#define ARM           0         // State is ready to ARM
#define WAIT    (ARM+1)         // ARM the circuit
#define AQUIRE (WAIT+1)         // Aquire the shot
#define REDUCE (AQUIRE+1)       // Reduce the data
#define WASTE  (REDUCE+1)
void loop() 
{
  unsigned int state = ARM;
  unsigned long now;
  unsigned int shot = 0;
  double x_time, y_time;        // Location in time
  
 while (1)
 {
/*
 * Cycle through the state machine
 */
  switch (state)
  {
/*
 * Arm the circuit
 */
  default:
  case ARM:
    arm_counters();
    set_LED(LED_S, true);     // Show we are waiting
    set_LED(LED_X, false);    // No longer processing
    state = WAIT;
    break;
    
/*
 * Wait for the shot
 */
  case WAIT:
    if ( is_running() )         // Shot detected
      {
      set_LED(LED_S, false);    // No longer waiting
      set_LED(LED_X, true);     // Starting processing
      state = AQUIRE;
      now = micros();           // Remember the starting time
      }
     break;

/*
 *  Aquire the shot              
 */  
  case AQUIRE:
    if ( (micros() - now) > SHOT_TIME )
      {
      state = REDUCE;
      stop_counters();
      }
    break;

/*
 *  Reduce the data to a score
 */
  case REDUCE:
    compute_hit(&x_time, &y_time);
    send_score(shot, x_time, y_time);
    state = ARM;
    break;
    }
  }
}

/*----------------------------------------------------------------
 * 
 * void debug_trace() 
 * 
 * Put debug information on the console
 * 
 *--------------------------------------------------------------*/
void debug_trace (void)
{
#if (TRACE_PWM == true )

#endif

  return;
}

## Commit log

2020-02-26 Pushing Circuit Diagrams
    Pushing circuit diagrams and Arduino software.
    IMPORTANT
    Arduino sofware for reference only and will not work with illustrated circuit board
    [Electronic Target-B_Cu.gbr, Electronic Target-B_Mask.gbr, Electronic Target-B_Paste.gbr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]
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2020-03-15 Board Debug Complete
    The various conters and registes have been tested and appear to be working correctly.
    [analog_io.ino, compute_hit.ino, freETarget.ino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]
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2020-04-21 Pushing Sensor Revisions
    Sensors revised for inverting signal.
    Needed since the 'bang' is a negative going wave form that needs to be inverted
    [Microphones.kicad_pcb, Microphones.sch, Sensor 1.0.X.kicad_pcb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]
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2020-04-22 Revised Sensor with Inverting Amp
    Since the sound signal is negative going, the circuit must use a negative (inverting) gain to create a rising edge when the pellet hits.
    [Microphones.kicad_pcb, Microphones.sch, Sensor 1.0.X.kicad_pcb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]
2020-04-22 Rewvised Sensor Module
    The changes to the sensor module are
    Made larger to simplify assembly
    Correct routing for negative voltage supply
    Moving RTD to the sensor side.
    [Sensors-B_Cu.gbr, Sensors-B_Mask.gbr, Sensors-B_Paste.gbr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]
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2020-04-30 Corrections to temperature probe
    The temperature compensation for the speed of sound has been added in this version
    [analog_io.ino, compute_hit.ino, freETarget.ino]
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2020-05-24 Changed to I2C Temperature Sensor
    The older RTD temperature sensor was replaced by an I2C one located on the main board.
    This also brough in changes to the sensor module and additional data on the JSON shot info
    [Electronic Target.kicad_pcb, Electronic Target.sch, Sensors.kicad_pcb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]
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2020-06-05 Debugging Live Fire Arduino
    During live fire tests, some locations were creating "nan" numbers for the target location.
    Debugging sofware was added to identify the fault, and corrections were made to the software
    [analog_io.ino, compute_hit.ino, diag_tools.ino]
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2020-06-14 Arduino Software after extensive debugging
    Previous versions of the Arduino software had bugs in various locations on the target.
    This version of the software has been extensivly tested and now includes an automated test to generate a pattern for verification on the PC program
    [analog_io.h, analog_io.ino, compute_hit.ino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]
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2020-10-01 Production Revisions to Arduino
    This patch merges the changes that were made on the Allan_Development branch.
    The changes here are:
    Introduction of the JSON decoder
    Test routines for hardware debugging
    Change the algorithm to compute a location if one of the sensors is missing
    [analog_io.h, compute_hit.ino, diag_tools.ino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]
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2020-10-26 Revison 2.2 Data Aquisition
    These are the schematics after board revisions.
    Note, the Gerber files are no longer valid and have been removed.
    [Electronic Target-Edge_Cuts.dxf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]
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2020-10-28 Removed magic numbers
    The board revisons were identified as magic numbers.
    This patch replaces them with #defins
    [analog_io.ino, diag_tools.ino, json.ino]
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2021-01-24 Cluj 2
    Found a problem in the comparitor circuit that was corrected by changing the ground refereence from GND to -5VDC.
    During the course of testing some small changes were made to speed up the validation process.
    [compute_hit.ino, freETarget.ino]
2021-01-26 Schematic Revised to 2.2B
    The LM339 was referenced to ground. In practice the sound signal could go negative as much as 1.3VDC. The absolute maximum rating for this value was -0.3VDC. In practice the short negative voltage would cause a leakage current on the die and result in spurious outputs on the logic (timer start) lines.
    This change puts the -V input to -5VDC so that the input signal is kept above the minimum signal value.
    [Electronic Target.sch, Sensors-Edge_Cuts.dxf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]
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2021-03-28 High Pass Filter Network
    Experimental high pass filter network to reduce the shot noise and increase the detection sensitivity.
    [Filter Network-B_Cu.gbr, Filter Network-B_Mask.gbr, Filter Network-B_Paste.gbr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]
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2021-04-12 Corrected errors in Schematic
    Found a resistor error and reannotated the main board schematic
    [Electronic Target.sch]
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2021-04-21 Firmware V3.00.3
    Found a bug in the MISS detection that would prevent the score from being sent.
    [analog_io.h, compute_hit.ino, diag_tools.ino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]
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2021-04-25 Fixed calibration
    There was a bug in how the LEDs displayed the trip point setting.
    While it worked, it was almost impossible to determine the actual voltage.
    [diag_tools.ino]
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2021-05-03 Testability improvemens
    In preparation for mass production, several small changes were incorporated
    1 - Cleaned up set_LED
    2 - Removed all digitalWrite(LED) with set_LED
    3 - Illumination now fades in and out
    4- Shortened delays at the end of the shot to help with rapid fire
    5 - Undefined board revisions now default to last known good
    6 - delay(value) replaced by delay(% of one second)
    7 - Trip point calibbration can be started without cycling power
    [analog_io.ino, diag_tools.ino, freETarget.ino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]
2021-05-08 Minor bug fixes
    The JSON decoder would not pick up any number in the value field.
    [analog_io.ino, diag_tools.ino, freETarget.ino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]
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2021-05-15 Expanded POST test
    A clock failure mode whereby the timers could not be stopped was anticipated. This test arms the counters but does not start them. It reads the counts back to make sure that they are still zero.
    This test is different from a separate test to make sure they can be stopped once started.
    [diag_tools.h, diag_tools.ino, freETarget.ino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]
2021-05-16 3.01.4 Standardized LED error codes
    The error codes displayed on the LEDs were inconsistent.
    This patch collects the error codes into a single file and standardizes them. At the same time the POST tests were reorganized to conform to the LED error codes.
    [diag_tools.h, diag_tools.ino, freETarget.ino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]
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2021-05-23 3.1.6 Speeding up production test
    This is two minor changes
    1 - The MISS error flashing has been shortened to speed up test
    2 - The JSON show_echo had an error if the location where the value was stored was undefined.
    3 - Adding JSON comment "SN": to code in a serial number
    [gpio.ino, json.ino, nonvol.ino]
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2021-06-15 Version 3.01.9 JSON Bug Fix
    The JSON decoder would not correctly decode a message that contained a floating point number.
    When used, any value present would be overwritten by 0.
    [freETarget.ino, json.ino]
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2021-07-25 Firmware V3.3.0 Correction for paper placement and multiple WiFi
    This patch accomplishes three things
    1 - Adds a factor z_offset to correct for the displacement between the paper and sensor planes.
    Change to json.ino to add z_offset
    Change to nonvol.h to add z_offset to nonvol
    2 - Changes serial.print.. in send_score() and send_miss() to use sprintf so as to simplify esp-01 driver and support three WiFi servers at the same time
    [compute_hit.ino, diag_tools.ino, esp-01.ino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]
2021-07-30 3.3.1 Adding diagnostics to JSON decoder
    Echos JSON input if an error is detected
    [diag_tools.ino, json.ino]
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2021-08-09 Arduino 3.3.4 Correcting DC motor and Stepper Motor contr0l
    Brought Arduino code in line with PC program
    [diag_tools.ino, gpio.ino, json.ino]
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2021-08-17 Revising GRID.XLS
    GRID.XLS is a tool for comparing the actual target position against the computed position to find hardware errors
    [GRID.xlsx]
2021-08-23 3.4.0 Custom Bullseye Targets
    Version 3.4 allows for a five bull rifle target to be used. Shots in each bull is combined into a single bull in the middle.
    This allows for air rifle targets to be used without witness paper.
    Bug fix on witness paper motor drive
    [compute_hit.ino, freETarget.ino, gpio.ino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]
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2021-09-07 added missing commas in ECHO json change DIP - was present twice
    [json.ino]
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2021-09-23 Arduino 3.4.4 Fixed ECHO
    The ECHO command needs to work for the WiFi version of the PC program to operate correctly.
    Previously the ESP-01 driver would overflow and the results were intermittent.
    This patch sends the ECHO strings out to the ESP-01 one line at a time and then waits 100ms for the packet to be transmitted
    [diag_tools.ino, esp-01.ino, gpio.h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]
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2021-09-24 Arduino 3.4.6 Restructured esp01_send
    The esp01_send function works by sending an AT command, followed by the text to be output, followed by a null to trigger the send.
    Earlier versions of the software would output a short string and then a null many times for a single command, ex ECHO. This was not consistent as the ESP01 would periodically lose track of what it was doing and no more text would be output.
    A change was made to force the AT command on every string, but this would mean +++ (one second delay) AT for every line output which became extremely time consuming.
    This patch replaces esp01_send with a state machine that keeps track of what information is waiting in the buffer and th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
    [compute_hit.ino, diag_tools.ino, esp-01.ino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]
2021-09-24 Arduino 3.4.7 Missing { on send_miss corrected
    The first part of the send_miss was missing
    [compute_hit.ino, esp-01.ino]
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2021-09-27 Arduino 3.4.9 Fixed initialization to ignore -1
    The previous program of nonvol.ino used -1 to indicate that a nonvol value had not been initialized and would overwrite the value if -1 was found.
    This version will take any value that it finds in memory and not try to overwrite it.
    [compute_hit.ino, nonvol.ino]
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2021-10-28 Arduino 3.4.15 Fixed bug in initialization command
    {"INIT":1234} was incorrectly implemented as IS_FIXED instead of IS_INT16
    [json.ino]
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2021-10-30 Arduino 3.5.0. Tabata Timer
    Uses the LEDs to illuminate the target for a short period of time to train for hold times or rapid fire pistol
    Refactored software to change history to record
    [analog_io.ino, compute_hit.ino, diag_tools.ino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]
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2022-02-22 Arduino 3.6.11 Cleaning up the LED displayes
    The LED setting function was inconsistent. This patch addresses that issue
    [diag_tools.h, diag_tools.ino, freETarget.ino]
2022-02-22 Preserving CNC changes
    Minor corrections to the CNC files based on assembly experiance
    [Back.skp, Hinge Align.skp, Left Panel.skp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]
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2022-03-16 Arduino 3.7.2: Fixes to the Tabata timer
    The previous version of software would lock up if the Tabata timer was not set up correctly.
    This version also sends JSON strings to the PC {"TABATA":0/1} and {"RAPID":0/1} to indicate a Tabata or rapid fire cyc;e
    [freETarget.ino, gpio.h, gpio.ino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]
2022-04-09 Arduino 3.7.6 Tabata Corrections
    Corrections to Tabata
    Revisions for updating persistent storage
    [diag_tools.ino, esp-01.ino, freETarget.ino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]
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2022-04-27 Arduino 3.7.11 Changes to multifunction switches
    Report current value of the json_power_save if switch used to extend on time
    Added reset to JSON commands
    [diag_tools.ino, esp-01.ino, freETarget.ino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]
2022-04-27 CNC Tooling
    Minor corrections to the tooling to make parts fit better
    [Paper Support.skp]
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2022-05-02 Arduino 3.7.12 LED brightness controlled by MFS
    A new MFS setting was added to allow for changing the LED brigthness from the switches.
    Also added as a delay in the sensor self test to avoid echos
    Removed CALIBRATEION LEDs on power up as they are no longer necessary.
    [diag_tools.ino, freETarget.ino, gpio.h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]
2022-05-02 Mechanical - Freshened CNC files
    Minor corrections to the CNC files to make assembly easier
    [Back.skp, Paper Guide.skp, Top.skp]
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2022-05-23 Arduino 3.8.2 Release Candidate 1
    There was a situation with the WiFI that if the WiFI connection dropped neither the Arduino or PC would detect the failure. On the next WiFi output, the transmit would fail, but the Arduino would attempt to transmit for a very long time.
    This patch simplifies the esp01_send function and shuts down the channel if not founc
    [analog_io.ino, compute_hit.ino, diag_tools.h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]
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2022-10-19 Arduino V4.0.0 RC1
    Development issue for rapid fire pistol
    1 - Counter reads done on a timer task
    2 - Diagnostic trace level can be set
    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
    [analog_io.ino, compute_hit.ino, diag_tools.h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]
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2022-10-30 Arduino 4.0.0 RC7
    Added WIFI_IP to allow for setting the IP to a fixed address
    [esp-01.ino, json.ino, nonvol.ino]
2022-11-01 Arduino 4.0.0 RC8
    Removed ESP-01 debug traces
    Added logging level to ESP driver software
    Allow ESP-01 to assign IP addresses to the PC
    Corrections to SSID programming
    Extended MAX_WAITOK to 10 seconds to allow for SSID negotiation
    [esp-01.ino, json.ino]
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2022-11-04 Arduino 4.0.0 RC11
    DLT now shows time since startup
    Secret JSON setting hides value (ex WIFI_PWD)
    json_follow_through fixed after rapid fire changes
    [analog_io.ino, compute_hit.ino, diag_tools.ino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]
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2022-11-27 Arduino 4.0.5
    SSID now 32 bit
    ESP01 reports an error if it cannot find the SSID
    No whitespace removal between quotes
    [analog_io.ino, esp-01.ino, freETarget.ino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]
2022-12-03 Arduino 4.0.6
    Extended IP address to 12 decimal digits
    bug fix on board revision
    [analog_io.ino, diag_tools.ino, esp-01.ino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]
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2022-12-15 Arduino 4.0.9 Bug fix to ESP-01
    There was a bug in the ESP driver that prevented the correct SSID and password from being set.
    The change also enabled the Arduino to report an error while programming the ESP
    Setting the IP address was removed
    [esp-01.ino, freETarget.ino, gpio.ino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]
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2023-04-06 Arduino 4.1.2 Correction to Multifunction Switch
    It turns out that the multifunction switch function would always delay for one second even if no switches were pressed.
    Now no switch pressed resumes immediately
    [gpio.ino]
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2023-08-02 Arduino 4.2.2 DOPPLER Bug
    Fixed bug in the NONVOL table that prevented the DOPPER from being saved during initialization.
    Perform soft reset after initializing the NONVOL
    [freETarget.ino, nonvol.ino]
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2023-12-20 Arduino 4.2.7 Fixed missed target bug
    Found a bug in the send miss function that hid a miss when used with wifi
    [compute_hit.ino]
2023-12-22 Bug fix in 4.2.7
    Inexplicably changing a text from miss:0 to miss:0 caused the program to output garbage. Investigation showed that the RAM requireements went up by 30 bytes. This probably caused the stack space to be reduced and stack overflow later on (I'm guessing)
    The send_miss function was revised to reduce the amount of RAM and the problem seems to have gone away.
    [compute_hit.ino]
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2024-01-19 ESP32 Corrected timer values
    Fixed the timer interval at 10ms (100 Hz) and made sure that all references in timer_new are expressed as ONE_SECOND * X
    [analog_io.c, gpio.c, serial_io.c]
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2024-02-23 ESP32 Self Test Corrections
    Arranged tasks so that when a test is enabled it takes control of the entire system
    [main.c]
2024-03-03 ESP32 Timer Bug Fix
    The timer would delete a timer after it had expired. The timer tick that monitored the run flip flops assumed that the timer had been retriggered. Consequently prior to fixing this bug the software would stop reporting shots after the second shot
    [analog_io.c, diag_tools.h, gpio.c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]
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2024-03-05 ESP32 Corrections for WiFi
    The WiFi was installed in the fall of 2023 and since that time some items had changed.
    This patch verifies the operation of the WiFI in both Station and Access Point modes
    [main.c]
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2024-04-14 ESP 5.0.1 Bug Fixes
    1 - Added MAC address to echo command
    2 - Corrected temperature calculations
    3 - Fixed fake target score when using the push buttons
    4 - Added MFS? to interrogate and set the MFS values
    5 - Modified json.c to allow echo and MFS? to have no arguments
    [analog_io.c]
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2024-05-07 ESP32 5.1.4 FIxing MFS
    The multifunction switches operated contrary to the V3.x software
    This patch made them work the same
    [gpio.c, gpio.h]
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2024-05-15 ESP32 5.1.5
    Addressing pcntHI counts when the high trigger is not detected and the pellet trap sets the counters to the wrong value.
    PCNT HI values over 200 are ignored
    [gpio.c]
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2024-05-27 ESP32 5.1.7 Fix receiving TCPIP messages
    The LWIP function recv() is a blocking call, meaning that when a socket is present and someone connects to it control halts until something arrives. This caused all input functions associated with the WiFi to stop working.
    This patch goes back to an earlier implementation with four separate functions that operate independently.
    [main.c, serial_io.c]
2024-05-30 ESP32 5.1.8 Motor self test fixed
    Corrected error in motor test that would only move the motor a few degrees.
    Revised paper_on_off function
    [gpio.c, gpio.h]
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2024-08-20 ESP32 V5.2.0 Initial Release
    Version 5.2.0 is a substantial change over 5.1.0 The changes are
    1 - Changes to the MFS to be easier to understand and set the changes
    2 - Changes to rapid fire to operate correctly
    3 - Completion of the stepper motor drive
    4 - Clean up of the WiFI driver to recognize dropped connections
    5 - Caching scores so that when connected over TCPIP the old scores are downloaded
    6 - Refactoring the sensor operation into a structure (class) to simplify the operation
    7 - Revising the serial I/O driver so that individual TCPIP ports can be written to instead of all of them
    8 - compute_hit.c revised to cache the last 100 shots
    9 - Streamlining the status LED drivers to be ea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
    [dac.c, diag_tools.h, gpio.c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]
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2024-09-03 ESP32 5.2.3 Changed paper motor drive
    The paper transport software was spagetti code that had been patched too many times to be understandable.
    This patch removes most of the paper drive software and replaces it with
    paper_start - Setup the internal variables and GPIOs to turn on the paper
    paper_drive - Called every 10ms to monitor the progress of the paper
    paper_stop - Ends the cycle\
    The paper_drive implements a ramp to speed up the motor at the start of the cycle
    [gpio.c, gpio.h]
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2024-09-14 ESP32 5.2.5 Refresh for new ESP32 development system
    AAAARGH!
    The ESP32 development system was refreshed and no longer worked with the old source files.
    Added feture to advance paper after json_paper_shot cycles.
    [analog_io.c, analog_io.h, dac.c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]
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2024-09-18 ESP32 5.2.6 Fixes for rapid fire
    Rapid fire is in two parts:
    The regular state machine to compute impacts,
    A second state machine to turn the lights on and off.
    Between the two of them are a number of semephores, shot_in and shot_out along with rapid_state. While int the RAPID_ON state, if there is a change in shot_n, then the hardware is reset and continues until the state changes to RAPID_SEND, at which point the accumulated shots are computed and sent.
    The DLT log levels were reorganized as:
    DLT_DIAG - Hardware related
    DLT_APPLICATION - Relates to freetarget.c and compute_hit.c
    DLT_DEBUG - General debugging not likely to be used more than once
    [diag_tools.h]
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2024-09-21 ESP32 5.2.7 Rapid Fire Fixes for Lights
    Revisions to support the Red and Green Lights.
    Discovered error in the gpio.h file that prevented the lights from working in the right order.
    Added rapid fire lights to the sefl test
    [diag_tools.h, gpio.c, gpio.h]
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2024-09-25 ESP32 5.2.8 Disable AUX Port
    The AUX port is an open connector that might experience noise injection. When this happens the hardware would go into a loop and stop working.
    The solution was to add the variable json_aux_port_enable to turn off the port if no hardware is attached.
    [serial_io.c]
2024-09-26 ESP32 2.5.9 Debugged Shots
    This change started to set the AUX port as an input unless overridden by json_aux_port_enable.
    During testing it was found that the sodfware would sometimes detect two shots. This patch fixes that
    [gpio.c, gpio_define.c, serial_io.c]
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2024-11-01 Simplified rapid fire
    Replaced code with a table
    Rapid fire task now only controls the LEDs.
    [diag_tools.h]
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2024-11-05 Revert "Merge branch 'ESP-5,2,13'"
    This reverts commit 36fbb5167b89738d6fe0320e7cfa0409670ce0eb, reversing
    changes made to f592b6990d8f3f8f44a65c366e1ec7316bd2b86f.
    [analog_io.c, analog_io.h, dac.c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]
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2024-11-22 Squashed commit of the following:
    commit 3fc3a6e4a313066f321cdf3ff4fd6b12d7983f33
    Author: Allan Brown <58998445+ten-point-nine@users.noreply.github.com>
    Date: Thu Nov 21 19:44:27 2024 -0600
    commit e9b70ac9ae59d71e2a06794ed1d12ce64e030c63
    Author: Allan Brown <58998445+ten-point-nine@users.noreply.github.com>
    Date: Tue Nov 19 17:15:46 2024 -0600
    Fixed up message on show stateus
    commit 1accecc5fca05d488117c20150458dc8793bba7e
    Author: Allan Brown <58998445+ten-point-nine@users.noreply.github.com>
    Date: Tue Nov 19 17:06:11 2024 -0600
    Addex Hex
    commit 782374a9e45793103e1eaefcc17af6586f8b1faa
    Author: Allan Brown <58998445+ten-point-nine@users.noreply.github.com>
    Da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
    [diag_tools.h, i2c.c]
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2024-12-28 Merging 5.2.18 from development
    Adding X and Y_OFFSET to calculations
    RUN_MASK now only looks at _LO signals
    is_running() now compated to #define, not explicit 0xff
    Added #defines for control signals
    Added diagnostics for missed shot
    Sensor GPIOs now accessed via a table and not explicit values
    IS_HOLD_C and IS_HOLD_D changed to remove == RAPID_GREEN etc
    Added callback to gpio_define
    GPIOs are now programmed in a sequence depending on type, ex OUT before IN
    Improved accuracy of sensor dia to 232 mm
    Added extra types to MFS_C
    Nonvol INIT now uses the JSON table in json.c to upgrade from persistent storage versions.
    PCNT modified to support selective enable of PCNT LO and HI
    Revised diagnostic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
    [analog_io.c, dac.c, diag_tools.h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]
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2025-01-27 ESP32 5.2.22 Compressing ECHO command
    The echo command was getting long and would no longer fit on a single screen.
    The change was to double up the lines so that one line displayed two parameters.
    Also, the JSON table was fixed up to remove poniters to double, and replace it with pointers to ints followed by casts to couble (couble). This was done to save on memory that was not really being used.
    [serial_io.c]
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2025-04-10 Squashed commit of the following:
    commit 04bfda680d1859b65c29af2c72087d4c7d804a50
    Date: Wed Apr 9 17:06:06 2025 -0500
    Progress
    commit 924f0af93e9f2af1aa9fc98f34f03dfb39091884
    Date: Wed Apr 9 09:59:33 2025 -0500
    Manual reset after OTA load
    commit 3f10d1b67759683e4697296f572949ad25a73485
    Date: Tue Apr 8 21:16:12 2025 -0500
    Works
    commit 164acc9ca1aa4833ec7fa74ff20e8334f7785a3c
    Date: Mon Apr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
    [partitions.csv]
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2025-06-13 Squashed commit of the following:
    commit 3b066b5f8d36a05e323024b051a86c71f161b04f
    Date: Thu Jun 12 21:19:22 2025 -0500
    fixed up json http
    commit 611d46746b70a6c82a9d038738063148a2c384f6
    Date: Tue Jun 10 21:11:55 2025 -0500
    Removed power on tracing
    commit bebbb2a1d4a941bb83710280db5b12a33c640fcc
    Date: Tue Jun 10 21:05:23 2025 -0500
    Server works like I expect it to
    commit 8943cf83142d4e306bbfe5a8c57284c28224c89c
    Author: Allan Brown <58998445+ten-point-nine@user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
    [50m Corners 2.stl, 50m Pistol 2.stl, 50m Pistol Corners 2.stl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]
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2025-06-23 Merged 6.1.14
    Added mDNS
    Fixed up HTML
    Simplified compute_hit.c
    Fixed bug in rapid fire
    [diag_tools.h, gpio.c, gpio.h]
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
